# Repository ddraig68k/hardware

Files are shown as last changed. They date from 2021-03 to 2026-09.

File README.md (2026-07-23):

# CAD files for Y Ddraig

This repository contains the Schematics and any other relevant files for a [Motorola 68000 computer](https://ddraig68k.com) in KiCAD format. The files for the main computer boards as well as any of the expansion boards are present in the repository.

The libraries used in the project are contained in the ddraig-libs folder inside the repo, to use them in KiCAD, go to Configure Paths and add a custom path DDRAIGLIB which points to the ddraig-libs folder.

## Y Ddraig

Welsh for *The Dragon*, Y Ddraig is my [Motorola 68000](https://en.wikipedia.org/wiki/Motorola_68000) computer. 

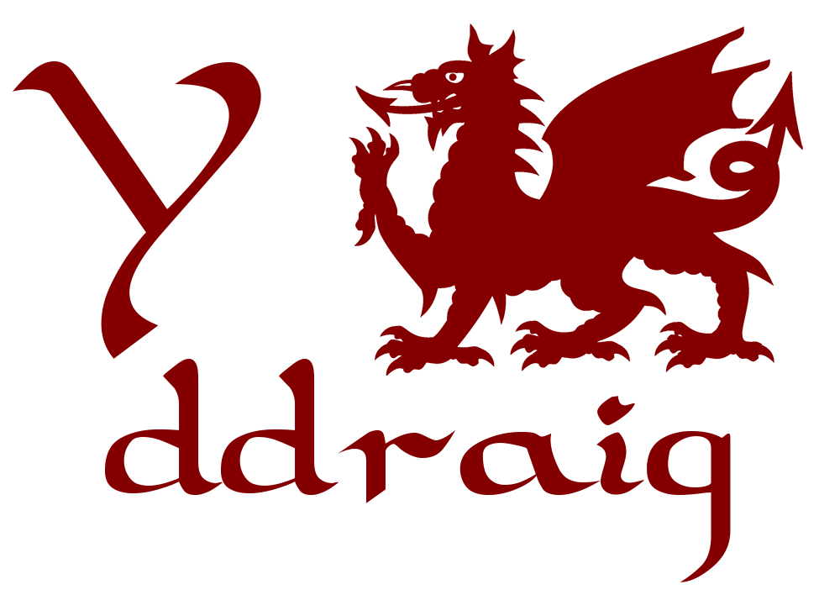
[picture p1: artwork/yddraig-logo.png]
Y Ddraig

| **Specifications** |
|-|
|68000 CPU running at 10Mhz.|
|512K EEPROM |
|1M of Static RAM|
|8M Dynamic RAM|
|2 Serial ports|
|Parallel port|
|PS/2 keyboard and mouse|
|IDE interface|
|Real-time clock|
|4 Expansion slots|

<br />

# Design Files
[Y Ddraig 68000 PCB](yddraig)

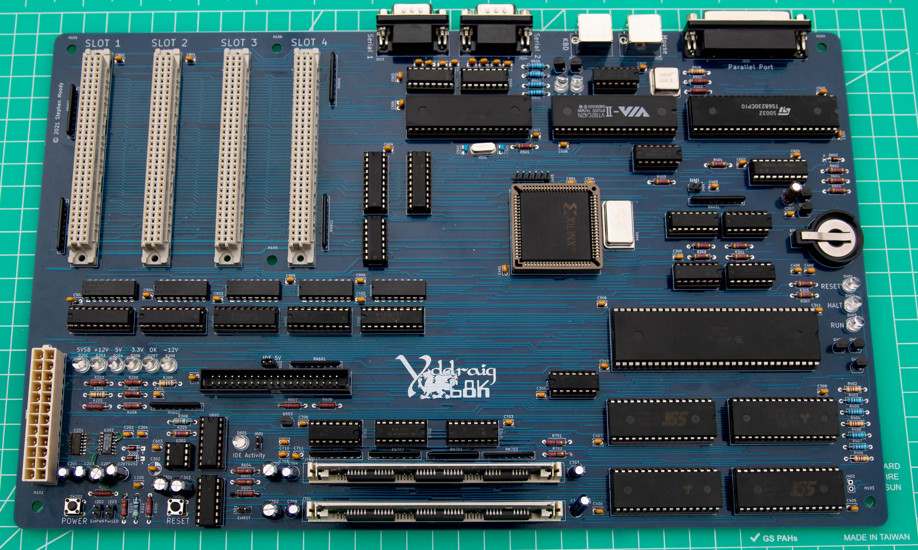
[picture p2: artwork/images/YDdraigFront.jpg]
Y Ddraig main pcb


**Expansion Cards**

* [Dual SID Audio card](expansion/AudioSID) - two MOS 6581/8580 SID chips for Commodore 64 style audio

* [YM2151 Audio card](expansion/AudioYM2151) - Yamaha FM synthesis chip as used in many arcade games

* [RTL8019 Ethernet card](expansion/Eth8019) - 10BASE-T Ethernet using the Realtek RTL8019AS

* [TMS9918 Graphics card](expansion/GfxTMS9918) - the video chip used in the Sega SG-1000, ColecoVision and MSX1

* [V9958 Graphics card](expansion/GfxV9958) - Yamaha's successor to the TMS9918, as used in the MSX2+

* [V9990 Graphics card](expansion/GfxV9990) - Yamaha's follow up to the V9958 with higher resolutions

* [VGA Graphics card](expansion/GfxVGA) - FPGA based VGA video generation

* [Sega Megadrive joypad card](expansion/JoypadController) - reads standard 3 or 6-button Sega Megadrive/Genesis controllers

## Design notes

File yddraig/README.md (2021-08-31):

## Y Ddraig hardware

### CPU, RAM and ROM

The CPU used by Y Ddraig is the [Motorola 68000](https://en.wikipedia.org/wiki/Motorola_68000) running at 10 MHz. The 68000 has a 16-bit data bus and 24-bit address bus internally runs as a full 32-bit machine. The 68000 has 8 general purpose data registers *D0-D7* and 8 address registers *A0-A7*. The address register A7 is also used as a special purpose register holding the *stack pointer*.

There is 512K of EEPROM available supplied by two 256K x 8-bit SST39SF020 devices for the ODD and EVEN addresses.

RAM is provided by two 512K x 8-bit AS6C4008 Static RAM devices giving a total of 1024K of available memory. There is also the option of adding an additional Dynamic RAM to expand the memory up to a total of 9MB.

### Memory Mapping

As the 68000 is a memory mapped device the address decoding is handled by a Xilinx XC95C108 CPLD. In addition to the address decoding the CPLD is also used as the DRAM controller.

The memory map is as follows:

| Device | Start Address | End Address |
|-|-|-|
| Static Ram | 0x000000 | 0x0FFFFF |
| Dynamic RAM | 0x100000 | 0x900000 |
| Slot1 Data | 0xA00000 | 0xAFFFFF |
| Slot2 Data | 0xB00000 | 0xBFFFFF |
| Slot3 Data | 0xC00000 | 0xCFFFFF |
| Slot4 Data | 0xD00000 | 0xDFFFFF |
| DUART | 0xF7F000 | 0xF7F0FF |
| PIT | 0xF7F100 | 0xF7F1FF |
| KBD | 0xF7F200 | 0xF7F2FF |
| IDE | 0xF7F300 | 0xF7F3FF |
| RTC | 0xF7F400 | 0xF7F4FF |
| Slot1 | 0xF7F500 | 0xF7F5FF |
| Slot2 | 0xF7F600 | 0xF7F6FF |
| Slot3 | 0xF7F700 | 0xF7F7FF |
| Slot4 | 0xF7F800 | 0xF7F8FF |
| ROM | 0xF80000 | 0xFFFFFF |

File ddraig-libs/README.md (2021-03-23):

# KiCAD Library files

Collections of library files for use in KiCad

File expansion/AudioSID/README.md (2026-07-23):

# Dual SID Audio Card

The [MOS 6581/8580 SID](https://en.wikipedia.org/wiki/MOS_Technology_SID) is the sound chip used in the Commodore 64, with 3 independent oscillators, multiple waveforms, ADSR envelopes and a multi-mode filter giving it its distinctive sound.

This card has two SID sockets, each jumper-selectable between the original 6581 and the later 8580 variant, since the two chips have different characteristics - the 8580 cleaned up some of the 6581's non-linearities and runs from a 9V analog supply rather than the 6581's 12V. The board provides both rails, with an L7809 regulator supplying the 9V needed by the 8580.

A Xilinx XC9536PC44 CPLD handles address decoding and chip select generation for both SID sockets. Each SID has its own volume potentiometer for mixing before the two channels are combined into a single audio output, with a separate analog supply and ground plane to help keep noise out of the signal.

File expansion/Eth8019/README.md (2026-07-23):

# RTL8019 Ethernet Card

The Realtek RTL8019AS is a fully integrated, single-chip [NE2000](https://en.wikipedia.org/wiki/NE2000)-compatible Ethernet controller with an 8/16-bit ISA-style bus interface and an integrated packet buffer, which makes it straightforward to attach to a simple non-DMA host bus like the 68000's.

A Xilinx XC9536PC44 CPLD provides the address decoding and glue logic between the expansion bus and the RTL8019AS, including the IOCS16B signalling used to negotiate 8/16-bit bus width with the host, as on ISA NE2000 cards.

The card has an RJ45 jack with integrated magnetics for the 10BASE-T connection, link/activity LEDs, and a JTAG header for programming the CPLD.

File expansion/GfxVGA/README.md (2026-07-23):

# VGA Graphics Card

Unlike the other graphics expansion cards, which are each built around a dedicated video chip from the 1980s/90s, this card generates video directly from a Xilinx Spartan-6 XC6SLX9-TQG144 FPGA, giving full control over the display timing and pixel generation logic instead of relying on a fixed-function chip.

An IS61WV102416FBLL 1M x 16-bit SRAM provides the frame/video memory for the FPGA. Configuration is loaded from a W25Q64JVSSIM SPI flash at power-up, so the board doesn't need to be reprogrammed each time it starts, though the FPGA can also be programmed directly over JTAG during development.

Since the FPGA core runs at a lower voltage than the rest of the board, an LD1117S12TR regulator supplies the 1.2V core rail, while buffer/level-shifting logic (74LS125, 74LS157, SN74LVC8T245) bridges the 3.3V FPGA I/O to the 5V expansion bus. Video is output through a standard DE15 VGA connector.

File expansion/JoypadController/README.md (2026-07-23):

# Sega Megadrive Joypad Card

This card provides two DB9 ports for connecting standard 3-button Sega Megadrive/Genesis joypads.

A Sega pad multiplexes its buttons across a handful of pins, switched by the SELECT line - reading Up/Down/Left/Right and its face buttons in two passes rather than needing a pin per button. Both the Left and Right lines being pulled low at the same time is how the host detects that a pad is actually connected to a port.

A Xilinx XC9536PC44 CPLD drives the SELECT line for both ports and latches the resulting button states through a 74LS574 octal latch so they can be read by the host as memory-mapped registers, with 74LS125 buffers isolating the pad inputs from the expansion bus. A JTAG header is provided for programming the CPLD.

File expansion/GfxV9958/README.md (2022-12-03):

# V9958 Video Card

The Yamaha V9958 is the successor to the V9938 and TMS9918 that were commonly used in the MSX computer line with the V9958 appearing in the MSX2+. 

It has the following specifications:
* VRAM: 128 KB + 64 KB of expanded VRAM
* Text modes: 80 x 24 and 32 x 24
* Resolution: 512 x 212 (16 colors out of 512) and 256 x 212 (19268 colors)
* Sprites: 32, 16 colors, max 8 per horizontal line
* Hardware acceleration for copy, line, fill, etc.
* Interlacing to double vertical resolution
* Horizontal and vertical scroll registers 

The board has 3 different outputs. A composite output, S-Video output and a [Xrgb Mini RGB](https://www.retrorgb.com/retro-gaming-cables-now-offering-8pin-minidin-scart-cables.html) compatible 8-pin mini DIN output aimed at SCART use. There is also an optional audio jack input that can supply audio the 8-pin din output so TV speakers can be used rather than an external speaker.

The V9958 board has 192K of RAM installed and uses a CXA2075M encoder to provide the video output signals. 

**V9958 Text Mode**
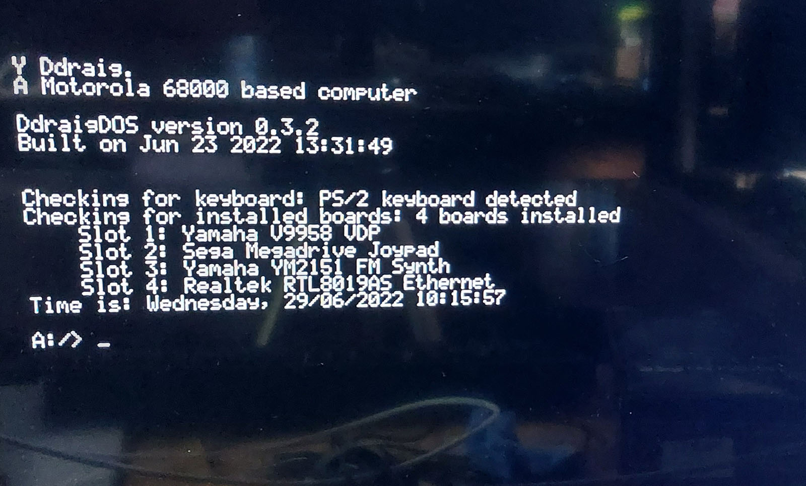
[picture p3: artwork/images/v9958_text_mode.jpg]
V9958 Text Mode


**V9958 Mandelbrot**
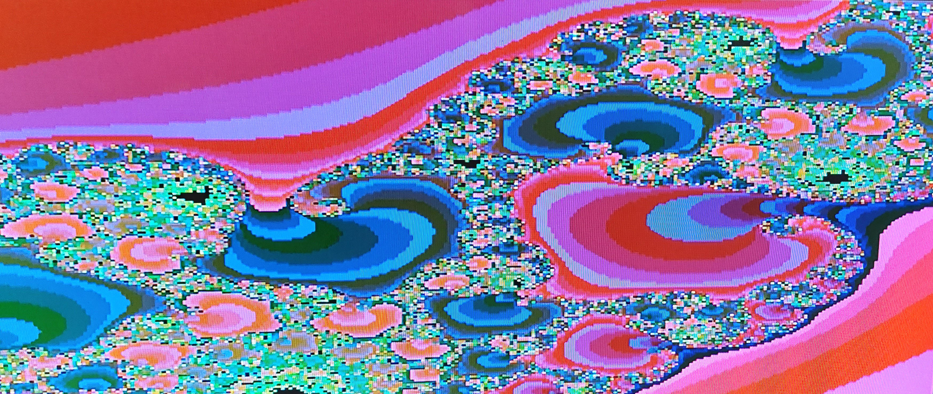
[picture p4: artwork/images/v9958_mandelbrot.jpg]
V9958 Mandelbrot


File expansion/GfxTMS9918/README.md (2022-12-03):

# TMS9918 Video card

The TMS9918A is capable of a 256x192 pixel display with a 15 colour palette. It has 16K of video memory and 4 different video modes.

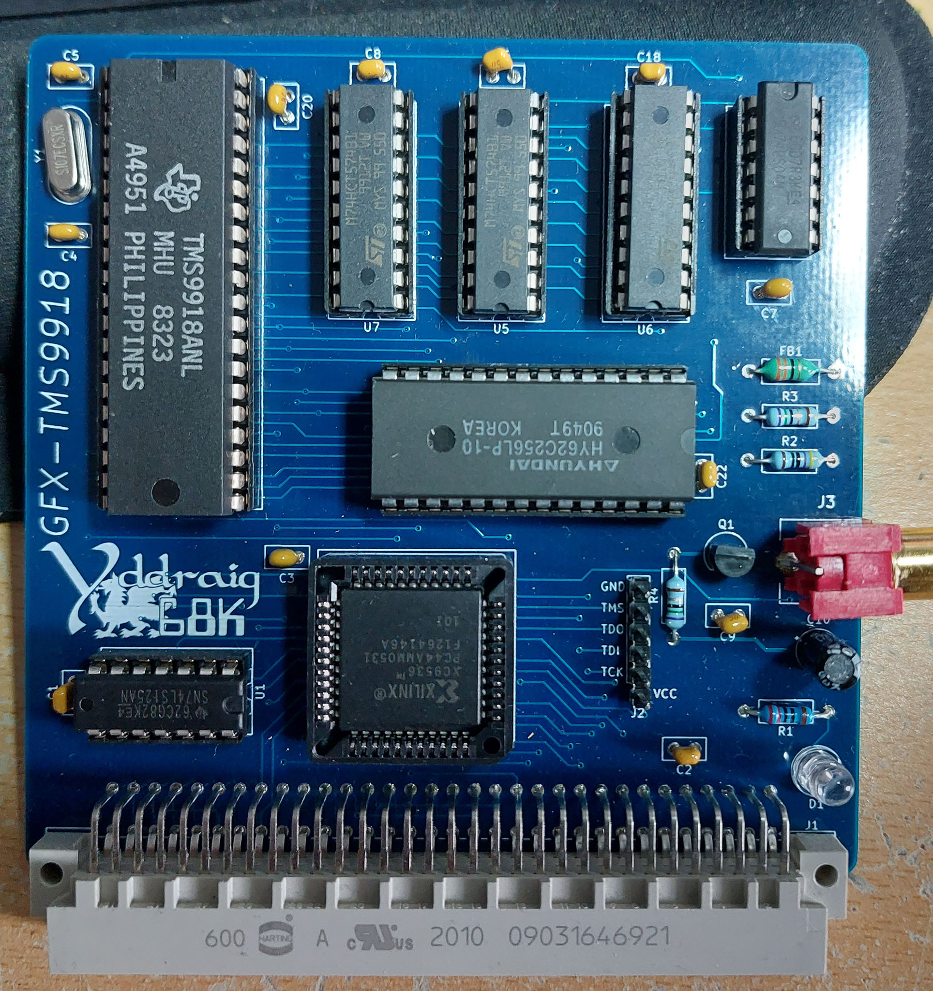
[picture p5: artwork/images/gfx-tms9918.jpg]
TMS9918 Video Card


From the [Sega Retro](https://segaretro.org/TMS9918) site:

>There are 4 different screen modes available in the TMS9918A (as mentioned before, the TMS9918 lacks mode Graphic II):
>
>Mode 0 (Text): 40×24 characters monochrome. As the display is 256 pixels width, the character set is only 6 pixels wide. This mode doesn't support sprites, nor a separate border color setting.
>
>Mode 1 (Graphic 1): 32×24 characters (256×192 bitmap), where for each 8 characters in the character set the foreground and background color can be set. The chars "0"-"7" for example all have the same attributes.
>
>Mode 2 (Graphic 2): 32×24 characters (256×192 bitmap), with a 2-color limitation for each 8 pixel wide line inside a character.
>
>Mode 3 (Multicolor): 64×48 mode, very blocky and rarely used. Each 'pixel' can have its own color defined though, hence the name. Its sprites still have the same resolution as in screen modes 1 and 2.
>
>The TMS9918 has a fixed 16-color palette (actually 15 colors + transparent). 

The TMS9918A was designed to use DRAM, but I have used the design by [Leonardo Miliani](https://www.leonardomiliani.com/en/2019/lm80c-tms9918a/) that allows SRAM to be used instead.

The TMS9918 can also display up to 32 sprites (4 per scanline).

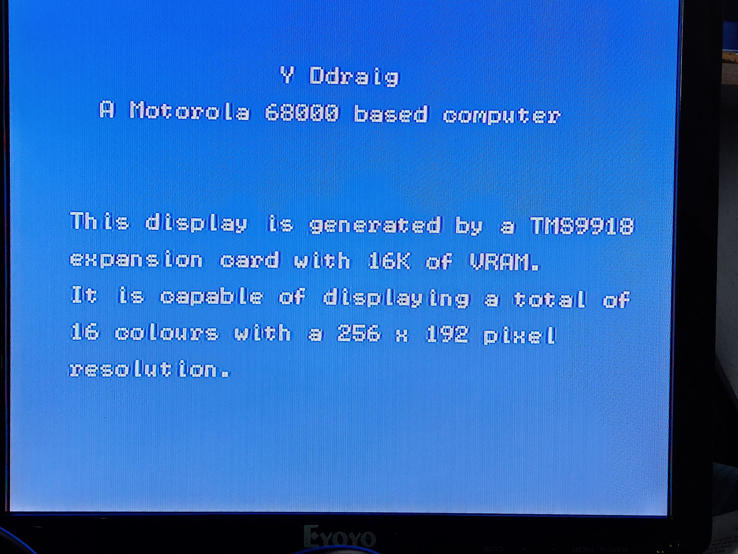
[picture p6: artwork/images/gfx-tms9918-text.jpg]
TMS9918 text mode


[Plasma effect on the TMS9918](https://www.youtube.com/watch?v=u6DVTGFEivY)

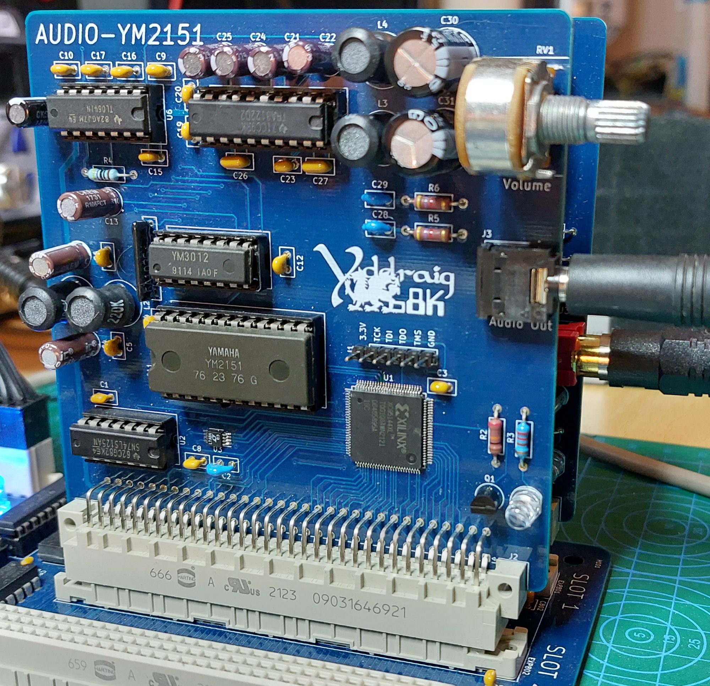
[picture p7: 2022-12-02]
artwork/images/YM2151Card.jpg

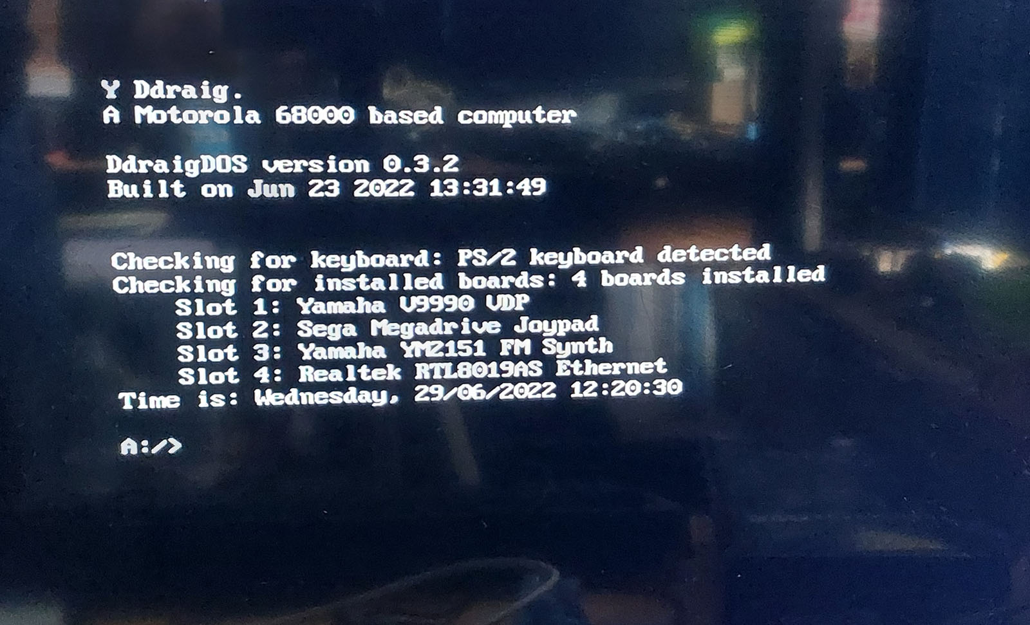
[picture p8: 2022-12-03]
artwork/images/v9990_text_mode.jpg

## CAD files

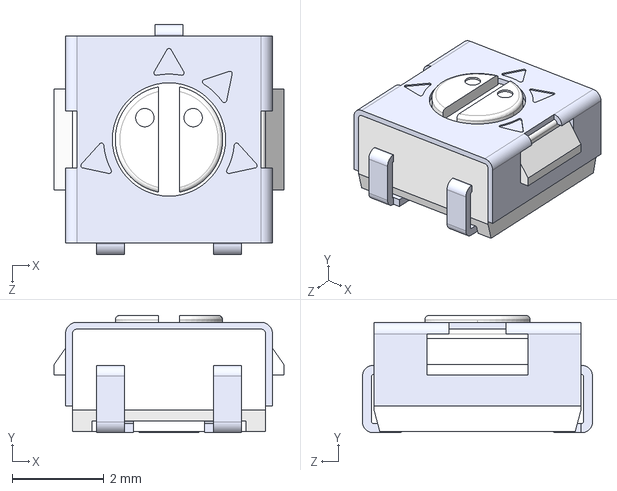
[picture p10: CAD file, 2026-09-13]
ddraig-libs/CAD/Components/3314J-1-202E.step
5.00 x 2.55 x 5.00 mm

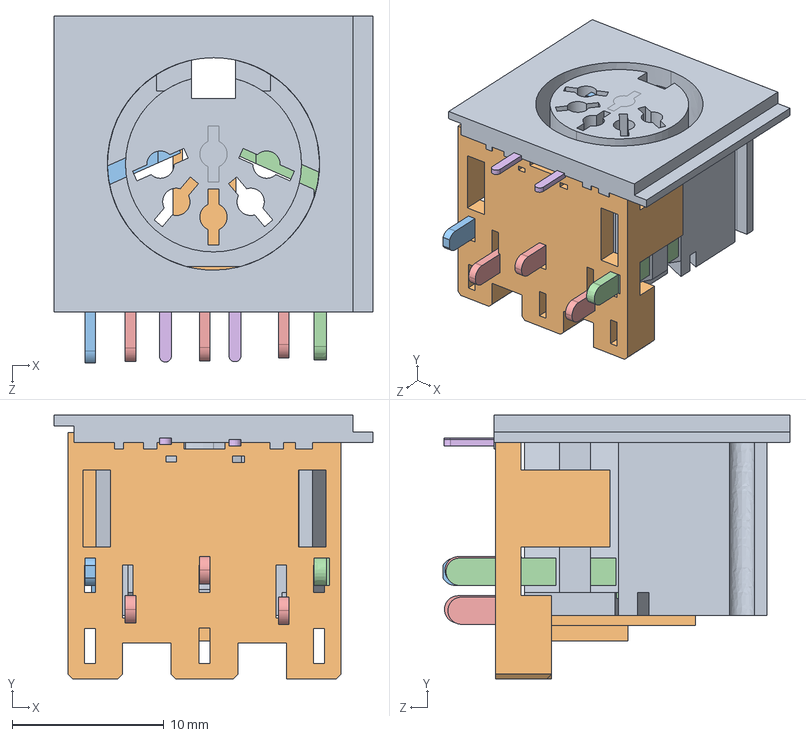
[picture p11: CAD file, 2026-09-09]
ddraig-libs/CAD/Connectors/lumberg_0105_05.stp
21.0 x 17.4 x 22.9 mm
PRT0017
PRT0018
PRT0019
PRT0020
PRT0021
PRT0022
PRT0022_1
PRT0023
PRT0024

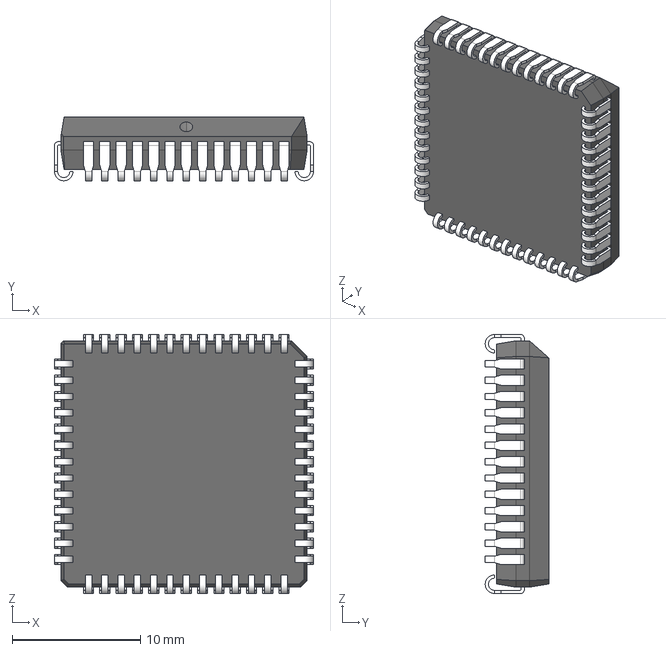
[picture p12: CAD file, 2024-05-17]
ddraig-libs/CAD/IC Sockets/plcc52_p1-27_l19-2_w19-2.stp
20.2 x 4.96 x 20.2 mm

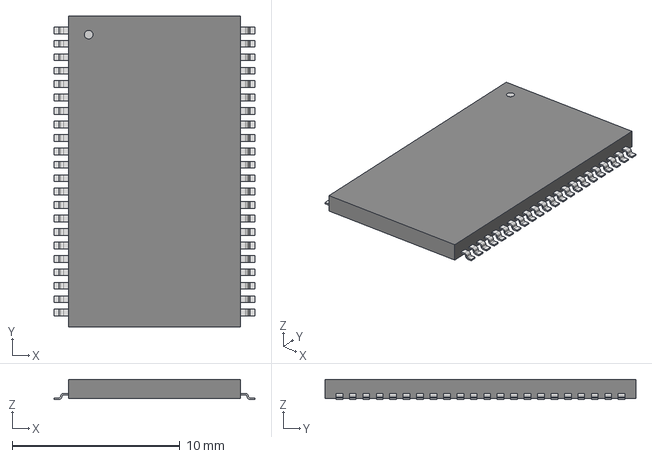
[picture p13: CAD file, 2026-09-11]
ddraig-libs/CAD/ICs/TSOP-44.step
11.9 x 18.5 x 1.20 mm

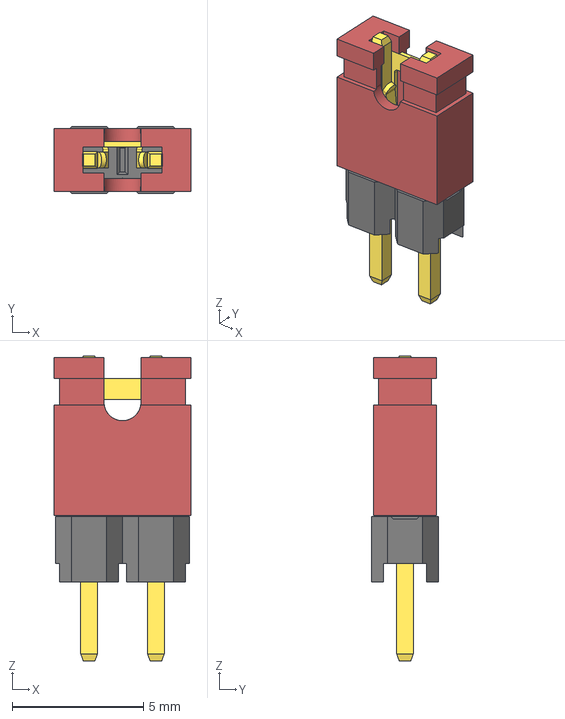
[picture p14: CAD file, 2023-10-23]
ddraig-libs/CAD/Jumpers/Jumper2-red.step
5.20 x 2.54 x 11.6 mm

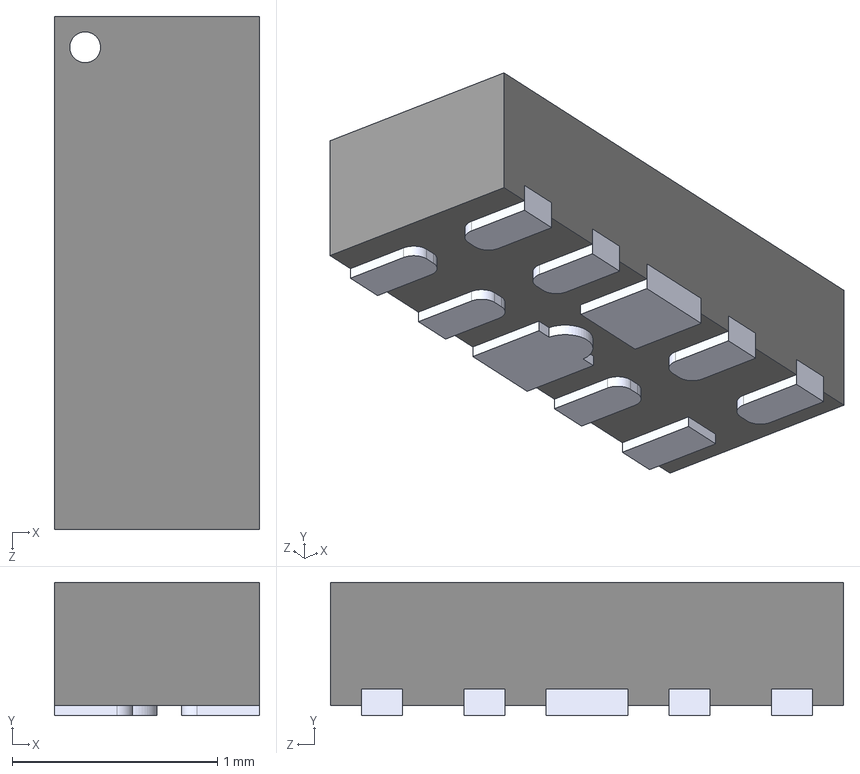
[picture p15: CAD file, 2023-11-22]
ddraig-libs/CAD/Components/RCLAMP0524PATCT.step
1.00 x 0.65 x 2.50 mm

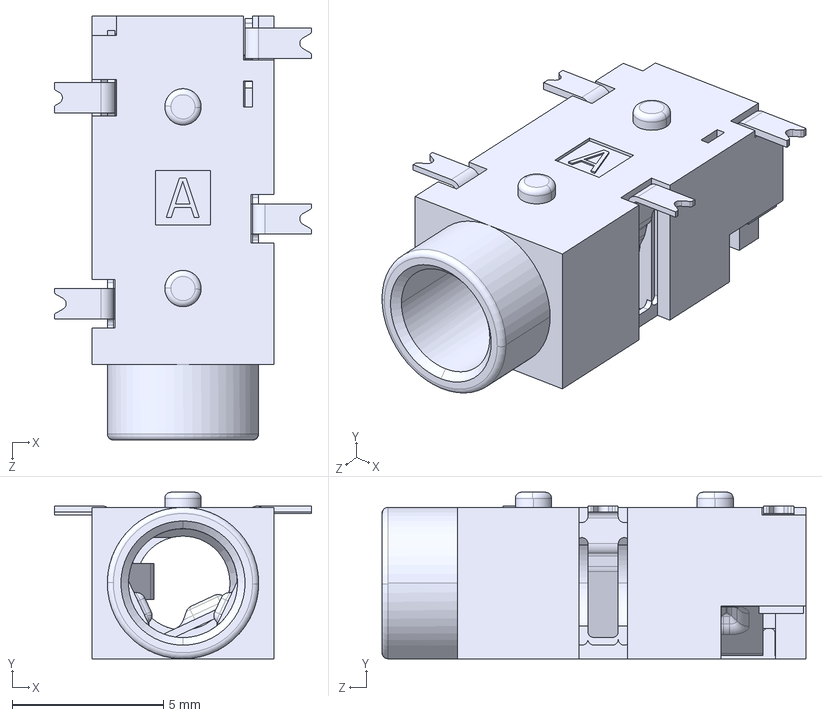
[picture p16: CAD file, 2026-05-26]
ddraig-libs/CAD/Connectors/SJ2-35813B-SMT-TR.step
8.50 x 5.50 x 14.0 mm

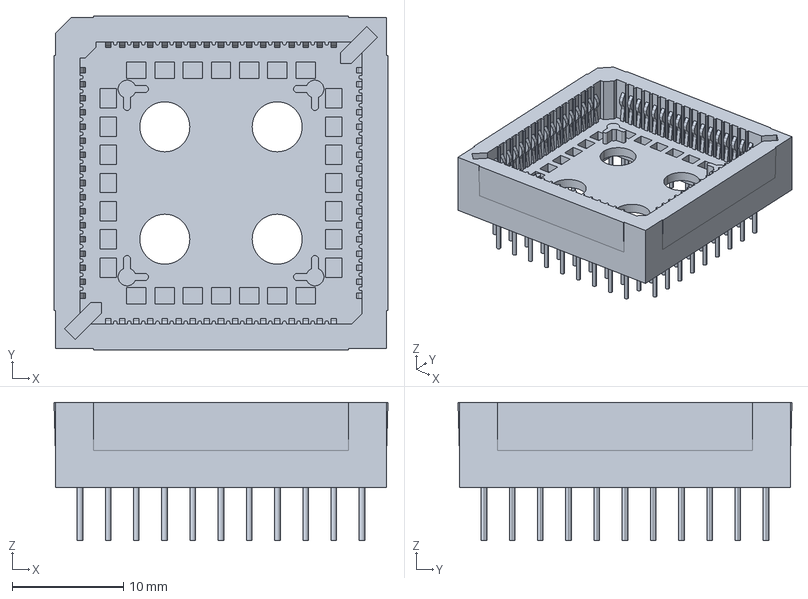
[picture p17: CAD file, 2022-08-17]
ddraig-libs/CAD/IC Sockets/PLCC68 Socket.stp
30.1 x 30.1 x 12.4 mm

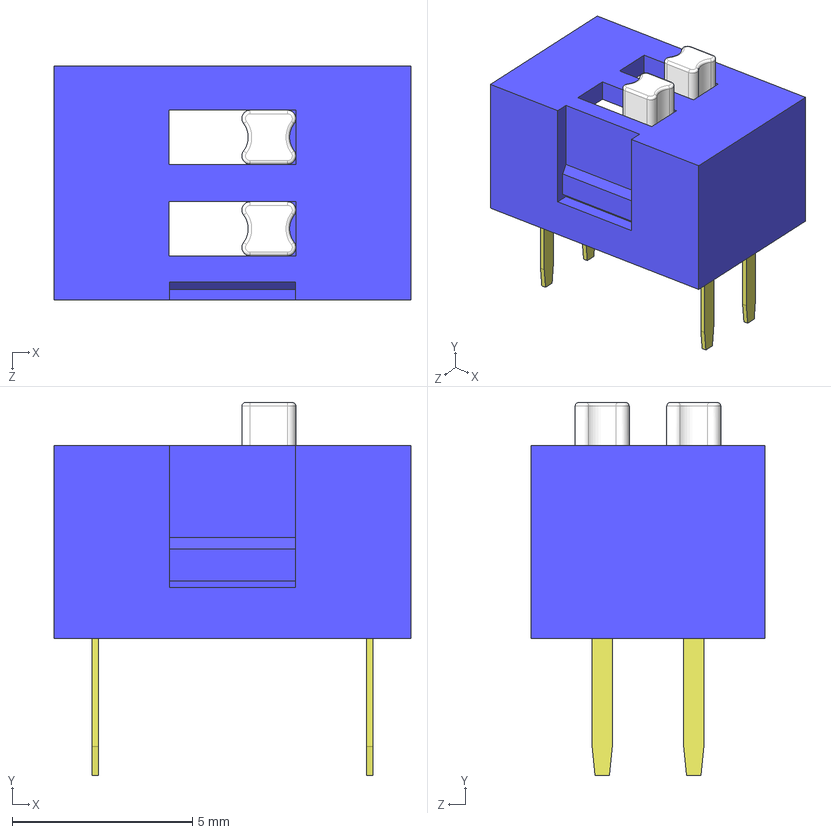
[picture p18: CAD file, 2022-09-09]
ddraig-libs/CAD/Components/CUI_DEVICES_DS01-254-L-02BE.step
9.90 x 10.4 x 6.50 mm

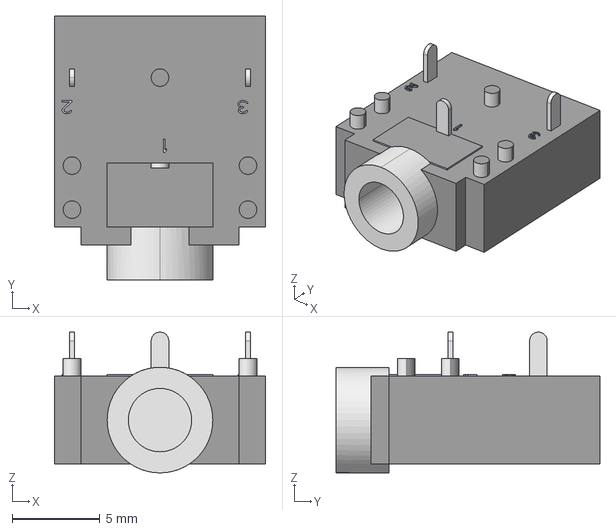
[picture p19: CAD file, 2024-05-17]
ddraig-libs/CAD/Connectors/35RAPC2BHN2.step
12.0 x 15.0 x 8.00 mm

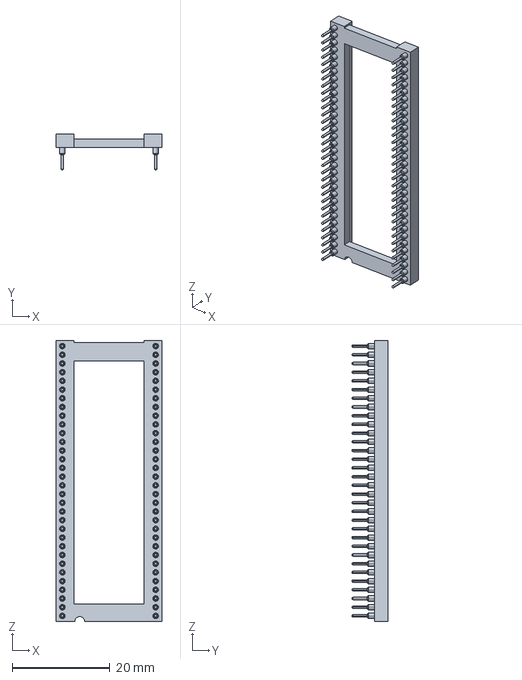
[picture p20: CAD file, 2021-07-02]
ddraig-libs/CAD/IC Sockets/dil_socket_117-87-764-41-005101.stp
21.6 x 7.40 x 57.4 mm

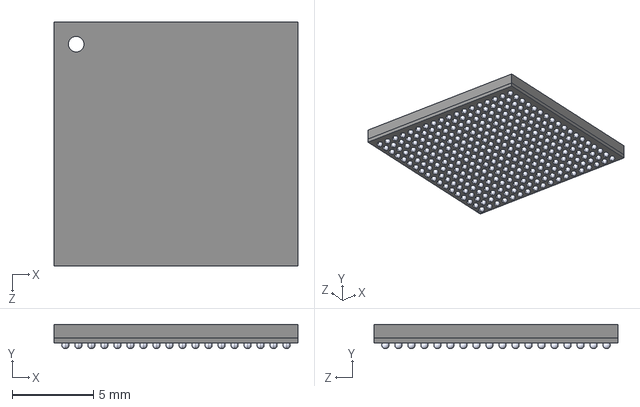
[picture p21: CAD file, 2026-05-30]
ddraig-libs/CAD/ICs/XC7S50-1CSGA324Q.STEP
15.0 x 1.50 x 15.0 mm

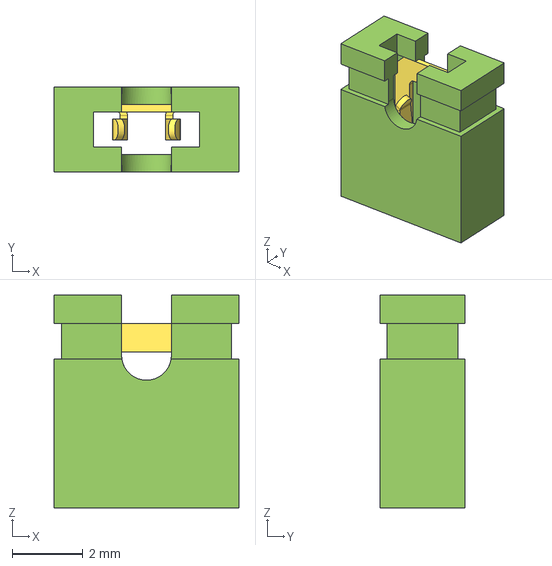
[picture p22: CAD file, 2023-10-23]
ddraig-libs/CAD/Jumpers/Jumper-green.step
5.20 x 2.40 x 6.00 mm

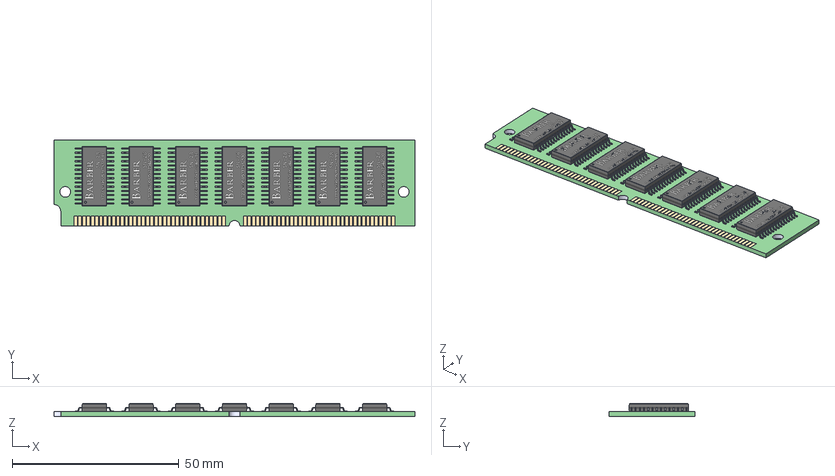
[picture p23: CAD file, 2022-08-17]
ddraig-libs/CAD/Components/72pin-simm.step
108.2 x 25.7 x 3.76 mm
simmbody
simmpin x 72
sn28body x 7
sn28pin x 196

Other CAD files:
ddraig-libs/CAD/Jumpers/Jumper2-yellow.step
ddraig-libs/CAD/Connectors/35RAPC4BHN2.step
ddraig-libs/CAD/IC Sockets/plcc44_p1-27_l16-66_w16-66.stp
ddraig-libs/CAD/Jumpers/Jumper3-yellow.step
ddraig-libs/CAD/Components/3306F001.stp
ddraig-libs/CAD/Components/ACH.STEP
ddraig-libs/CAD/Components/AIUR-02H.STEP
ddraig-libs/CAD/Components/AIUR-16.STEP
ddraig-libs/CAD/Components/AOCJY1.STEP
ddraig-libs/CAD/Components/DOUBLE POTENTIOMETER.stp
ddraig-libs/CAD/Components/ECS-3963-BN-TR.step
ddraig-libs/CAD/Components/IS61WV102416FBLL-10TLI.stp
ddraig-libs/CAD/Components/M2022TXW41-DA.stp
ddraig-libs/CAD/Components/MAX3420EECJ_.step
ddraig-libs/CAD/Components/SN74LVC8T245PWR.step
ddraig-libs/CAD/Components/SOT230P700X180-4N.step
ddraig-libs/CAD/Components/XTAL2.STEP
ddraig-libs/CAD/Connectors/145638009211859_.step
ddraig-libs/CAD/Connectors/57PC5F.step
ddraig-libs/CAD/Connectors/5822021-4.stp
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

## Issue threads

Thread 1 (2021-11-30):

PCB for sale?

bzuidgeest, 2021-11-30:
Much of this looks excellent to me. Still have to look at the details, but ticks many boxes, easy expansion, dram and simms mostly of the shelf chips for serial and such, cpu with excellent gcc support. etc

Could you give an indication as to what the component cost is? Does not need be exact. And though I should be able to copy this from repo and order everything myself I thought I could ask if you have PCB's for sale.

ddraig68k, 2021-11-30:
I don't have any boards for sale at the moment, there was a few mistakes on the PCB which have been resolved in the design, with the exception of issue #2 but I don't have any of the boards with fixes on them made yet.

It's hard to say what the component costs are. Many of the parts have been reused from previous boards or it's parts that I had here anyway.

The cost of the PCB is approximately $80 for 5 on JLCPCB.  Because everything socketed, it's probably around $150 spent on parts other than the old parts like the 68000 and other devices, most of which were from UTSource. I'll try to put a more detailed BOM together when I get a chance.

bzuidgeest, 2021-12-01:
No problem, if you could push any fixes made into the kicad drawings/pcb in the repo.
I could have my own made. And yes I know the risks in doing that :). I know this is not a commercial product. Or if your planning to order in the near future I could exercise some patience.

I'm trying to find a board with the right balance of retro, convenience, openness (and yes price) to fit my needs of wanting to toy with some of the old retro chips without any OS in the way. Tried the c256Foenix. Nice board, but all fpga and those are closed source, everything and the kitchen sink build in and expensive. Build an rosco-m68K next. Open, but to simple.. Yours seems to fall in between. And you already have an impressive set of add on boards. (that are at least in testing). But the four slots make tinkering easy.

ddraig68k, 2021-12-01:
The incorrect DTACK on the expansion bus has been fixed and the latest files are in the repo now.

I will probably order some new PCBs at some point as it would be nice to have a final board built up with all the fixes on there. I need to check out all the expansion boards as well before ordering new so it may not be until after that point.

The original version of the computer I did was a single board design with everything on it. The main reason I changed the design to use the expansion slots instead was to allow tinkering with different designs. I like being able to try some of the old graphics and sound chips of old computer systems and this computer allows be to do just that.

bzuidgeest, 2021-12-01:
"The main reason I changed the design to use the expansion slots instead was to allow tinkering with different designs."

The main reason for me to look at a project like this. Closed source fpga on sbc's are just annoying. Not that I know much about vhdl, but I should at least be able to tinker with them.

I'm closing this for now. Thanks for pushing the latest files.

Closed 2021-12-01.

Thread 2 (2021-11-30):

Possible error in schematic

bzuidgeest, 2021-11-30:
This might be old news to you but when looking at the published schematics for expansion slot 4 I noticed that DTACK_EXT4 is connected to the IRQ pin on slot 4. I read that interrupt on slot 4 is not supported. By the looks of it because you ran out of room on the encoder. However that does not give me a reason to connect dtack to the IRQ pin, so for the moment I am assuming that is an error. Do correct me if I am wrong.

ddraig68k, 2021-11-30:
That is an error, DTACK_EXT4 should not be connected to the IRQ slot. Thanks, missed that and not tested any boards in slot 4 yet so haven't noticed it. I'll get that one fixed.

You're correct about the lack of IRQ on slot 4, there wasn't a spare IRQ on the encoder. I had considered putting a shared IRQ on slots 3 and 4, but decided against it.

Closed 2021-12-01.

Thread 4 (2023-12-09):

Schematic label typo  DATCK_EXT should be DTACK_EXT on U402B pin 5

vermeerpaul, 2023-12-09:
A possible disconnect of PIN 5 U402B DTACK_EXT. See file Schematic yddraig-schematic.pdf.
It has a typo in the label.

vermeerpaul, 2023-12-09:
Seems to be resolved 1-level up on the sheet connection. DTACK <->DATCK.

Closed 2023-12-09.

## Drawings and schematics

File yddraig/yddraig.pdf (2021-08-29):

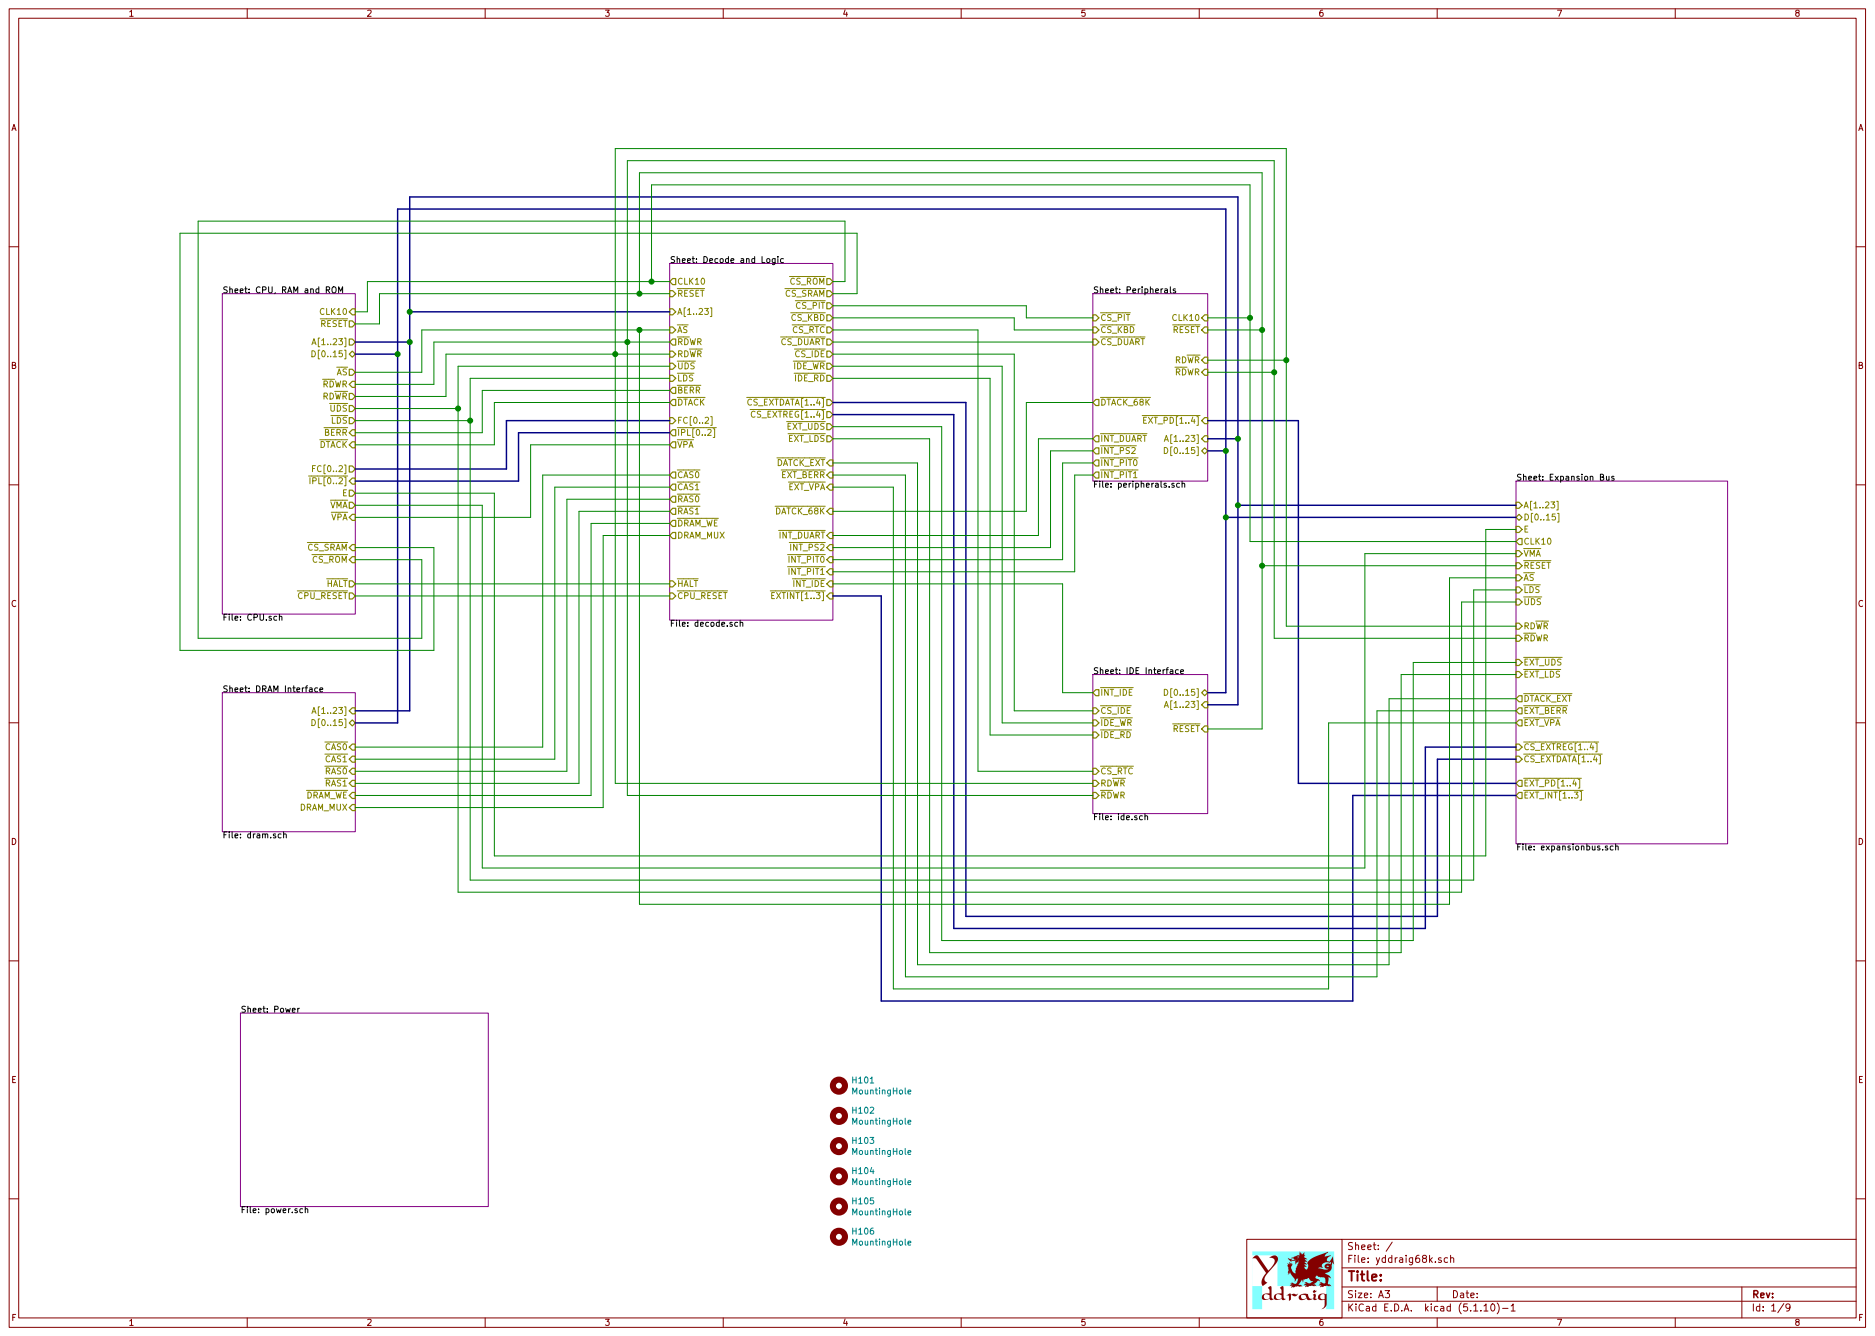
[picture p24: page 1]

Sheet: Decode and Logic File: decode.sch CLK10 RESET A[1..23] ASRDWR

Sheet: CPU, RAM and ROM
CLK10 VPA RESET CS_SRAM
DTACK HALT CPU_RESET RDWR
LDS RDWR

Sheet: Expansion Bus
A[1..23] VMA
File: expansionbus.sch DTACK_EXT D[0..15] CLK10 RESET AS
EXT_VPA E

INT_PIT1 Sheet: Power File: power.sch

H106 MountingHole H105 MountingHole H104 MountingHole H103 MountingHole H102 MountingHole H101 MountingHole

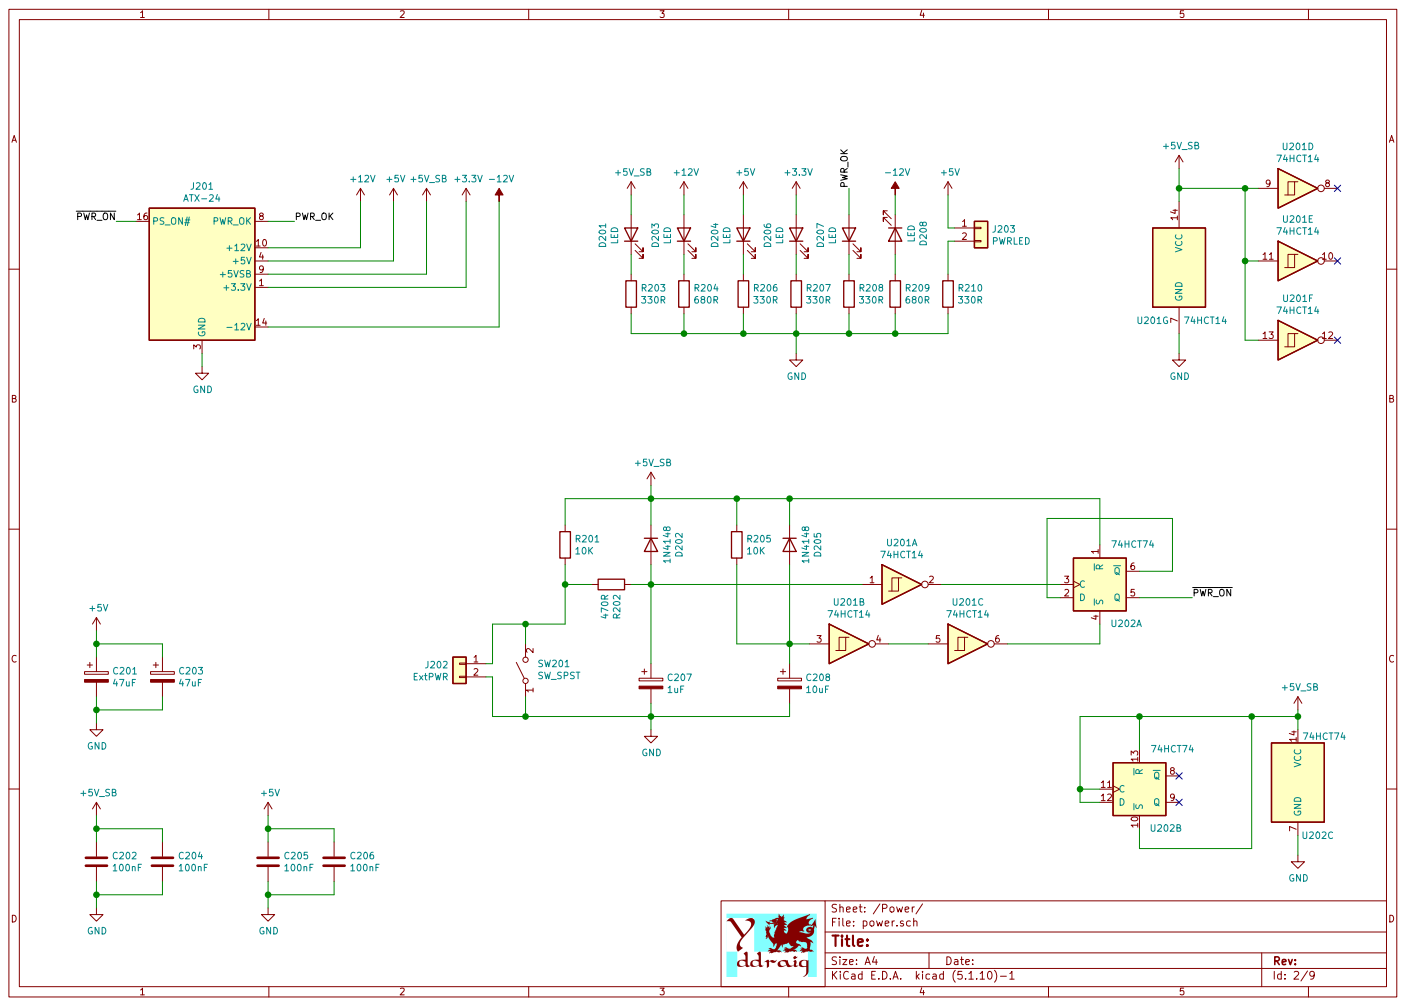
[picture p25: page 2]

File: power.sch Sheet: /Power/
Id: 2/9 Title:

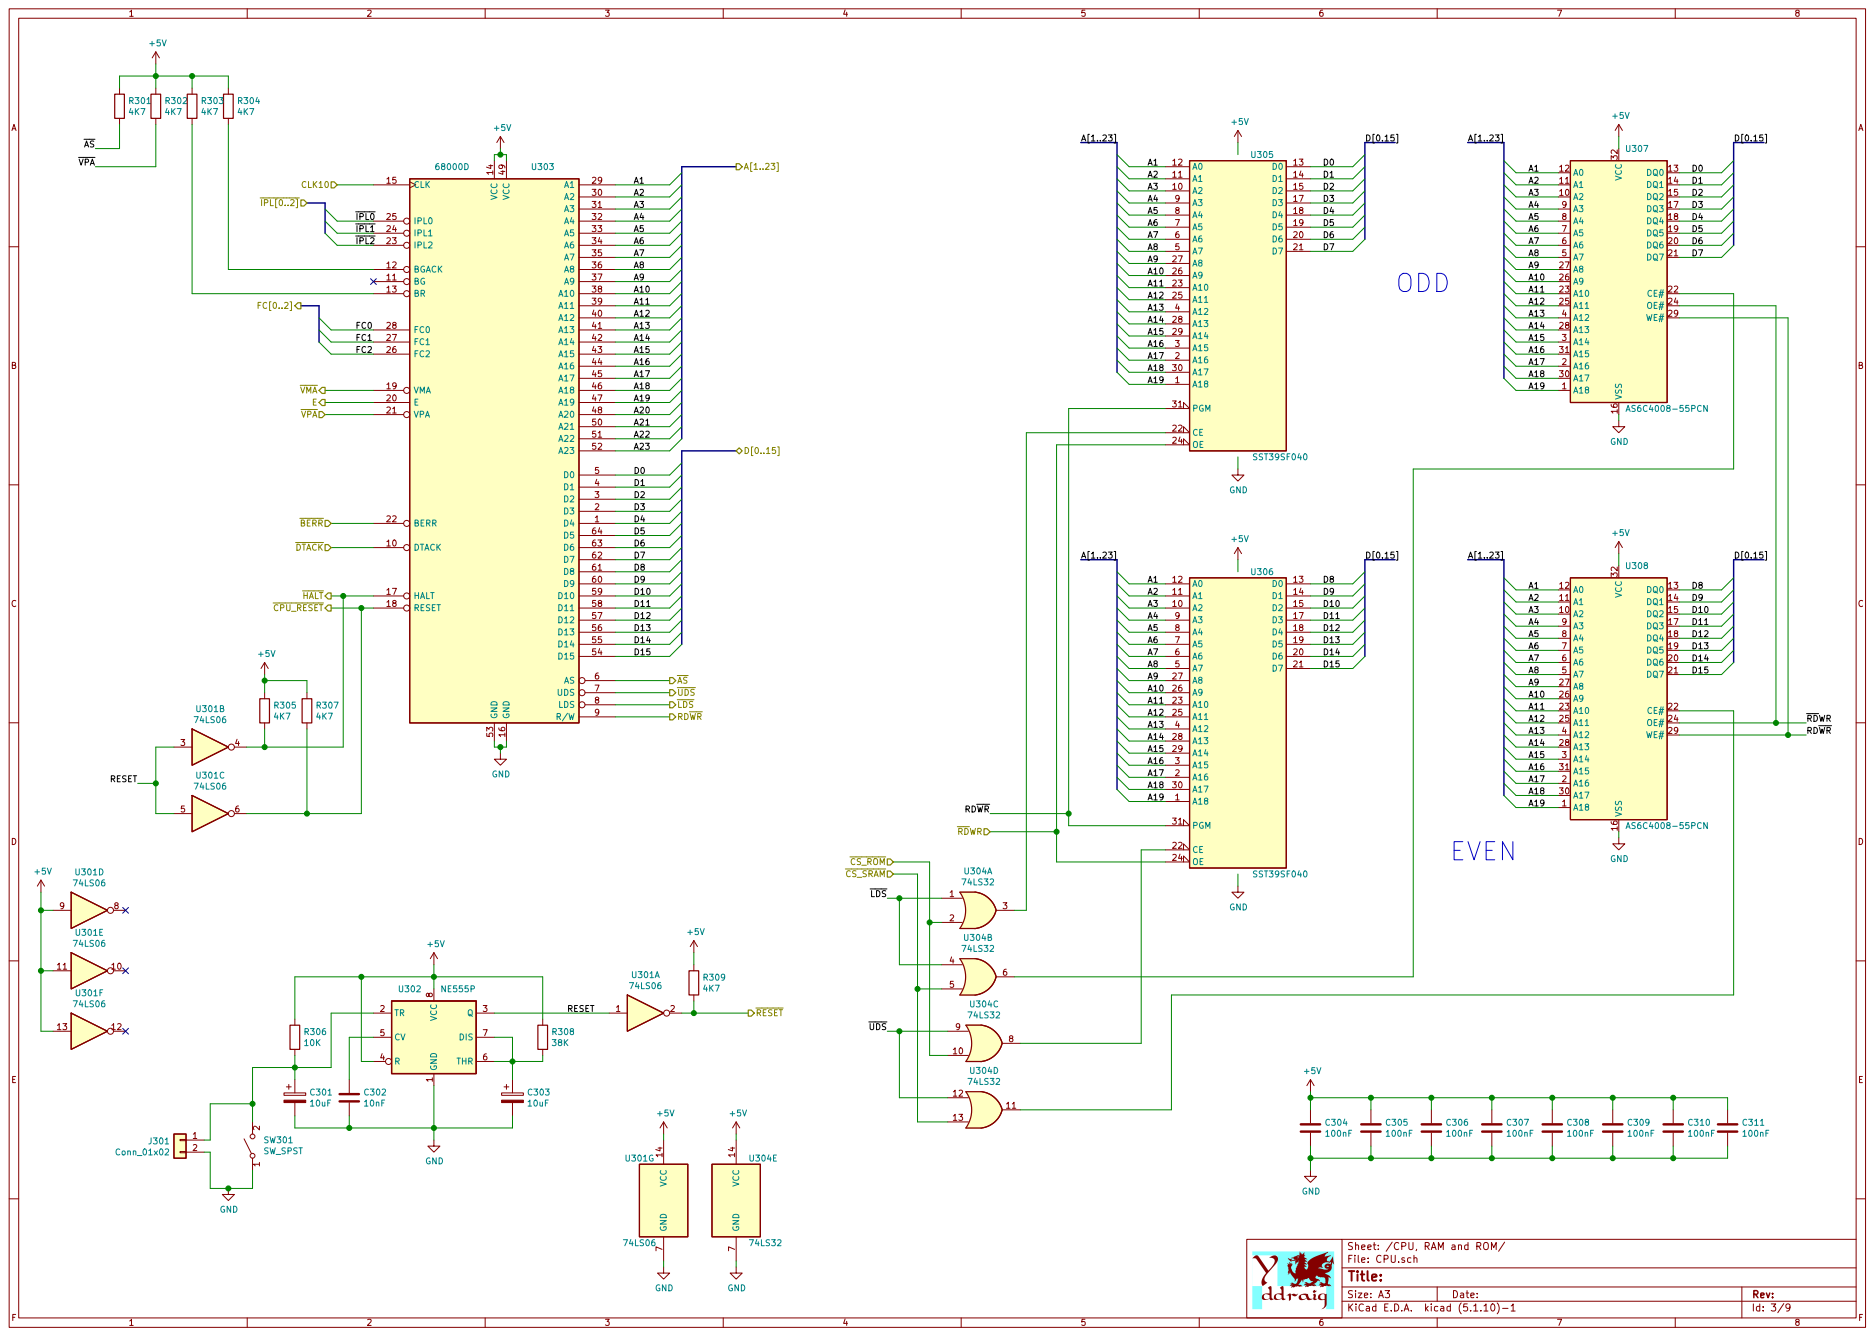
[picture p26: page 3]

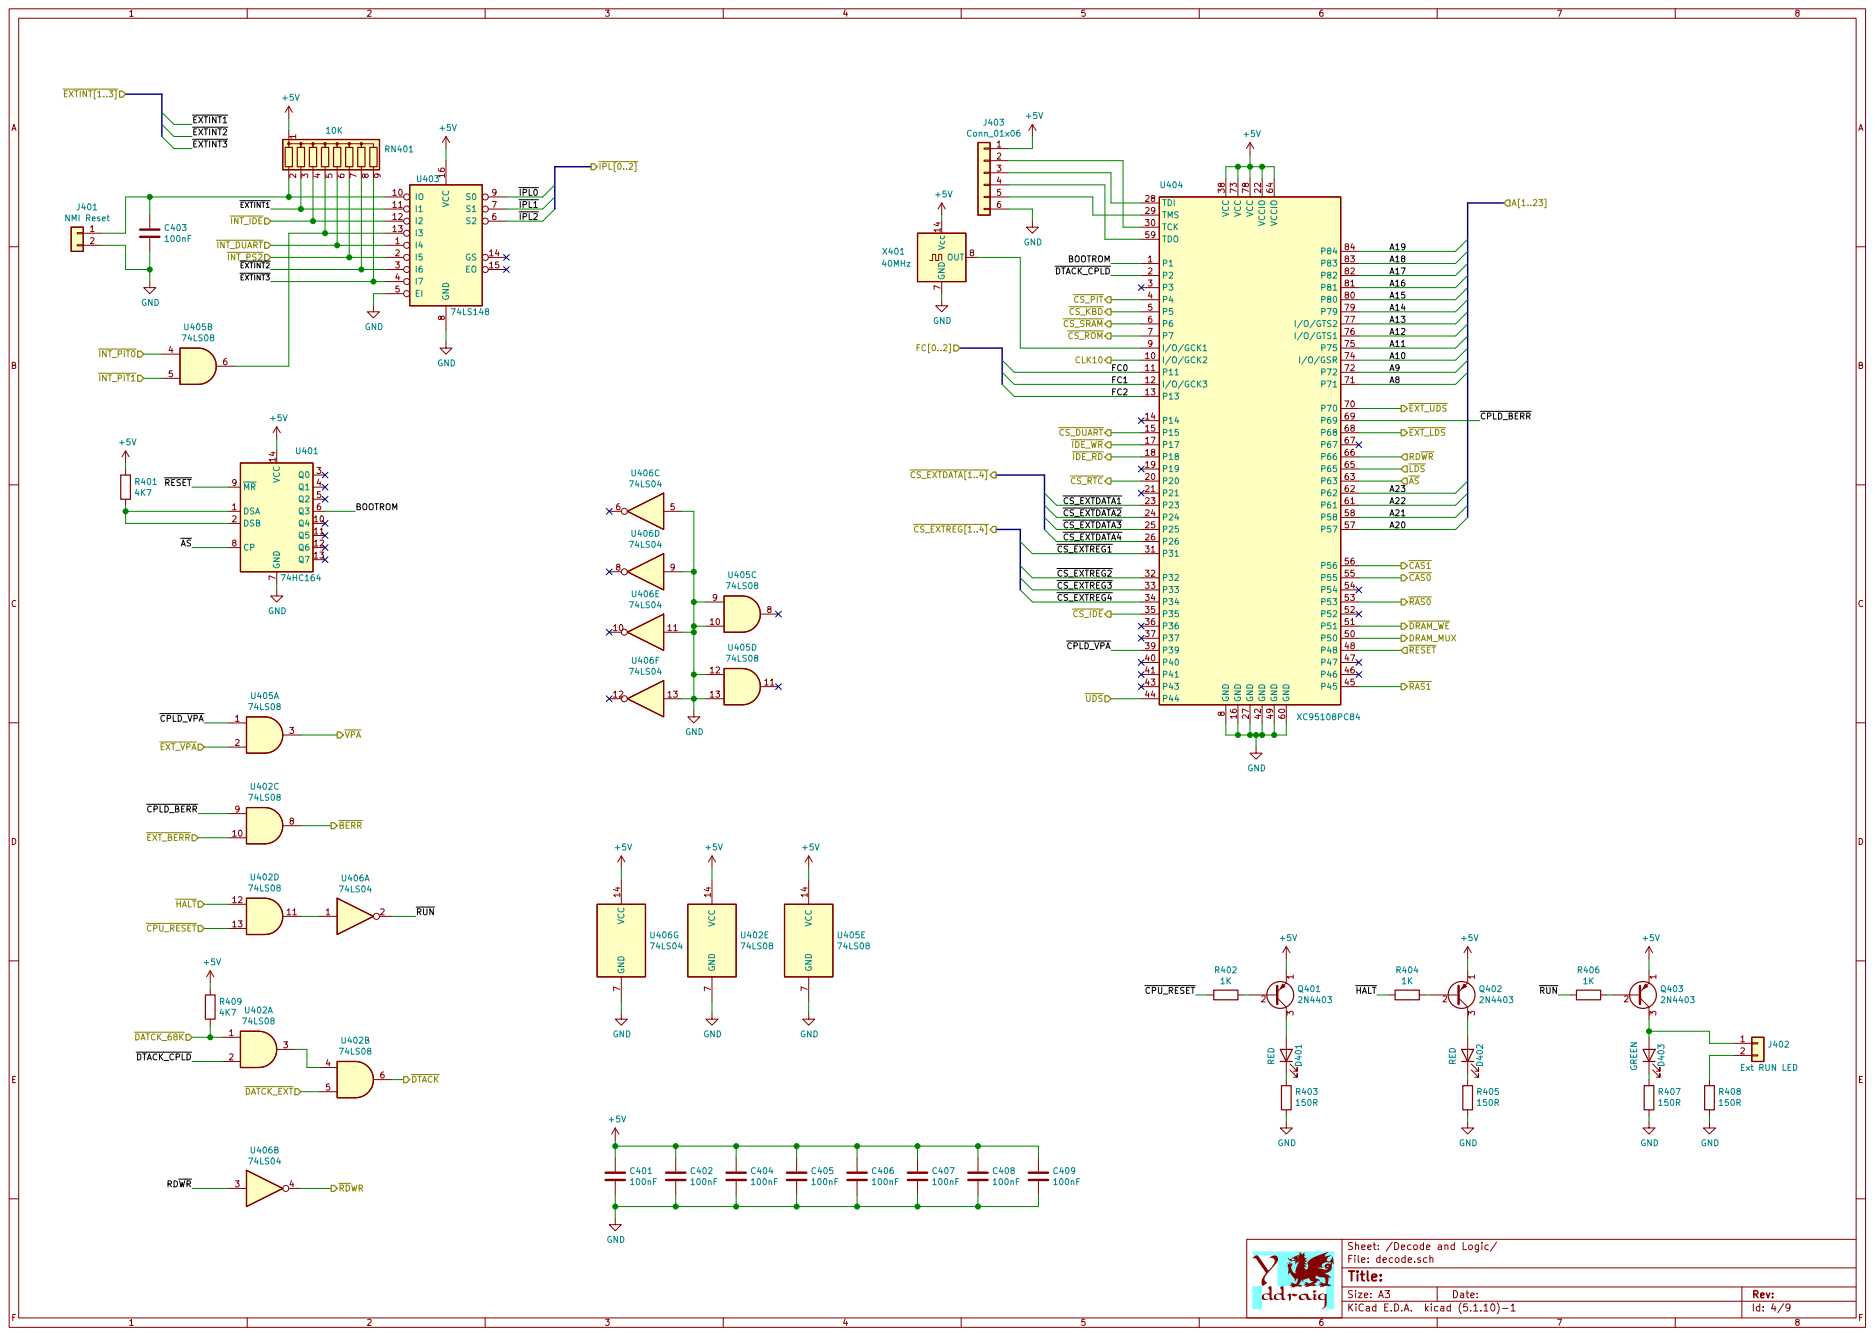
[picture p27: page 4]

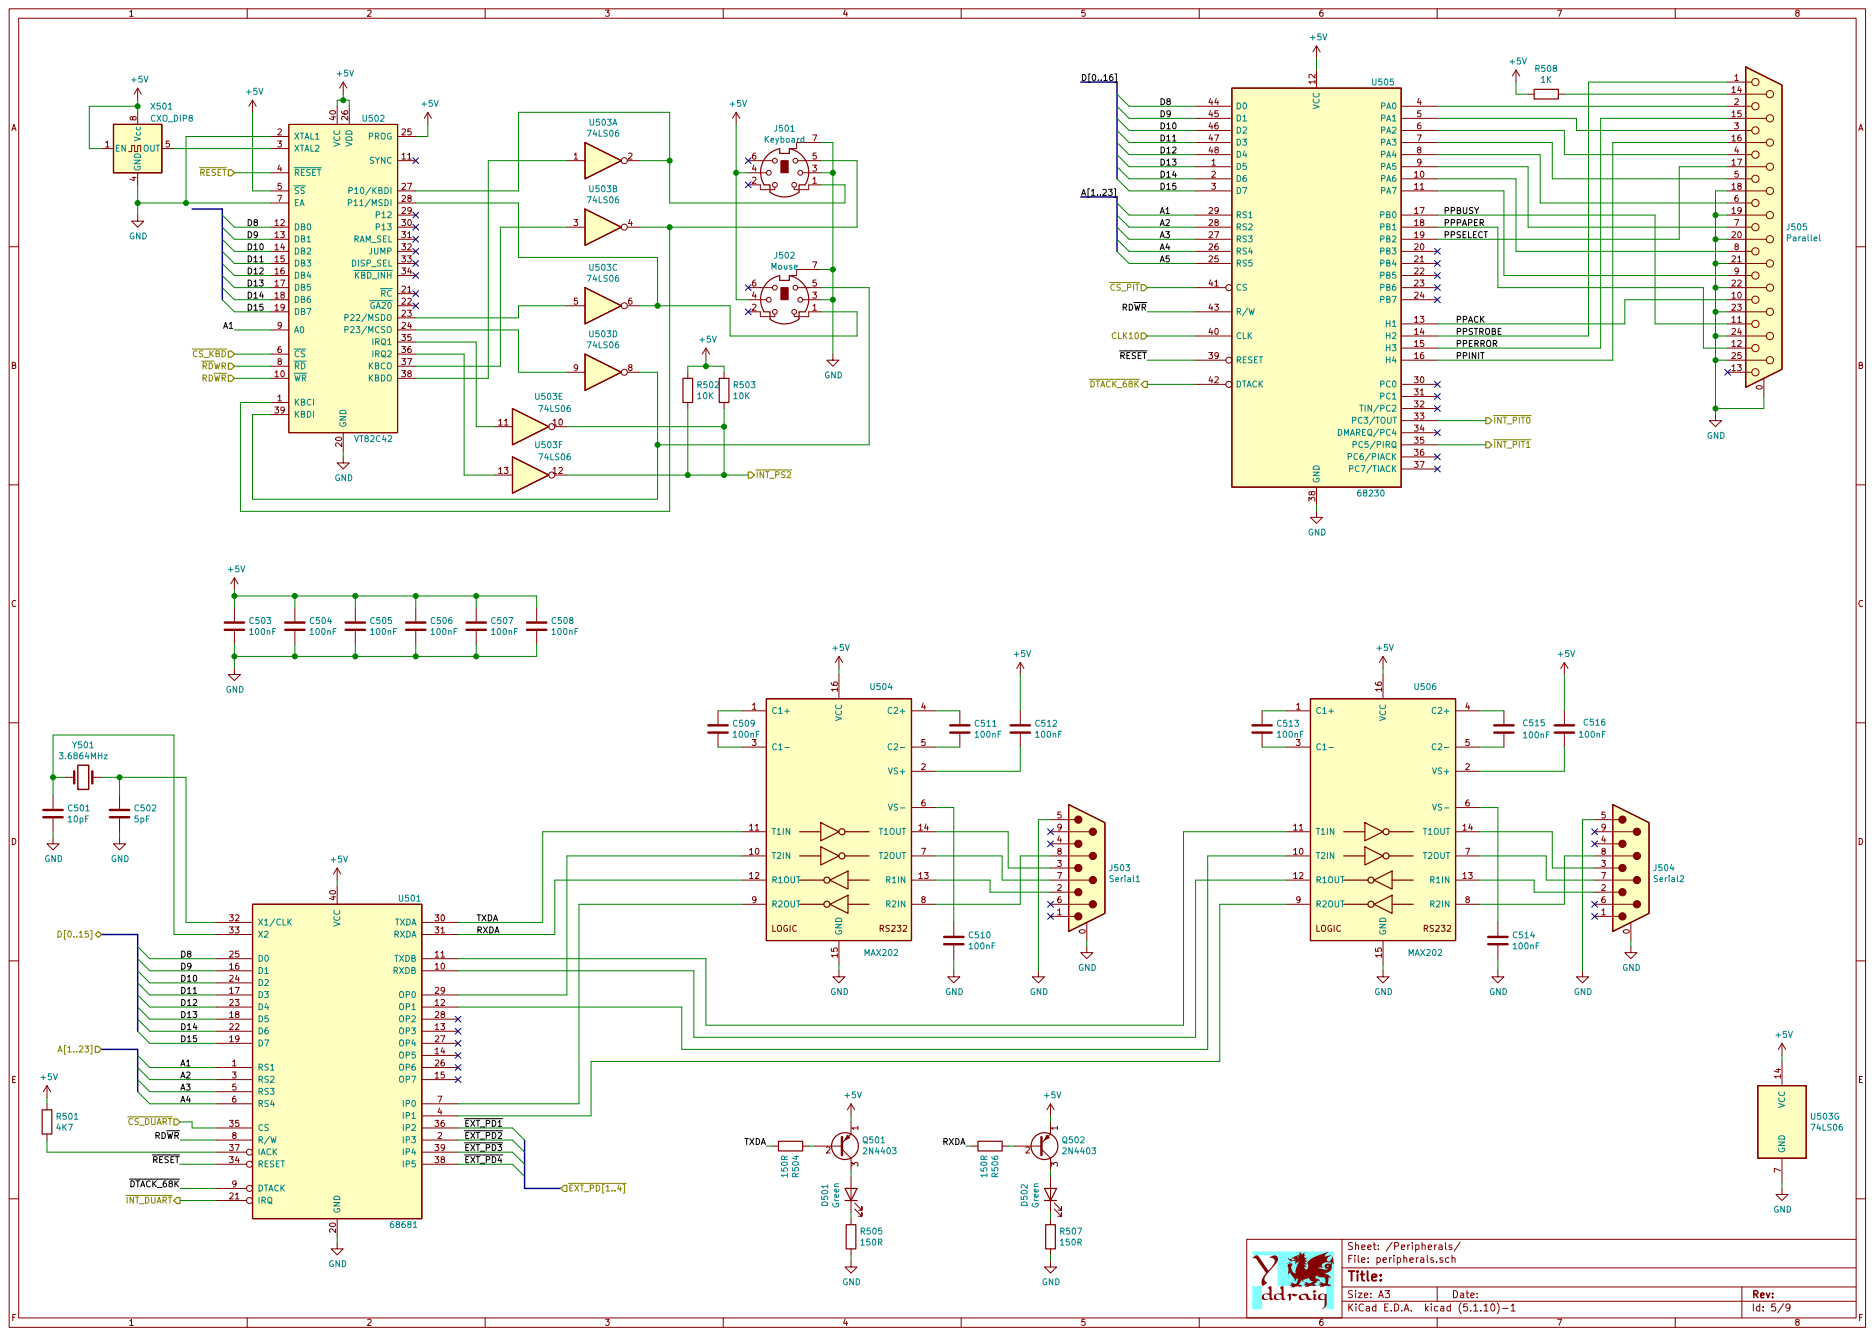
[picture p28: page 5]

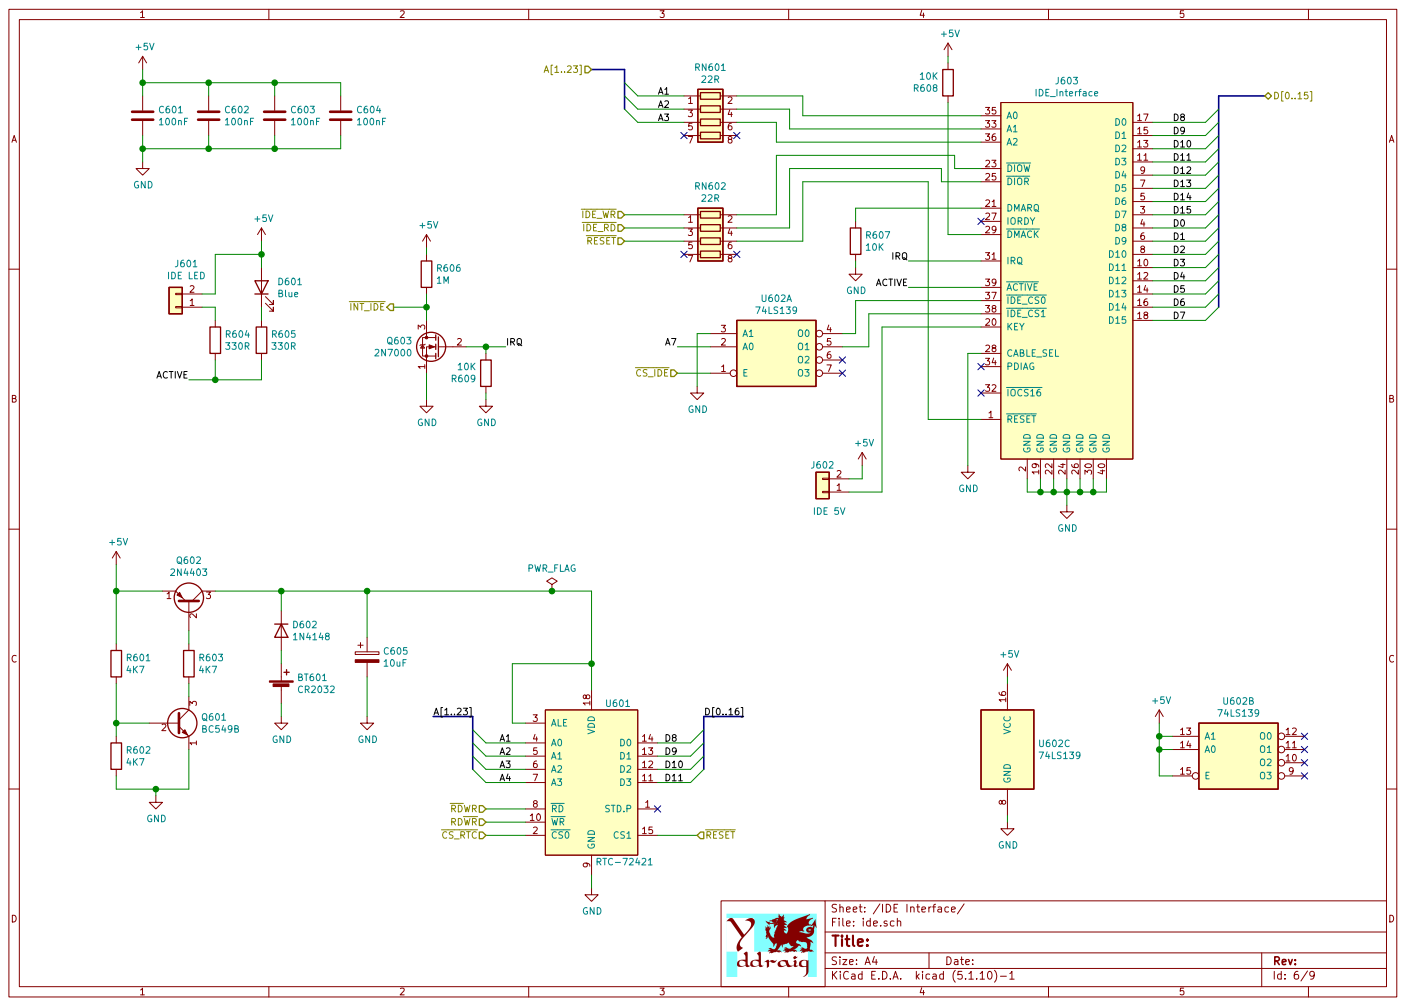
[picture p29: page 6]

2 KEY 20 DMARQ 21 GND 22 DIOW 23 GND 24 DIOR 25 GND 26

Id: 6/9 Title: File: ide.sch Sheet: /IDE Interface/ GND

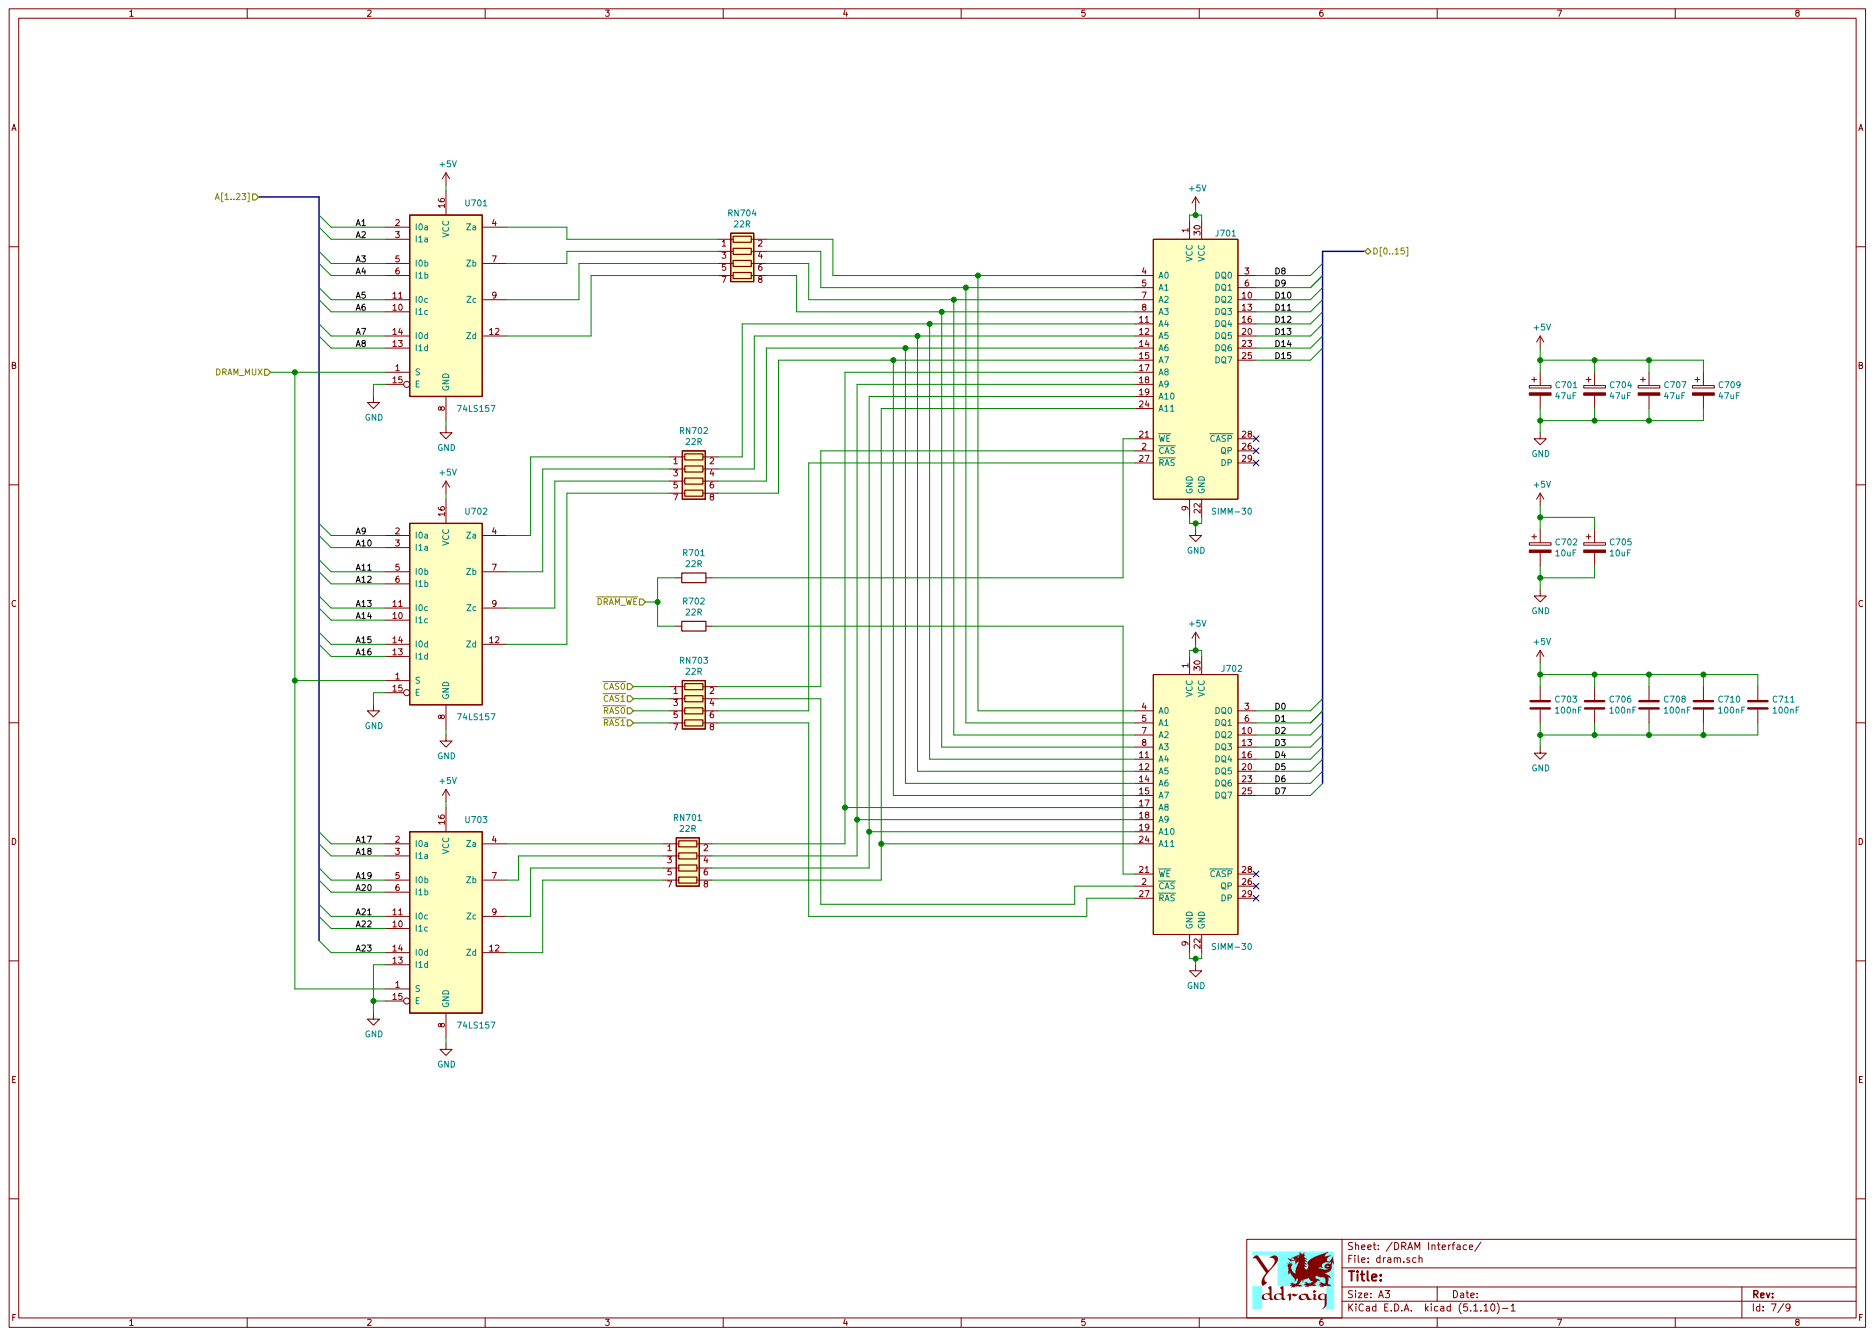
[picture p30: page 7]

Id: 7/9 Title: File: dram.sch Sheet: /DRAM Interface/ S 1

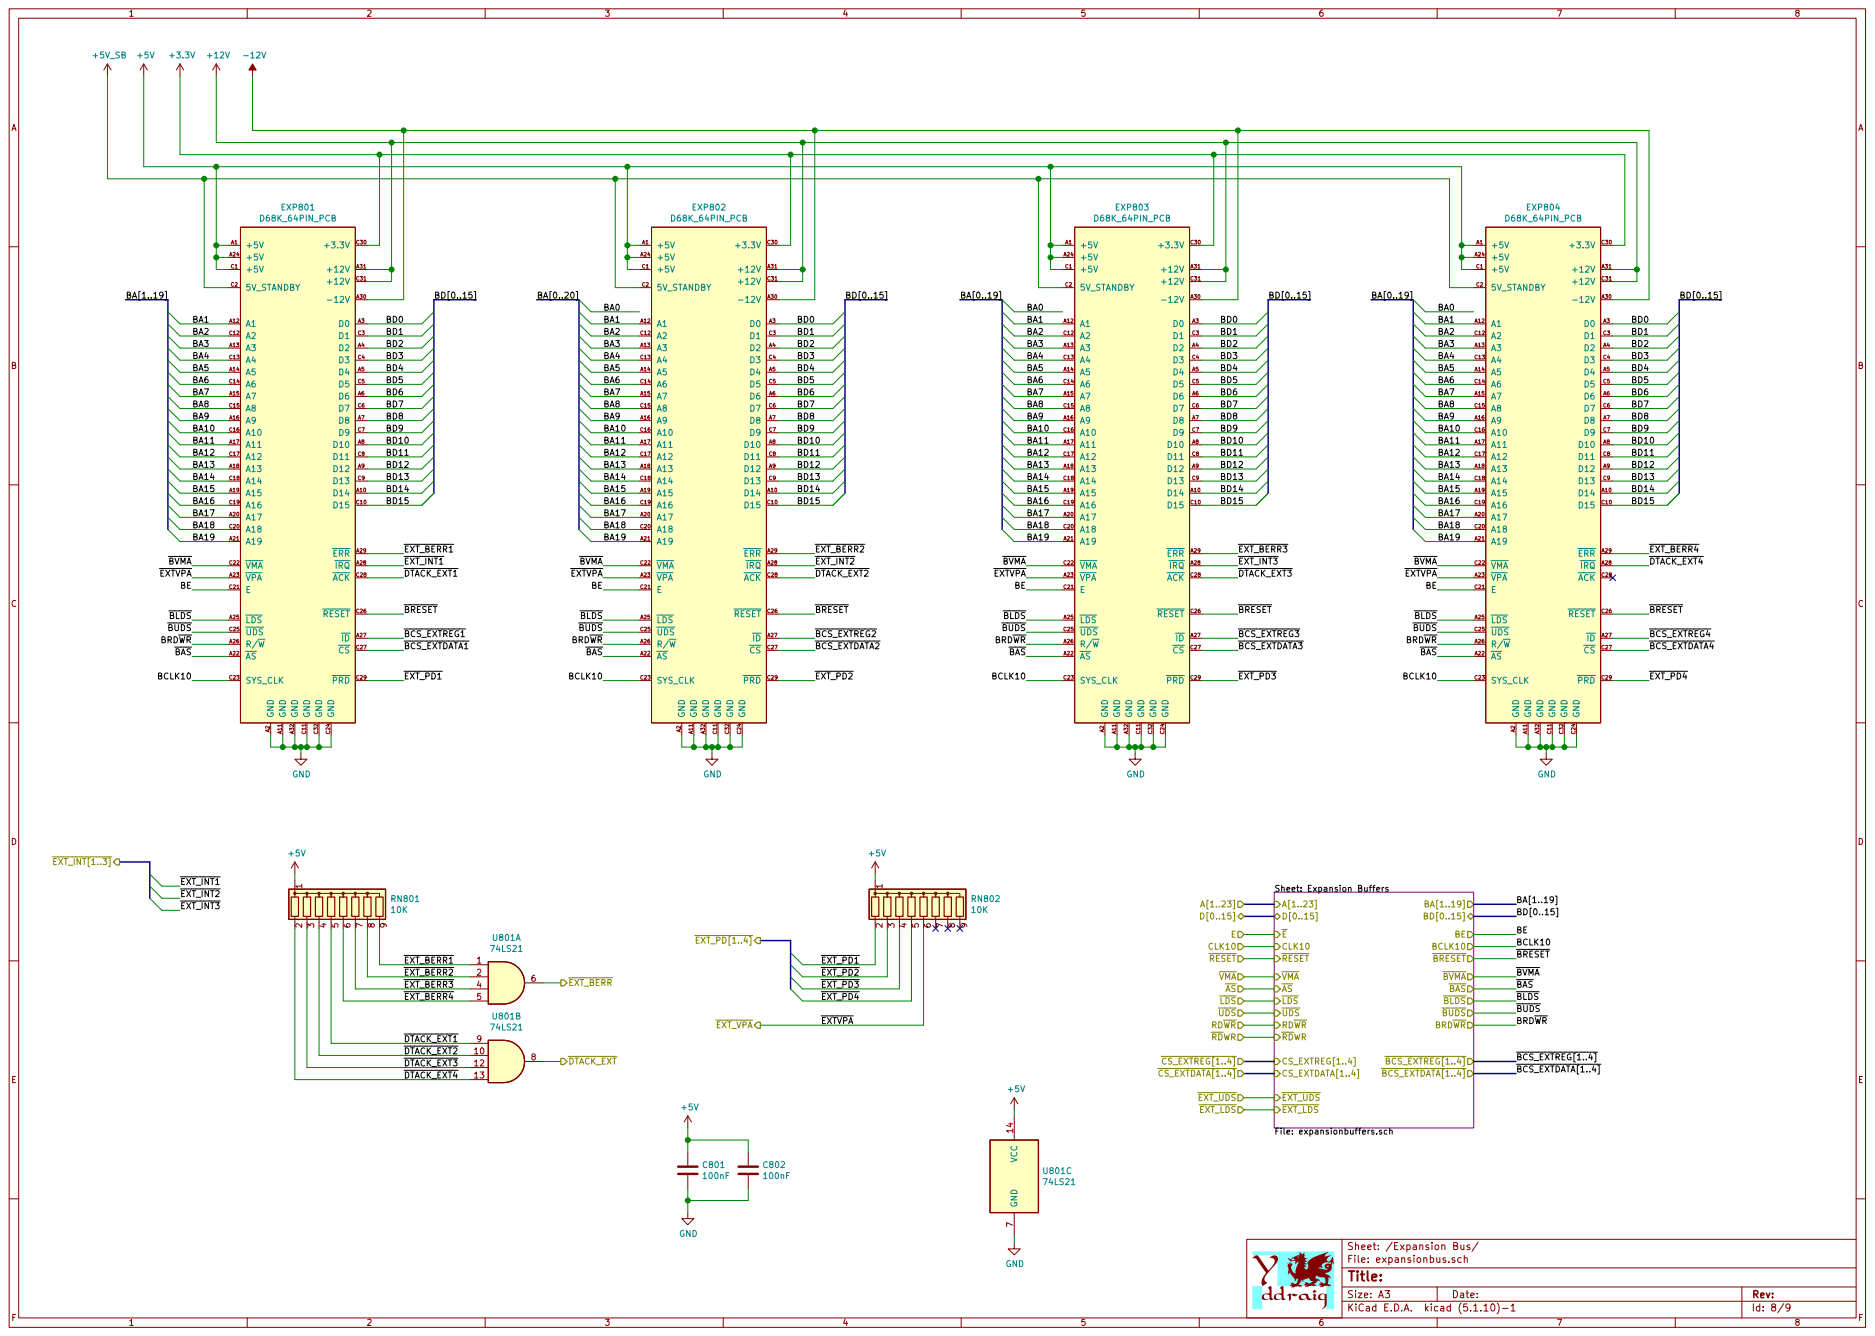
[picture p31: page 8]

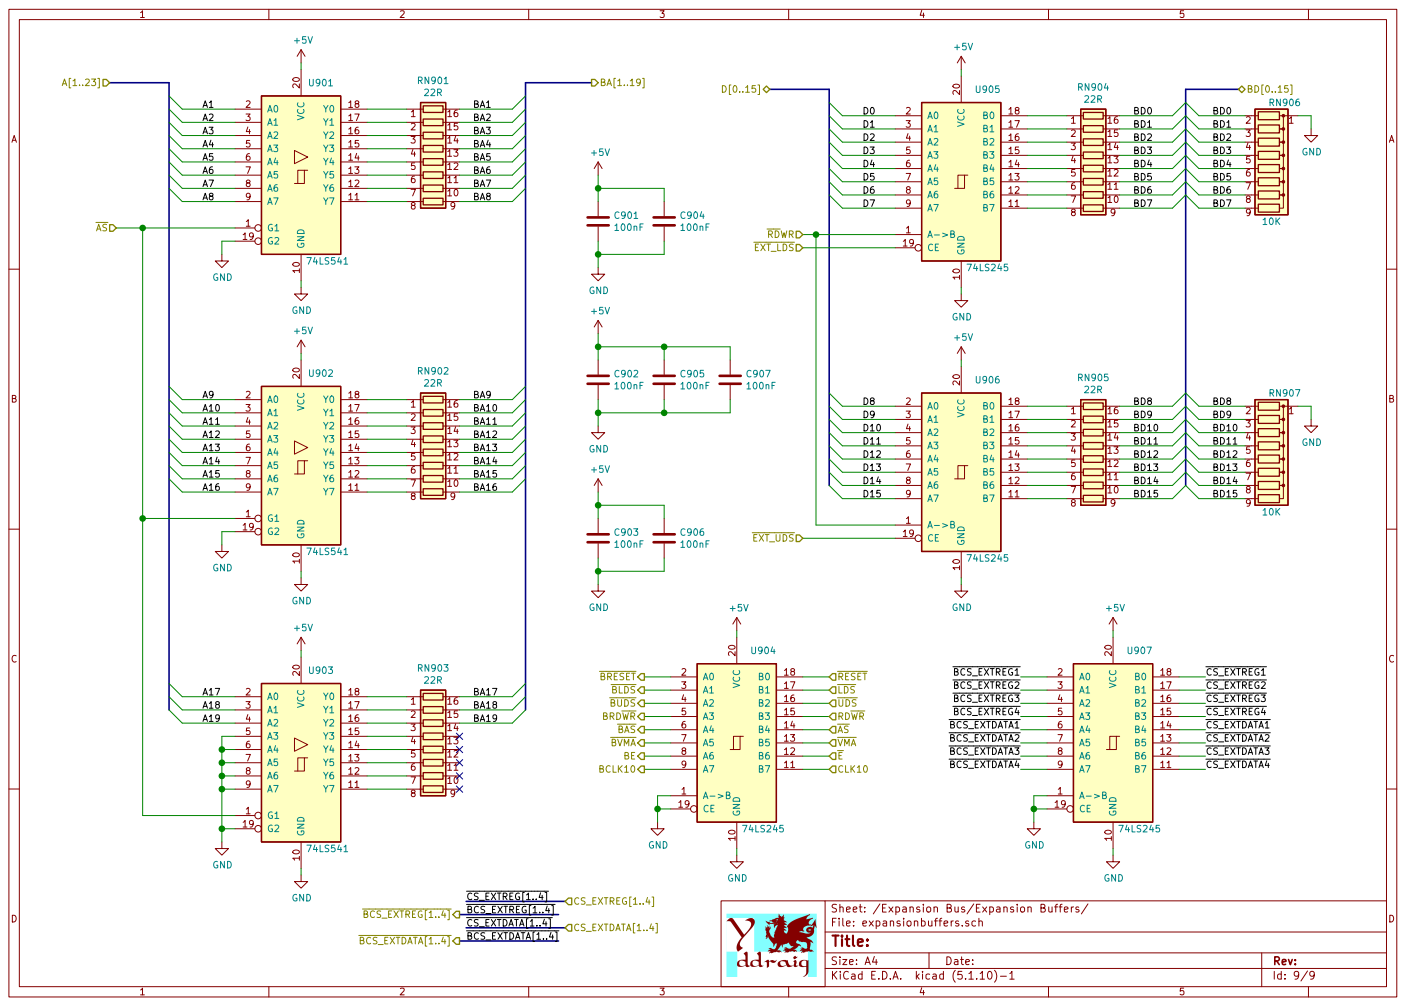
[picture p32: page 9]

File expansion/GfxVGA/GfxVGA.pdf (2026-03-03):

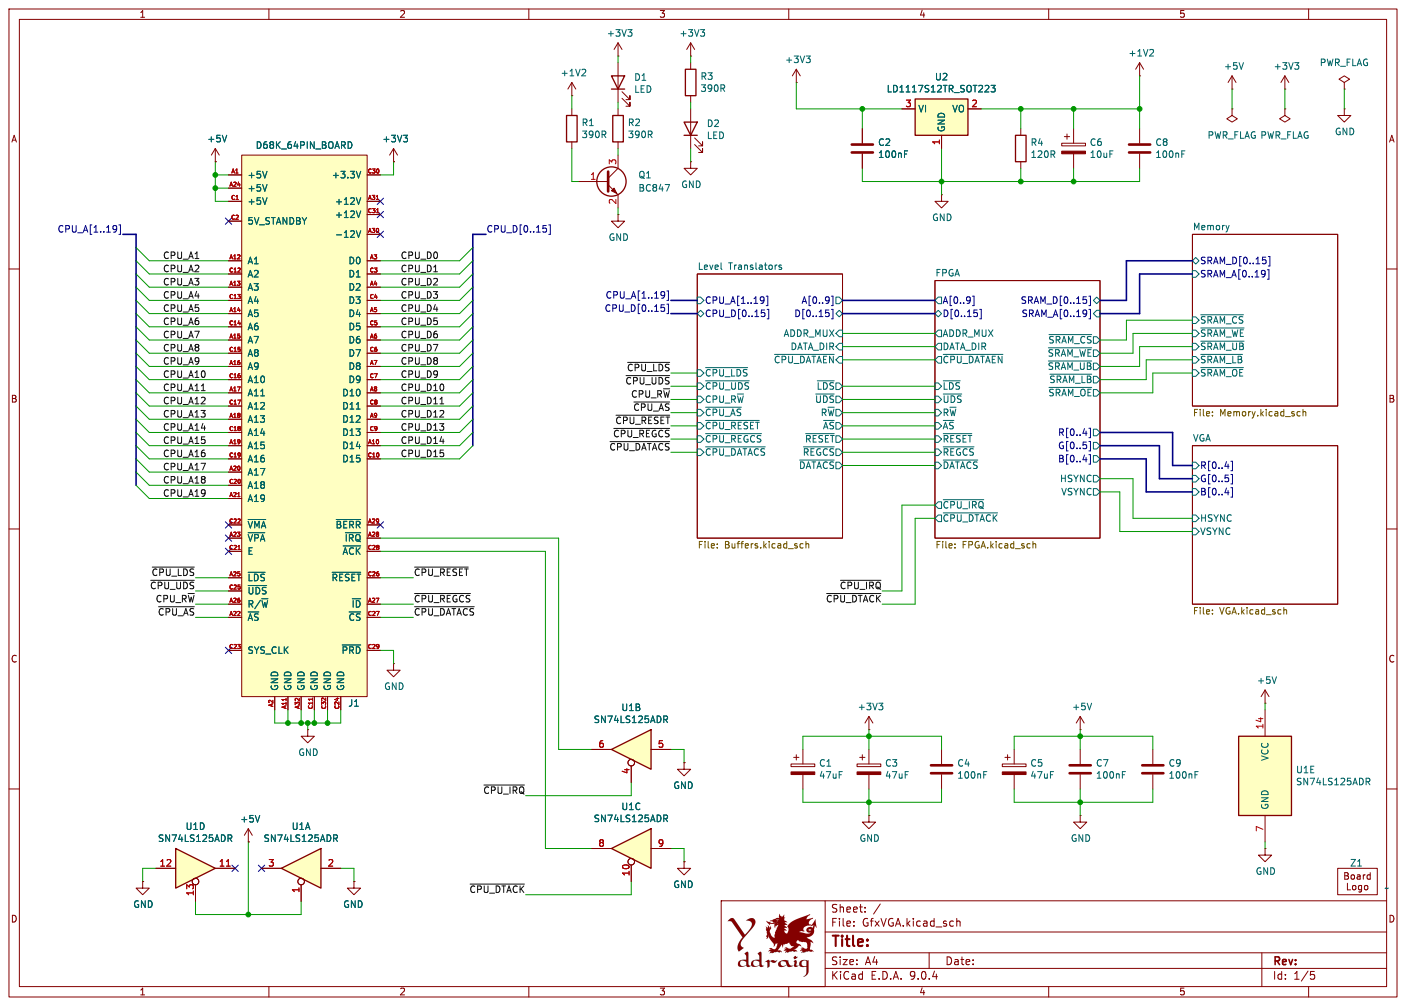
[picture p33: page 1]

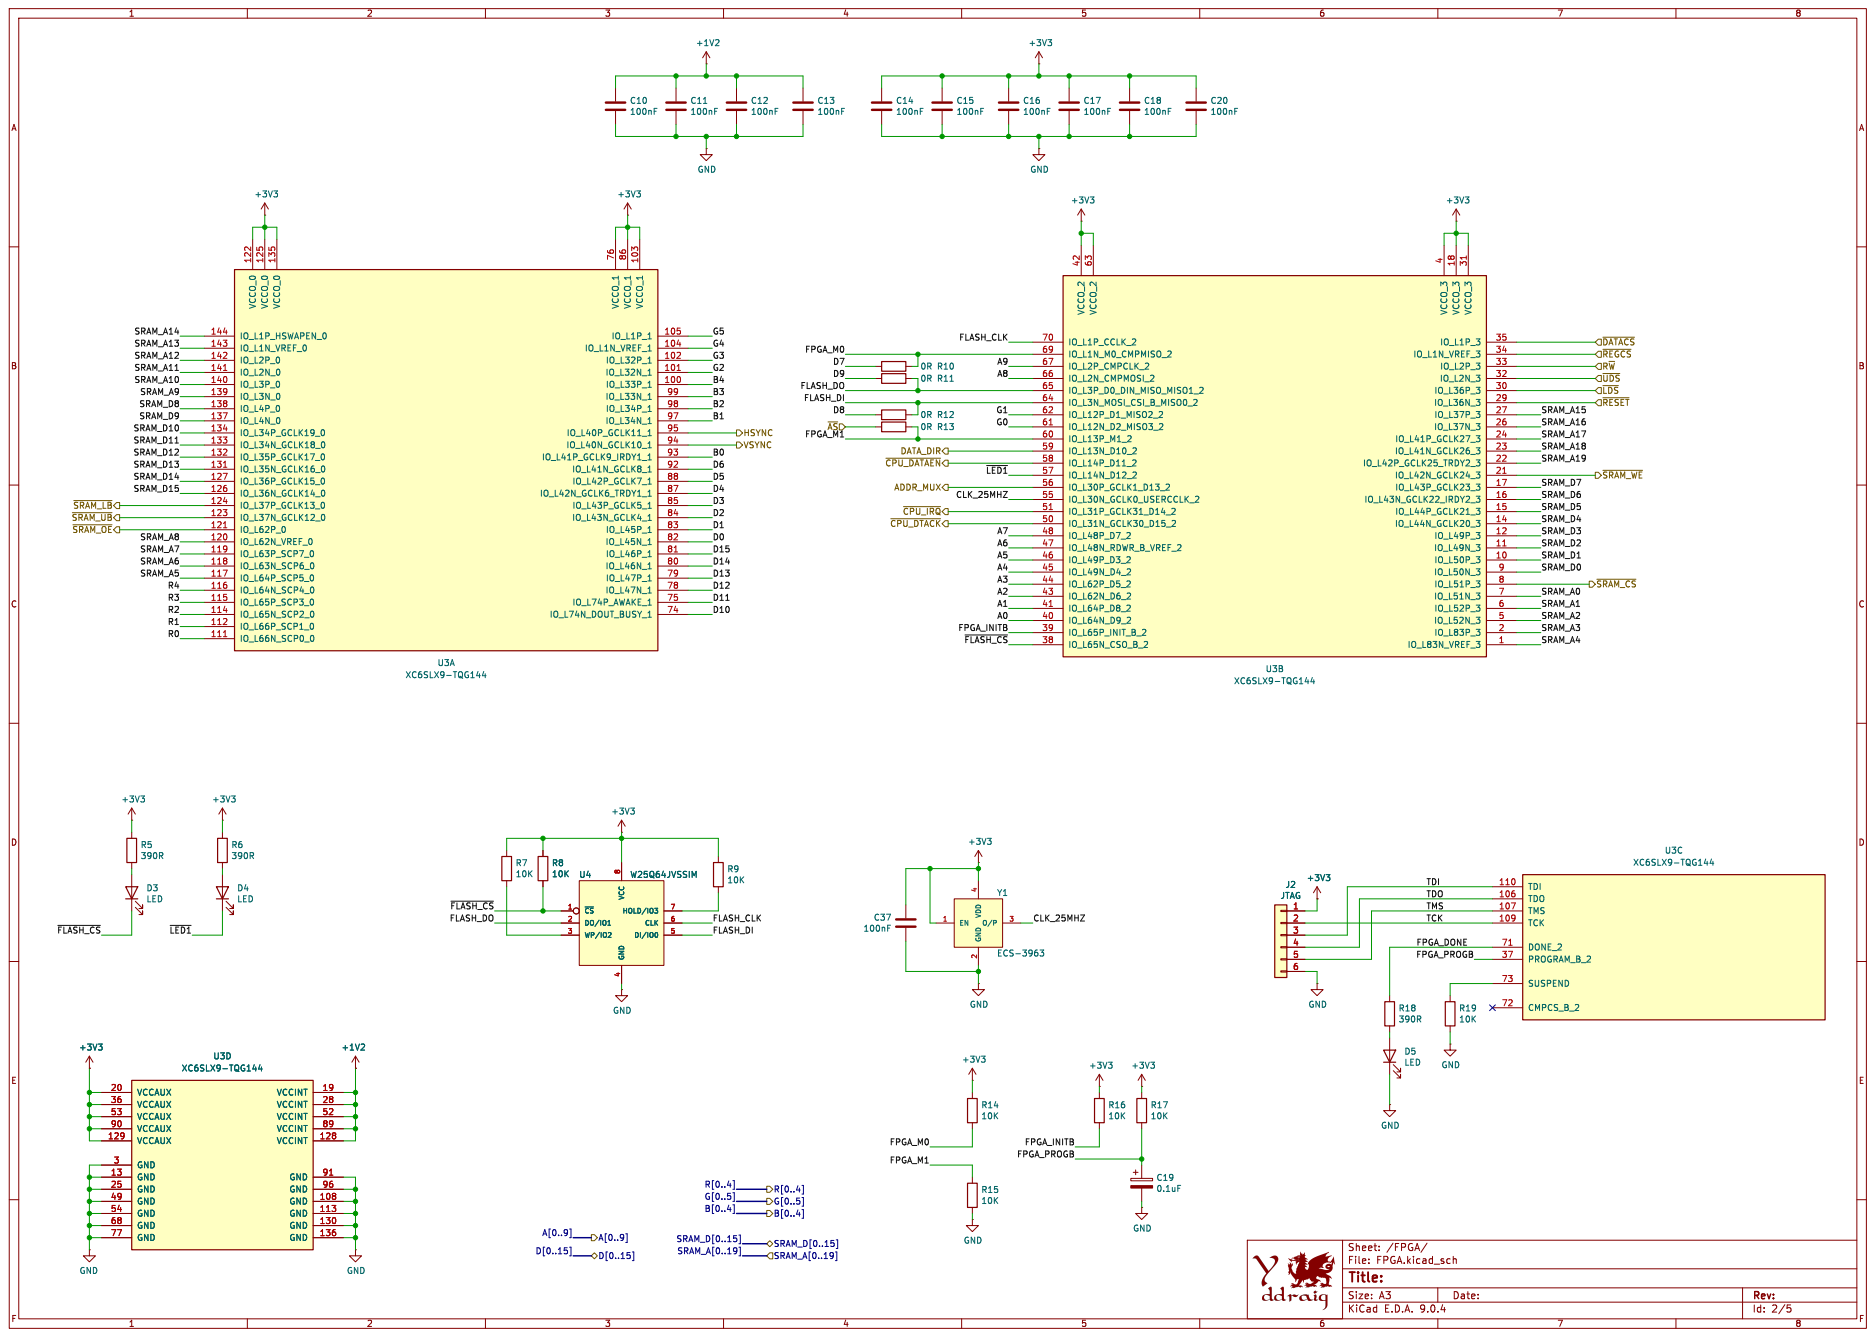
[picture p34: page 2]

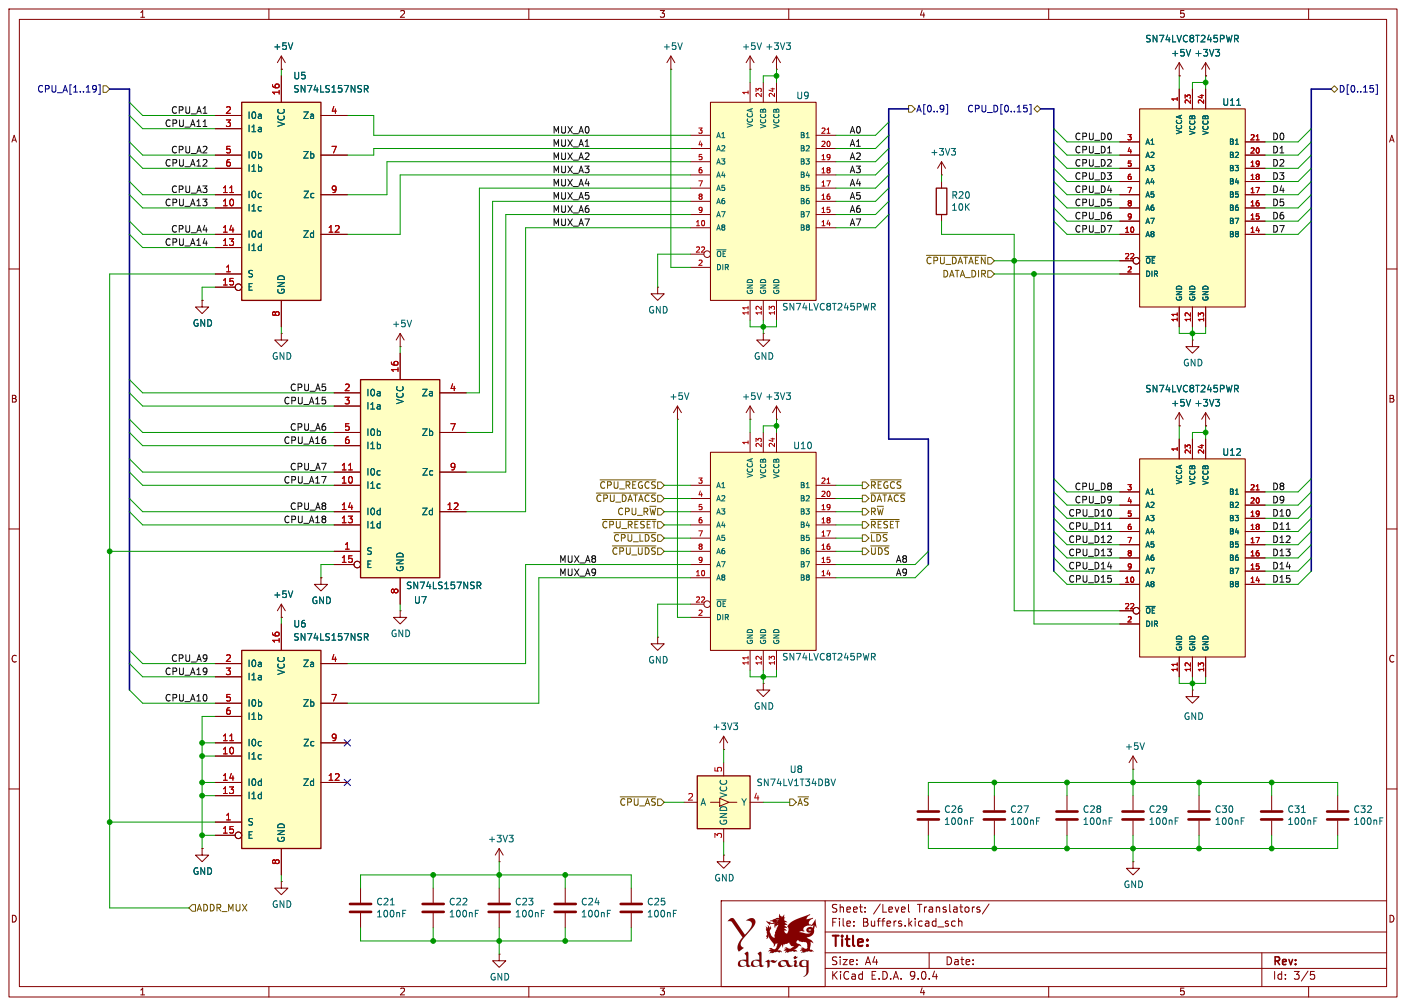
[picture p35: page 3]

8 Za 4 Zb 7 Zc 9 Zd 12 +5V +3V3 +5V +3V3 U11 SN74LVC8T245PWR

8 Za 4 Zb 7 Zc 9 Zd 12 U5SN74LS157NSR GND

1 GND 11 VCCB 23 GND 12 VCCB 24 GND 13 B1 21 B2 20 B3 19 B4 18 B5 17 B6 16 B7 15 B8 14 U9 SN74LVC8T245PWR GND

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

1 GND 11 VCCB 23 GND 12 VCCB 24 GND 13 B1 21 B2 20 B3 19 B4 18 B5 17 B6 16 B7 15 B8 14 U12 SN74LVC8T245PWR GND GND

8 Za 4 Zb 7 Zc 9 Zd 12 U6SN74LS157NSR

8 Za 4 Zb 7 Zc 9 Zd 12 U7 SN74LS157NSR GND

1 GND 11 VCCB 23 GND 12 VCCB 24 GND 13 B1 21 B2 20 B3 19 B4 18 B5 17 B6 16 B7 15 B8 14 U7 SN74LS157NSR

1 GND 11 VCCB 23 GND 12 VCCB 24 GND 13 B1 21 B2 20 B3 19 B4 18 B5 17 B6 16 B7 15 B8 14 U10 SN74LVC8T245PWR

8 Za 4 Zb 7 Zc 9 Zd 12 GND GND +5V


Id: 4/5 Title: File: Memory.kicad_sch Sheet: /Memory/ GND


Id: 5/5 Title: File: VGA.kicad_sch Sheet: /VGA/

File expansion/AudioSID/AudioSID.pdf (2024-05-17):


Id: 1/3 Title: File: AudioSID.kicad_sch Sheet: / ~{RESET}


Id: 2/3 Title: File: SID1.kicad_sch Sheet: /SID1/ C5


Id: 3/3 Title: File: SID2.kicad_sch Sheet: /SID2/ GND

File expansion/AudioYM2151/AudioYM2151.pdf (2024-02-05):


Amplifier File: Amplifier.kicad_sch +5V GND

5 P50 50 VCCIO 51 P52 52 P53 53 P54 54 P55 55 P56 56 VCCINT 57 P58 58 P59 59 P6 6 P60 60 P61 61 GND 62 P63 63 P64 64 P65 65 P66 66 P67 67 P68 68 GND 69 P7 7 P70 70 P71 71 P72 72 P73 73 P74 74 GND 75 P76 76 P77 77 P78 78 P79 79 P8 8 P80 80 P81 81 P82 82 TDO 83 GND 84 P85 85 P86 86 P87 87 VCCIO 88 P89 89 P9 9 P90 90 P91 91 P92 92 P93 93 P94 94 P95 95 P96 96 P97 97 VCCINT 98

Id: 1/3 Title: File: AudioYM2151.kicad_sch Sheet: /


1 PVCCR 10 PGNDR 11 ROUT 12 BSR 13 GAIN1 14 GAIN0 15 AVCC 16 AVCC 17 BSL 18

Id: 2/3 Title: File: Amplifier.kicad_sch Sheet: /Amplifier/


1 SDI 2 SCK 3 ~{SEN}/ADR 4 ~{CLK}5 CLK 6 OE 7 VCC

1 D0 10 GND 11 D1 12 D2 13 D3 14 D4 15 D5 16 D6 17 D7 18 SH2 19 ~{IRQ}2 SH1 20 SO 21 VCC 22

1 CH-2 10 COM 11 ToBUFF 12 MP 13 BC 14 RB 15 AGND 16 CLK1 2 GND

Id: 3/3 Title: File: YM2151.kicad_sch Sheet: /YM2151/ C12

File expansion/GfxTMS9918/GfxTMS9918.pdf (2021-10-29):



D[0..7] RESET
GND GND VCC 14 GND

Id: 2/2 Title: File: VDP.sch Sheet: /VDP/

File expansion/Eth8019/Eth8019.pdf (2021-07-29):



Id: 2/2 Title: File: RTL8019.sch Sheet: /RTL8019/GND

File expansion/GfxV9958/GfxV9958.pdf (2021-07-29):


RESET WAIT VDPW
File: VDP.sch VDPR
VDPW


1 SYNCIN 10 VCC 12 COUT 15 YOUT 16 YTRAP 17 VCC 19 RIN 2 CVOUT 20 BOUT 21 GOUT 22 ROUT 23 GND 24 GIN 3 BIN 4 SCIN 6 NPIN 7 BFOUT 8 U4 CXA2075M

Id: 2/3 Title: File: Video.sch Sheet: /Video/


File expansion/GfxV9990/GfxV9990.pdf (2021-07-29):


RESET WAIT VDPW
File: VDP.sch VDPR
VDPW


1 SYNCIN 10 VCC 12 COUT 15 YOUT 16 YTRAP 17 VCC 19 RIN 2 CVOUT 20 BOUT 21 GOUT 22 ROUT 23 GND 24 GIN 3 BIN 4 SCIN 6 NPIN 7 BFOUT 8 U4 CXA2075M

Id: 2/3 Title: File: Video.sch Sheet: /Video/ R7


Id: 3/3 Title: File: VDP.sch Sheet: /VDP/

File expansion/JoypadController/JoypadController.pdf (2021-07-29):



* Both low indicate controller connected

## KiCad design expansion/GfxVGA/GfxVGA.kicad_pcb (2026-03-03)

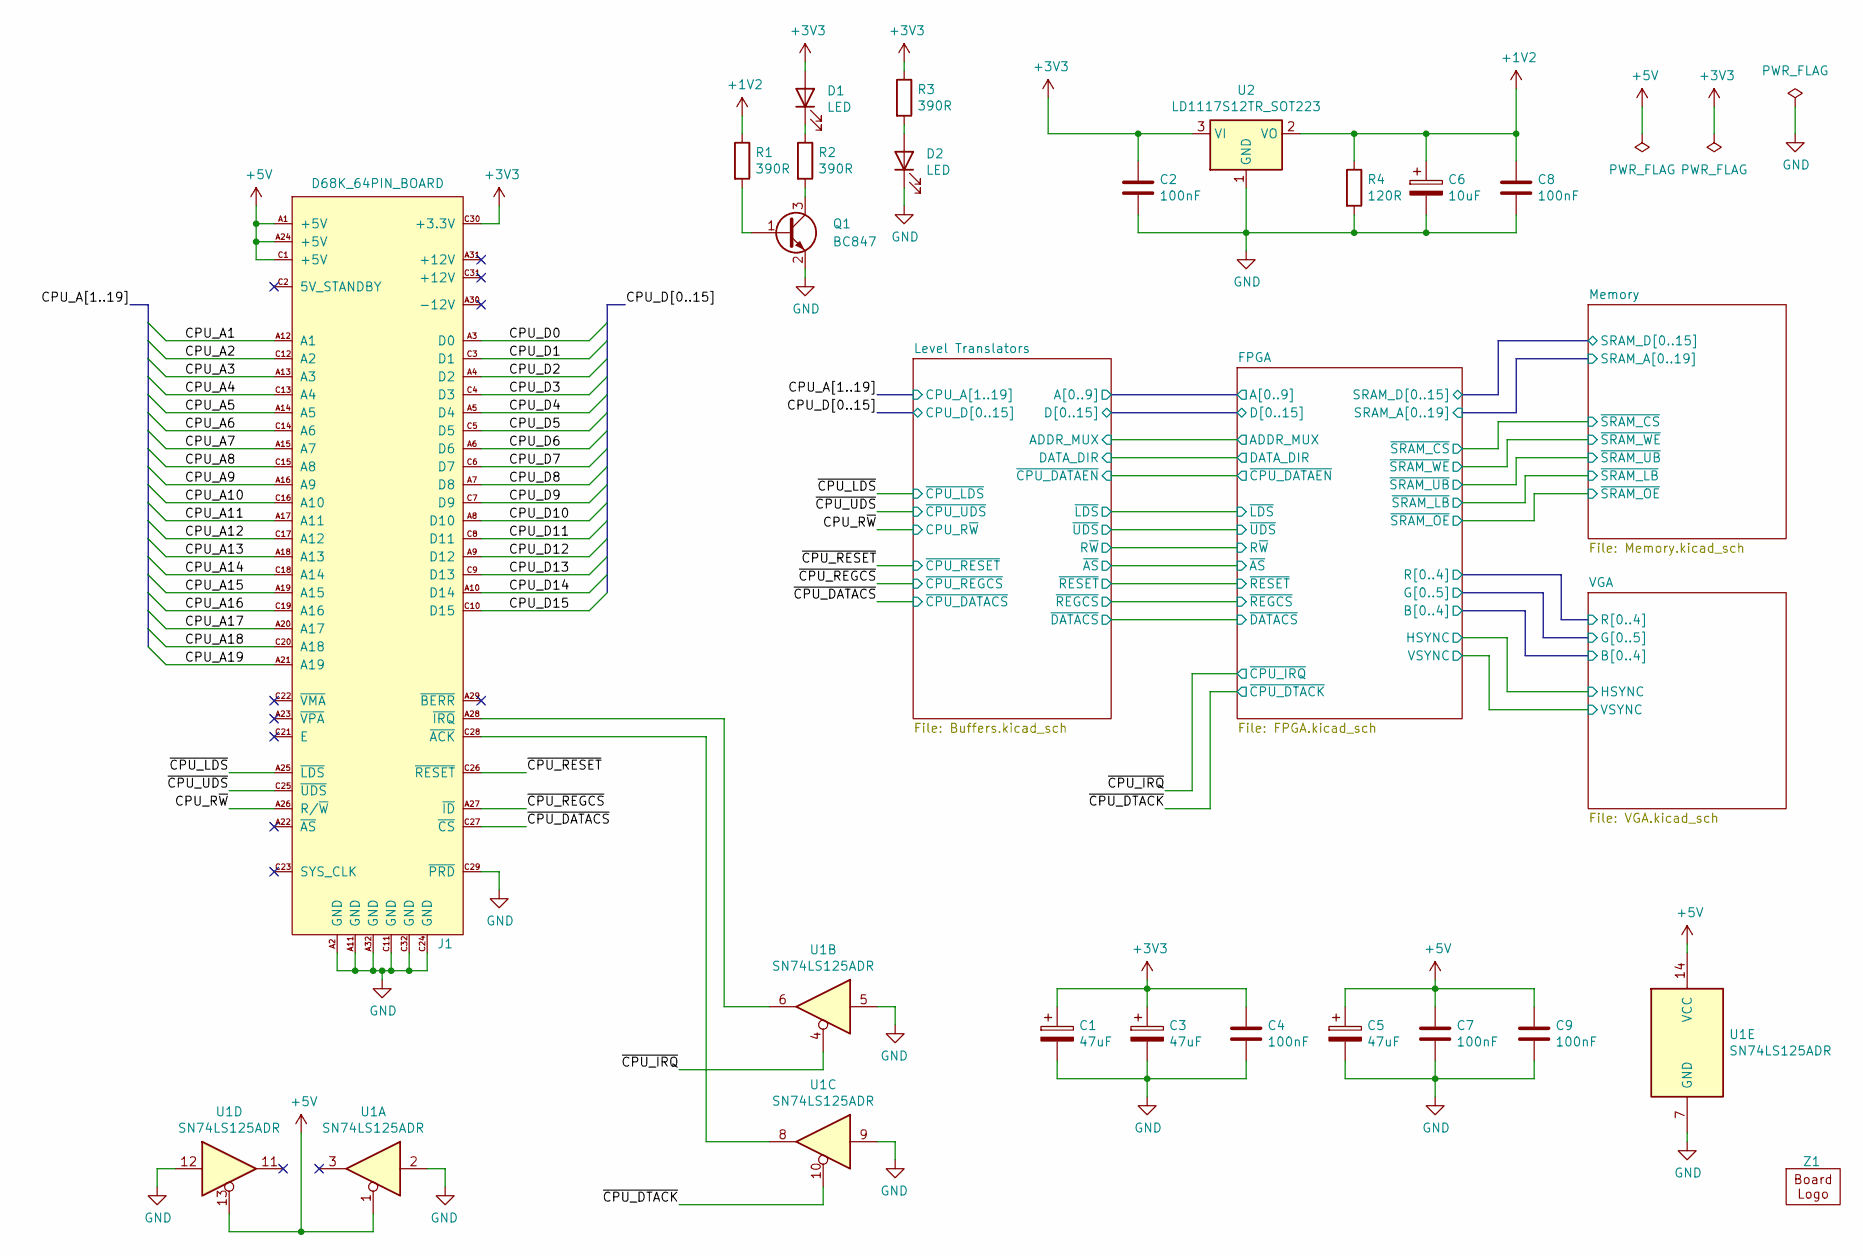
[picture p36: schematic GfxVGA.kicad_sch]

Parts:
C1, C3, C5: 47uF; CP_Elec_4x5.3
C2, C4, C7, C8, C9: 100nF; C_0805_2012Metric
C6: 10uF; CP_Elec_4x5.3
D1, D2: LED; LED_1206_3216Metric
J1: D68K_64PIN_BOARD; DIN41612_C_2x32_Male_Horizontal_THT
Q1: BC847; SOT-23
R1, R2, R3: 390R; R_0805_2012Metric
R4: 120R; R_0805_2012Metric
U1: SN74LS125ADR; SO-14_3.9x8.65mm_P1.27mm
U2: LD1117S12TR_SOT223; SOT-223-3_TabPin2
Z1: Ddraig68k-26mm

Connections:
+1V2: C6.1, C8.1, R1.1, R4.1, U2.2 (VO); also elsewhere on the board
+3V3: C1.1, C2.1, C3.1, C4.1, D1.2 (A), J1.C30 (+3.3V), R3.1, U2.3 (VI); also elsewhere on the board
+5V: C5.1, C7.1, C9.1, J1.A1 (+5V), J1.A24 (+5V), J1.C1 (+5V), U1.1, U1.13, U1.14 (VCC); also elsewhere on the board
/CPU_A1: J1.A12 (A1); also elsewhere on the board
/CPU_A2: J1.C12 (A2); also elsewhere on the board
/CPU_A3: J1.A13 (A3); also elsewhere on the board
/CPU_A4: J1.C13 (A4); also elsewhere on the board
/CPU_A5: J1.A14 (A5); also elsewhere on the board
/CPU_A6: J1.C14 (A6); also elsewhere on the board
/CPU_A7: J1.A15 (A7); also elsewhere on the board
/CPU_A8: J1.C15 (A8); also elsewhere on the board
/CPU_A9: J1.A16 (A9); also elsewhere on the board
/CPU_A10: J1.C16 (A10); also elsewhere on the board
/CPU_A11: J1.A17 (A11); also elsewhere on the board
/CPU_A12: J1.C17 (A12); also elsewhere on the board
/CPU_A13: J1.A18 (A13); also elsewhere on the board
/CPU_A14: J1.C18 (A14); also elsewhere on the board
/CPU_A15: J1.A19 (A15); also elsewhere on the board
/CPU_A16: J1.C19 (A16); also elsewhere on the board
/CPU_A17: J1.A20 (A17); also elsewhere on the board
/CPU_A18: J1.C20 (A18); also elsewhere on the board
/CPU_A19: J1.A21 (A19); also elsewhere on the board
/CPU_D0: J1.A3 (D0); also elsewhere on the board
/CPU_D1: J1.C3 (D1); also elsewhere on the board
/CPU_D2: J1.A4 (D2); also elsewhere on the board
/CPU_D3: J1.C4 (D3); also elsewhere on the board
/CPU_D4: J1.A5 (D4); also elsewhere on the board
/CPU_D5: J1.C5 (D5); also elsewhere on the board
/CPU_D6: J1.A6 (D6); also elsewhere on the board
/CPU_D7: J1.C6 (D7); also elsewhere on the board
/CPU_D8: J1.A7 (D8); also elsewhere on the board
/CPU_D9: J1.C7 (D9); also elsewhere on the board
/CPU_D10: J1.A8 (D10); also elsewhere on the board
/CPU_D11: J1.C8 (D11); also elsewhere on the board
/CPU_D12: J1.A9 (D12); also elsewhere on the board
/CPU_D13: J1.C9 (D13); also elsewhere on the board
/CPU_D14: J1.A10 (D14); also elsewhere on the board
/CPU_D15: J1.C10 (D15); also elsewhere on the board
/CPU_R~W: J1.A26 (R/~W); also elsewhere on the board
/~CPU_DATACS: J1.C27 (~CS); also elsewhere on the board
/~CPU_DTACK: U1.10; also elsewhere on the board
/~CPU_IRQ: U1.4; also elsewhere on the board
/~CPU_LDS: J1.A25 (~LDS); also elsewhere on the board
/~CPU_REGCS: J1.A27 (~ID); also elsewhere on the board
/~CPU_RESET: J1.C26 (~RESET); also elsewhere on the board
/~CPU_UDS: J1.C25 (~UDS); also elsewhere on the board
GND: C1.2, C2.2, C3.2, C4.2, C5.2, C6.2, C7.2, C8.2, C9.2, D2.1 (K), J1.A2 (GND), J1.A11 (GND), J1.A32 (GND), J1.C11 (GND), J1.C24 (GND), J1.C29 (~PRD), J1.C32 (GND), Q1.2 (E), R4.2, U1.2, U1.5, U1.7 (GND), U1.9, U1.12, U2.1 (GND); also elsewhere on the board
unnamed: D1.1 (K), R2.1
unnamed: D2.2 (A), R3.2
unnamed: J1.C28 (~ACK), U1.8
unnamed: J1.A28 (~IRQ), U1.6
unnamed: Q1.1 (B), R1.2
unnamed: Q1.3 (C), R2.2

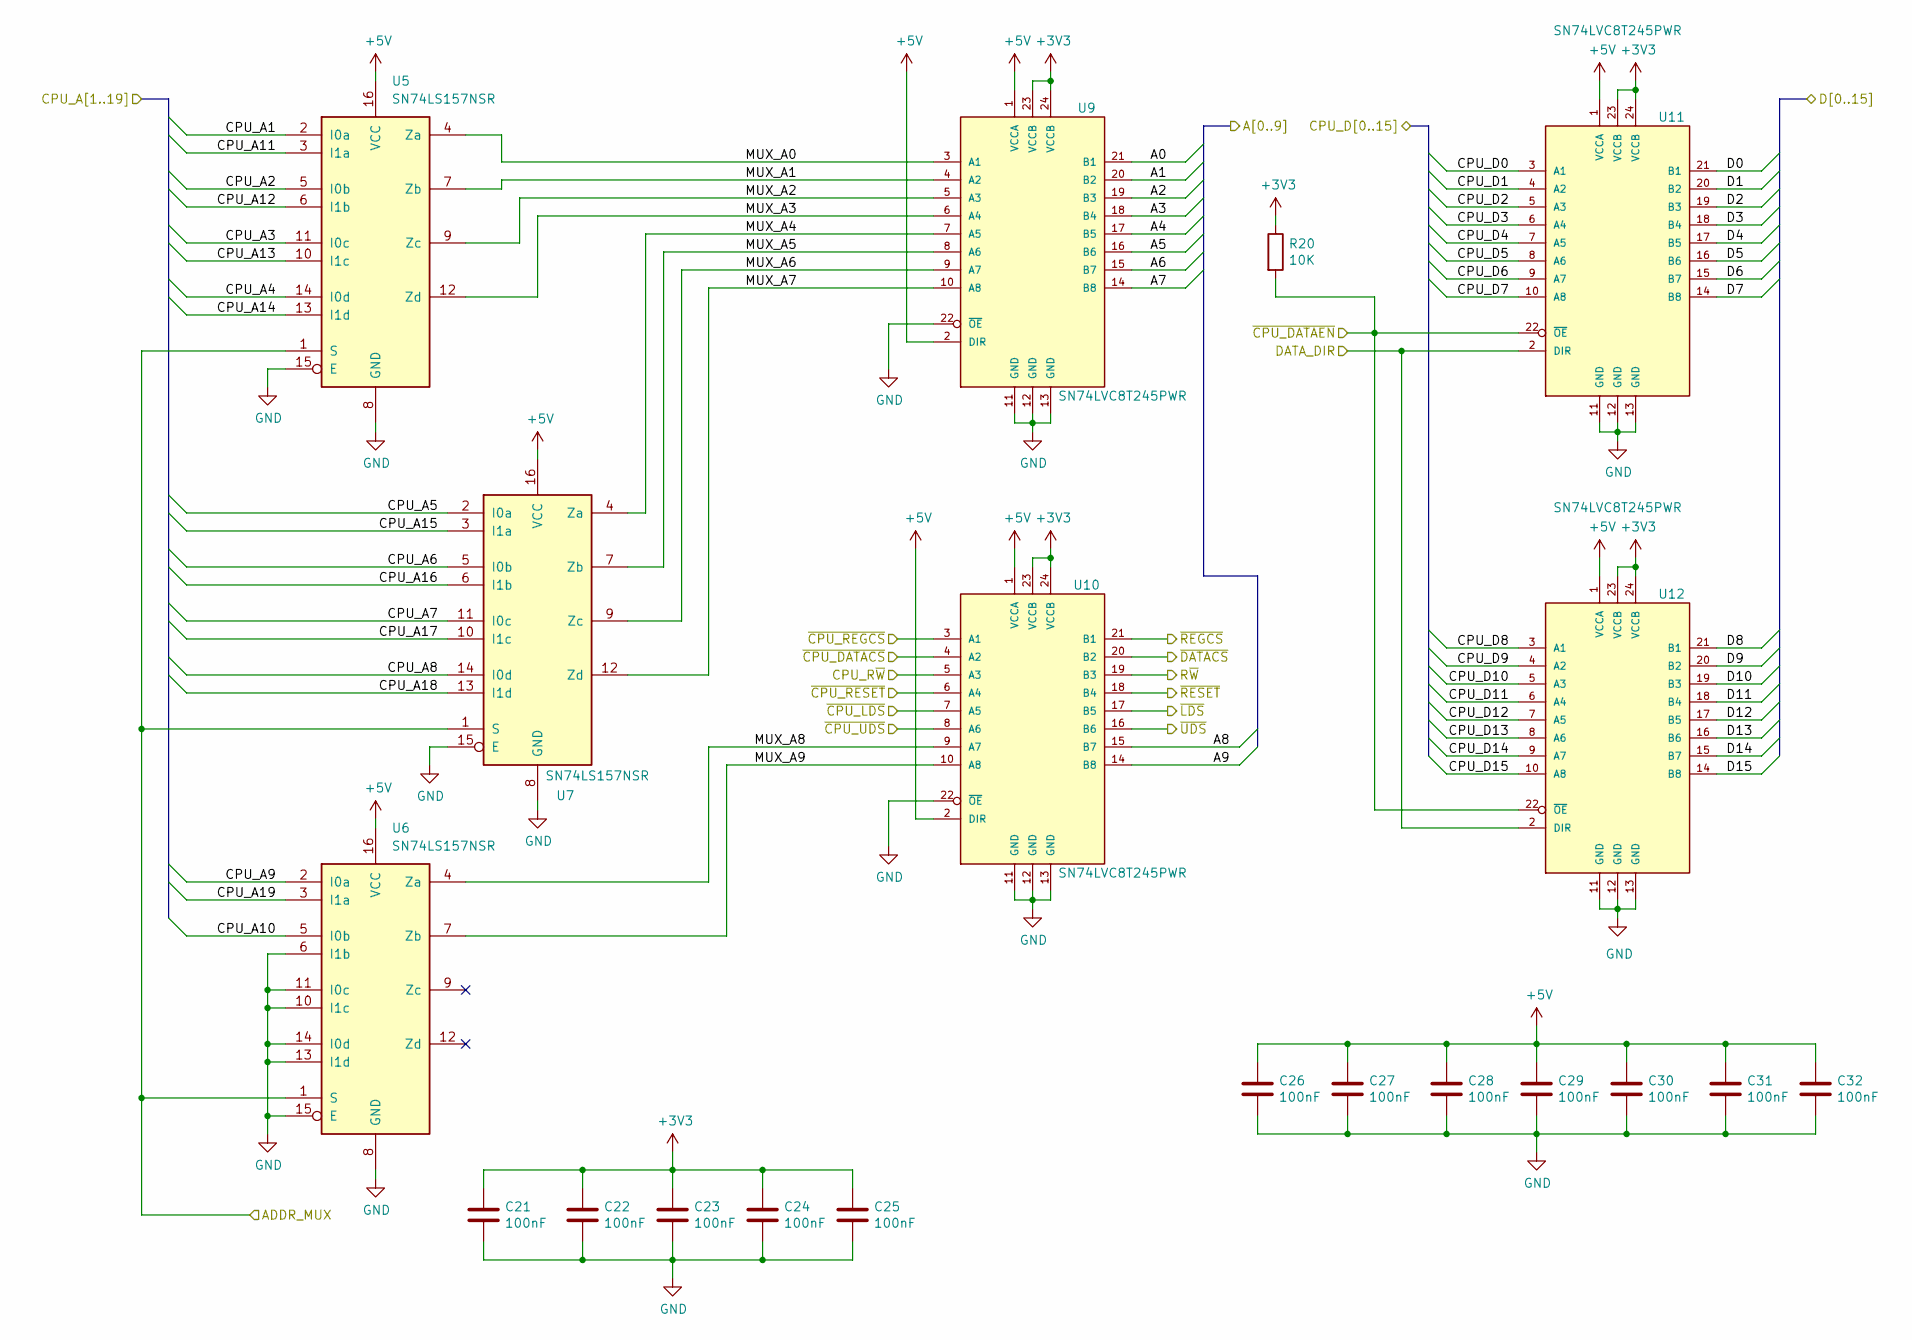
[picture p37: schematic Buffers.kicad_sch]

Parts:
C21, C22, C23, C24, C25, C26, C27, C28, C29, C30, C31, C32: 100nF; C_0805_2012Metric
R20: 10K; R_0805_2012Metric
U5, U6, U7: SN74LS157NSR; SO-16_5.3x10.2mm_P1.27mm
U9, U10, U11, U12: SN74LVC8T245PWR; SOP65P640X120-24N

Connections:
+3V3: C21.1, C22.1, C23.1, C24.1, C25.1, R20.1, U9.23 (VCCB), U9.24 (VCCB), U10.23 (VCCB), U10.24 (VCCB), U11.23 (VCCB), U11.24 (VCCB), U12.23 (VCCB), U12.24 (VCCB); also elsewhere on the board
+5V: C26.1, C27.1, C28.1, C29.1, C30.1, C31.1, C32.1, U5.16 (VCC), U6.16 (VCC), U7.16 (VCC), U9.1 (VCCA), U9.2 (DIR), U10.1 (VCCA), U10.2 (DIR), U11.1 (VCCA), U12.1 (VCCA); also elsewhere on the board
/CPU_A1: U5.2 (I0a); also elsewhere on the board
/CPU_A2: U5.5 (I0b); also elsewhere on the board
/CPU_A3: U5.11 (I0c); also elsewhere on the board
/CPU_A4: U5.14 (I0d); also elsewhere on the board
/CPU_A5: U7.2 (I0a); also elsewhere on the board
/CPU_A6: U7.5 (I0b); also elsewhere on the board
/CPU_A7: U7.11 (I0c); also elsewhere on the board
/CPU_A8: U7.14 (I0d); also elsewhere on the board
/CPU_A9: U6.2 (I0a); also elsewhere on the board
/CPU_A10: U6.5 (I0b); also elsewhere on the board
/CPU_A11: U5.3 (I1a); also elsewhere on the board
/CPU_A12: U5.6 (I1b); also elsewhere on the board
/CPU_A13: U5.10 (I1c); also elsewhere on the board
/CPU_A14: U5.13 (I1d); also elsewhere on the board
/CPU_A15: U7.3 (I1a); also elsewhere on the board
/CPU_A16: U7.6 (I1b); also elsewhere on the board
/CPU_A17: U7.10 (I1c); also elsewhere on the board
/CPU_A18: U7.13 (I1d); also elsewhere on the board
/CPU_A19: U6.3 (I1a); also elsewhere on the board
/CPU_D0: U11.3 (A1); also elsewhere on the board
/CPU_D1: U11.4 (A2); also elsewhere on the board
/CPU_D2: U11.5 (A3); also elsewhere on the board
/CPU_D3: U11.6 (A4); also elsewhere on the board
/CPU_D4: U11.7 (A5); also elsewhere on the board
/CPU_D5: U11.8 (A6); also elsewhere on the board
/CPU_D6: U11.9 (A7); also elsewhere on the board
/CPU_D7: U11.10 (A8); also elsewhere on the board
/CPU_D8: U12.3 (A1); also elsewhere on the board
/CPU_D9: U12.4 (A2); also elsewhere on the board
/CPU_D10: U12.5 (A3); also elsewhere on the board
/CPU_D11: U12.6 (A4); also elsewhere on the board
/CPU_D12: U12.7 (A5); also elsewhere on the board
/CPU_D13: U12.8 (A6); also elsewhere on the board
/CPU_D14: U12.9 (A7); also elsewhere on the board
/CPU_D15: U12.10 (A8); also elsewhere on the board
/CPU_R~W: U10.5 (A3); also elsewhere on the board
/FPGA/A0: U9.21 (B1); also elsewhere on the board
/FPGA/A1: U9.20 (B2); also elsewhere on the board
/FPGA/A2: U9.19 (B3); also elsewhere on the board
/FPGA/A3: U9.18 (B4); also elsewhere on the board
/FPGA/A4: U9.17 (B5); also elsewhere on the board
/FPGA/A5: U9.16 (B6); also elsewhere on the board
/FPGA/A6: U9.15 (B7); also elsewhere on the board
/FPGA/A7: U9.14 (B8); also elsewhere on the board
/FPGA/A8: U10.15 (B7); also elsewhere on the board
/FPGA/A9: U10.14 (B8); also elsewhere on the board
/FPGA/ADDR_MUX: U5.1 (S), U6.1 (S), U7.1 (S); also elsewhere on the board
/FPGA/D0: U11.21 (B1); also elsewhere on the board
/FPGA/D1: U11.20 (B2); also elsewhere on the board
/FPGA/D2: U11.19 (B3); also elsewhere on the board
/FPGA/D3: U11.18 (B4); also elsewhere on the board
/FPGA/D4: U11.17 (B5); also elsewhere on the board
/FPGA/D5: U11.16 (B6); also elsewhere on the board
/FPGA/D6: U11.15 (B7); also elsewhere on the board
/FPGA/D7: U11.14 (B8); also elsewhere on the board
/FPGA/D8: U12.21 (B1); also elsewhere on the board
/FPGA/D9: U12.20 (B2); also elsewhere on the board
/FPGA/D10: U12.19 (B3); also elsewhere on the board
/FPGA/D11: U12.18 (B4); also elsewhere on the board
/FPGA/D12: U12.17 (B5); also elsewhere on the board
/FPGA/D13: U12.16 (B6); also elsewhere on the board
/FPGA/D14: U12.15 (B7); also elsewhere on the board
/FPGA/D15: U12.14 (B8); also elsewhere on the board
/FPGA/DATA_DIR: U11.2 (DIR), U12.2 (DIR); also elsewhere on the board
/FPGA/R~W: U10.19 (B3); also elsewhere on the board
/FPGA/~CPU_DATAEN: R20.2, U11.22 (~OE), U12.22 (~OE); also elsewhere on the board
/FPGA/~DATACS: U10.20 (B2); also elsewhere on the board
/FPGA/~LDS: U10.17 (B5); also elsewhere on the board
/FPGA/~REGCS: U10.21 (B1); also elsewhere on the board
/FPGA/~RESET: U10.18 (B4); also elsewhere on the board
/FPGA/~UDS: U10.16 (B6); also elsewhere on the board
/Level Translators/MUX_A0: U5.4 (Za), U9.3 (A1)
/Level Translators/MUX_A1: U5.7 (Zb), U9.4 (A2)
/Level Translators/MUX_A2: U5.9 (Zc), U9.5 (A3)
/Level Translators/MUX_A3: U5.12 (Zd), U9.6 (A4)
/Level Translators/MUX_A4: U7.4 (Za), U9.7 (A5)
/Level Translators/MUX_A5: U7.7 (Zb), U9.8 (A6)
/Level Translators/MUX_A6: U7.9 (Zc), U9.9 (A7)
/Level Translators/MUX_A7: U7.12 (Zd), U9.10 (A8)
/Level Translators/MUX_A8: U6.4 (Za), U10.9 (A7)
/Level Translators/MUX_A9: U6.7 (Zb), U10.10 (A8)
/~CPU_DATACS: U10.4 (A2); also elsewhere on the board
/~CPU_LDS: U10.7 (A5); also elsewhere on the board
/~CPU_REGCS: U10.3 (A1); also elsewhere on the board
/~CPU_RESET: U10.6 (A4); also elsewhere on the board
/~CPU_UDS: U10.8 (A6); also elsewhere on the board
GND: C21.2, C22.2, C23.2, C24.2, C25.2, C26.2, C27.2, C28.2, C29.2, C30.2, C31.2, C32.2, U5.8 (GND), U5.15 (E), U6.6 (I1b), U6.8 (GND), U6.10 (I1c), U6.11 (I0c), U6.13 (I1d), U6.14 (I0d), U6.15 (E), U7.8 (GND), U7.15 (E), U9.11 (GND), U9.12 (GND), U9.13 (GND), U9.22 (~OE), U10.11 (GND), U10.12 (GND), U10.13 (GND), U10.22 (~OE), U11.11 (GND), U11.12 (GND), U11.13 (GND), U12.11 (GND), U12.12 (GND), U12.13 (GND); also elsewhere on the board

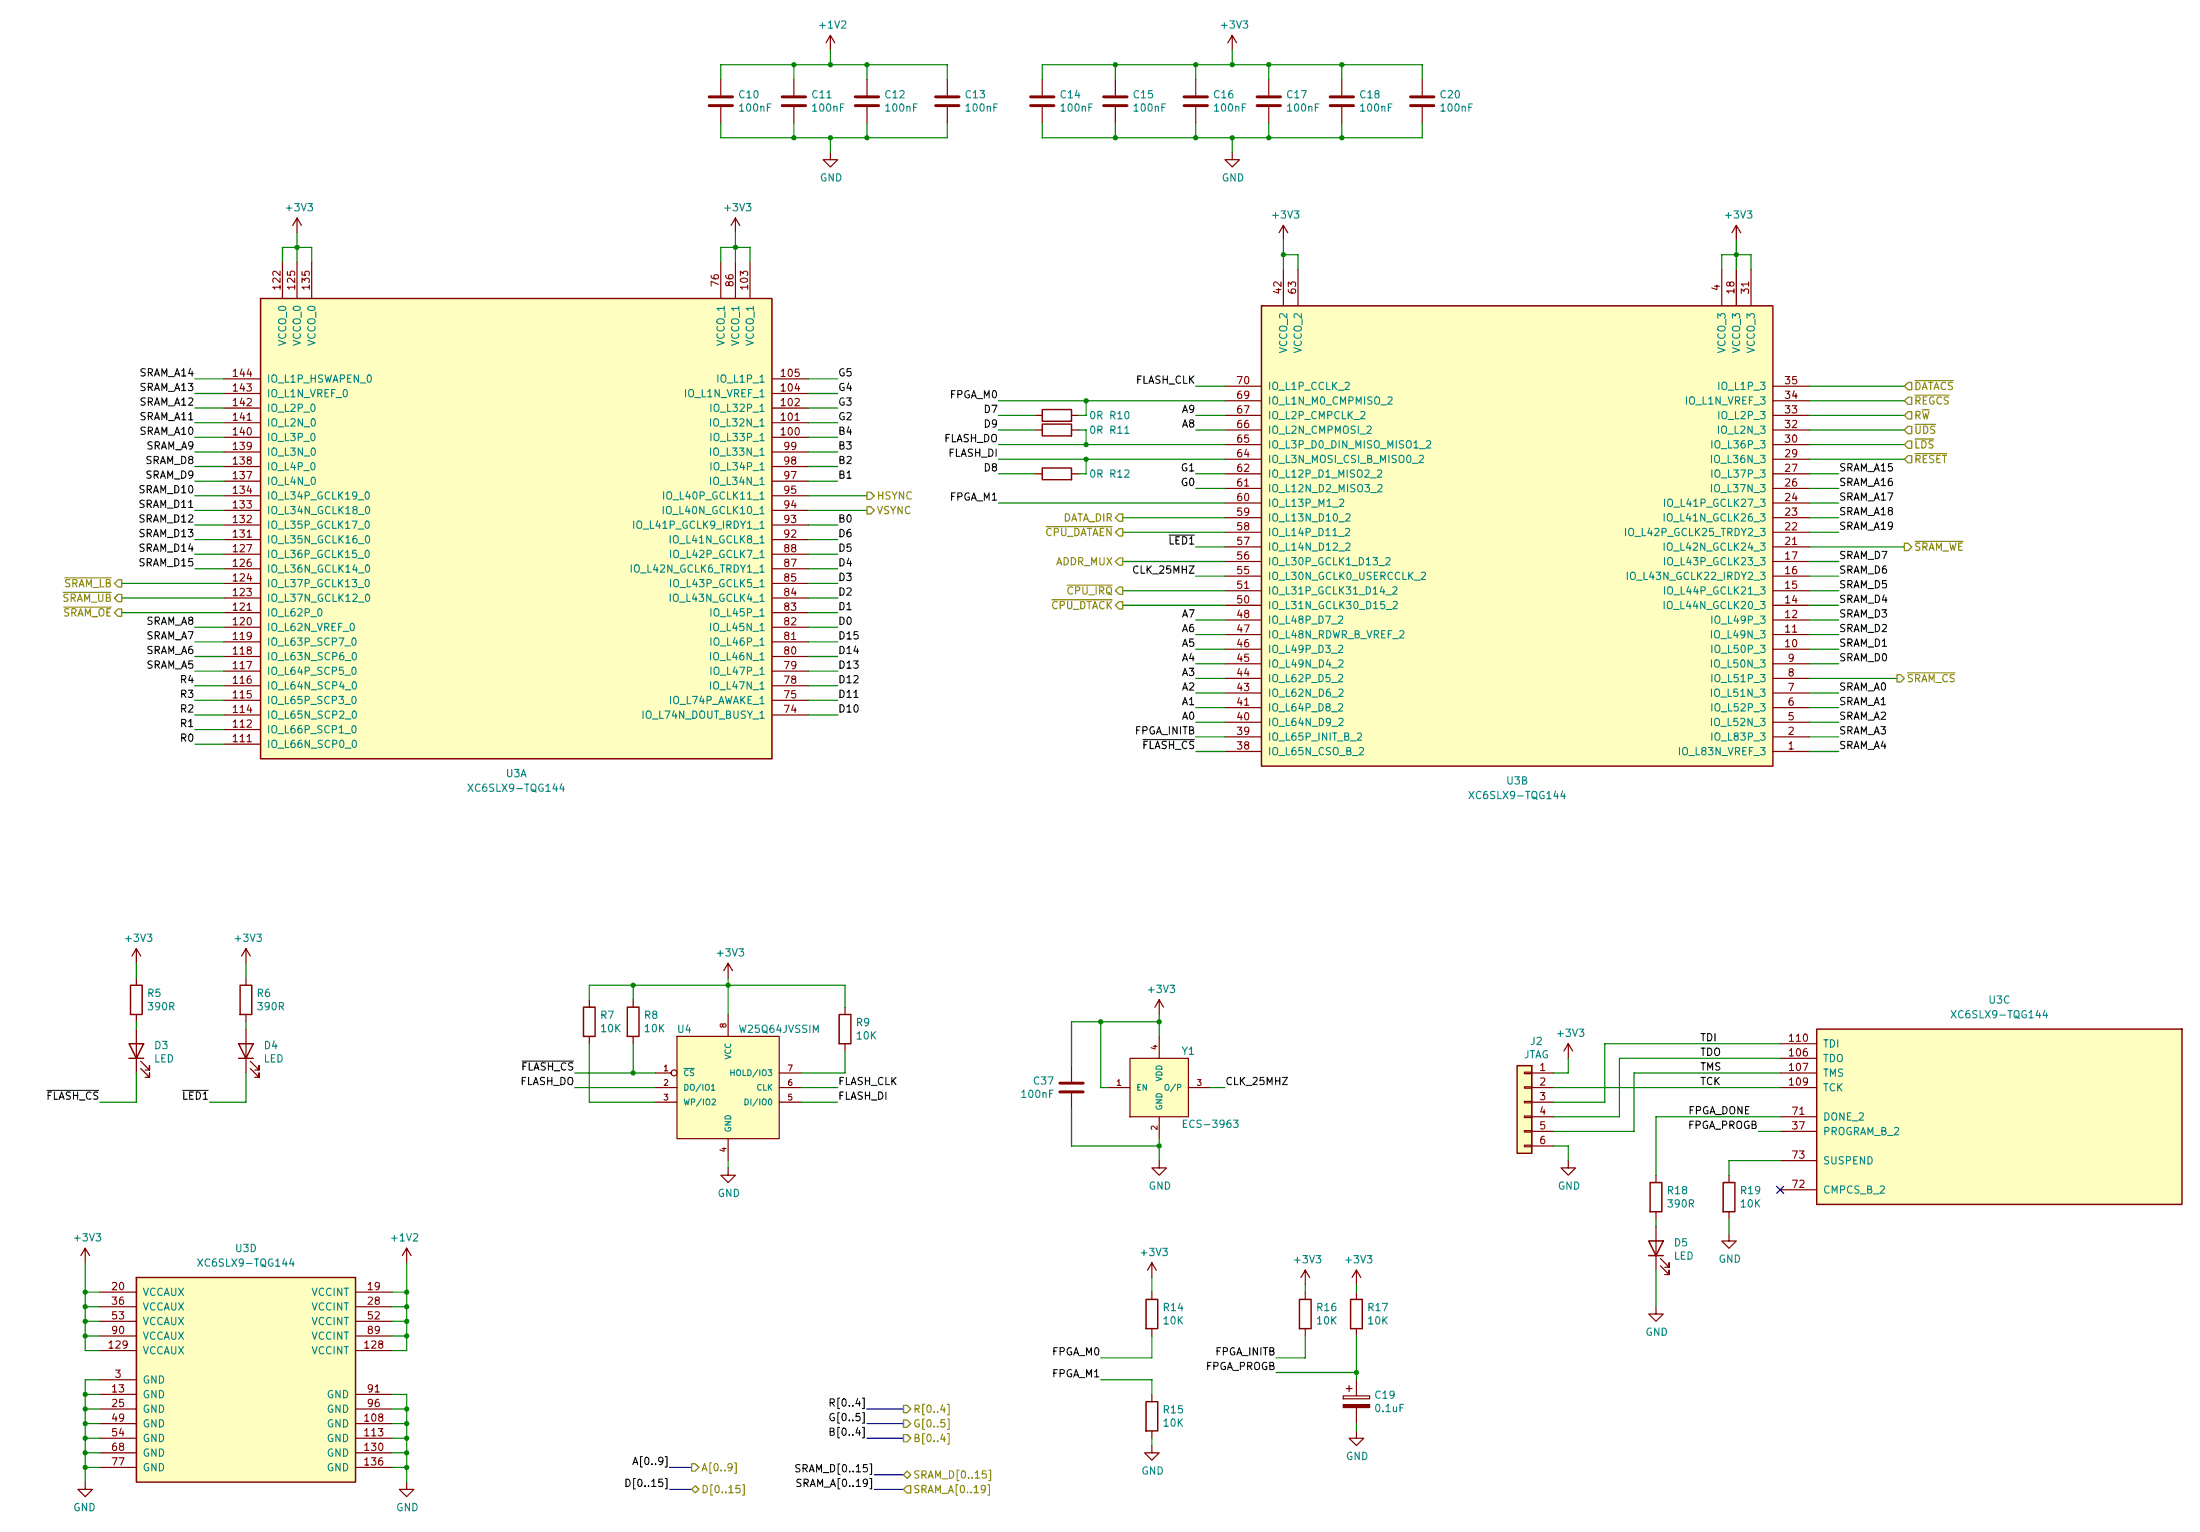
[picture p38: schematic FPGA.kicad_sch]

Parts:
C10, C11, C12, C13, C14, C15, C16, C17, C18, C20, C37: 100nF; C_0805_2012Metric
C19: 0.1uF; CP_Elec_4x5.3
D3, D4, D5: LED; LED_1206_3216Metric
J2: JTAG; PinHeader_1x06_P2.54mm_Vertical
R5, R6, R18: 390R; R_0805_2012Metric
R7, R8, R9, R14, R15, R16, R17, R19: 10K; R_0805_2012Metric
R10, R11, R12: 0R; R_0805_2012Metric
U3: XC6SLX9-TQG144; TQ144
U4: W25Q64JVSSIM; SOIC127P790X195-8N
Y1: ECS-3963; OSC_ECS-3963; PARTREV N/A

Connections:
+1V2: C10.1, C11.1, C12.1, C13.1, U3.19 (VCCINT), U3.28 (VCCINT), U3.52 (VCCINT), U3.89 (VCCINT), U3.128 (VCCINT); also elsewhere on the board
+3V3: C14.1, C15.1, C16.1, C17.1, C18.1, C20.1, C37.1, J2.1, R5.1, R6.1, R7.1, R8.1, R9.1, R14.1, R16.1, R17.1, U3.4 (VCCO_3), U3.18 (VCCO_3), U3.20 (VCCAUX), U3.31 (VCCO_3), U3.36 (VCCAUX), U3.42 (VCCO_2), U3.53 (VCCAUX), U3.63 (VCCO_2), U3.76 (VCCO_1), U3.86 (VCCO_1), U3.90 (VCCAUX), U3.103 (VCCO_1), U3.122 (VCCO_0), U3.125 (VCCO_0), U3.129 (VCCAUX), U3.135 (VCCO_0), U4.8 (VCC), Y1.1 (EN), Y1.4 (VDD); also elsewhere on the board
/FPGA/A0: U3.40 (IO_L64N_D9_2); also elsewhere on the board
/FPGA/A1: U3.41 (IO_L64P_D8_2); also elsewhere on the board
/FPGA/A2: U3.43 (IO_L62N_D6_2); also elsewhere on the board
/FPGA/A3: U3.44 (IO_L62P_D5_2); also elsewhere on the board
/FPGA/A4: U3.45 (IO_L49N_D4_2); also elsewhere on the board
/FPGA/A5: U3.46 (IO_L49P_D3_2); also elsewhere on the board
/FPGA/A6: U3.47 (IO_L48N_RDWR_B_VREF_2); also elsewhere on the board
/FPGA/A7: U3.48 (IO_L48P_D7_2); also elsewhere on the board
/FPGA/A8: U3.66 (IO_L2N_CMPMOSI_2); also elsewhere on the board
/FPGA/A9: U3.67 (IO_L2P_CMPCLK_2); also elsewhere on the board
/FPGA/ADDR_MUX: U3.56 (IO_L30P_GCLK1_D13_2); also elsewhere on the board
/FPGA/B0: U3.93 (IO_L41P_GCLK9_IRDY1_1); also elsewhere on the board
/FPGA/B1: U3.97 (IO_L34N_1); also elsewhere on the board
/FPGA/B2: U3.98 (IO_L34P_1); also elsewhere on the board
/FPGA/B3: U3.99 (IO_L33N_1); also elsewhere on the board
/FPGA/B4: U3.100 (IO_L33P_1); also elsewhere on the board
/FPGA/CLK_25MHZ: U3.55 (IO_L30N_GCLK0_USERCCLK_2), Y1.3 (O/P)
/FPGA/D0: U3.82 (IO_L45N_1); also elsewhere on the board
/FPGA/D1: U3.83 (IO_L45P_1); also elsewhere on the board
/FPGA/D2: U3.84 (IO_L43N_GCLK4_1); also elsewhere on the board
/FPGA/D3: U3.85 (IO_L43P_GCLK5_1); also elsewhere on the board
/FPGA/D4: U3.87 (IO_L42N_GCLK6_TRDY1_1); also elsewhere on the board
/FPGA/D5: U3.88 (IO_L42P_GCLK7_1); also elsewhere on the board
/FPGA/D6: U3.92 (IO_L41N_GCLK8_1); also elsewhere on the board
/FPGA/D7: R10.1; also elsewhere on the board
/FPGA/D8: R12.1; also elsewhere on the board
/FPGA/D9: R11.1; also elsewhere on the board
/FPGA/D10: U3.74 (IO_L74N_DOUT_BUSY_1); also elsewhere on the board
/FPGA/D11: U3.75 (IO_L74P_AWAKE_1); also elsewhere on the board
/FPGA/D12: U3.78 (IO_L47N_1); also elsewhere on the board
/FPGA/D13: U3.79 (IO_L47P_1); also elsewhere on the board
/FPGA/D14: U3.80 (IO_L46N_1); also elsewhere on the board
/FPGA/D15: U3.81 (IO_L46P_1); also elsewhere on the board
/FPGA/DATA_DIR: U3.59 (IO_L13N_D10_2); also elsewhere on the board
/FPGA/FLASH_CLK: U3.70 (IO_L1P_CCLK_2), U4.6 (CLK)
/FPGA/FLASH_DI: R12.2, U3.64 (IO_L3N_MOSI_CSI_B_MISO0_2), U4.5 (DI/IO0)
/FPGA/FLASH_DO: R11.2, U3.65 (IO_L3P_D0_DIN_MISO_MISO1_2), U4.2 (DO/IO1)
/FPGA/FPGA_DONE: R18.1, U3.71 (DONE_2)
/FPGA/FPGA_INITB: R16.2, U3.39 (IO_L65P_INIT_B_2)
/FPGA/FPGA_M0: R10.2, R14.2, U3.69 (IO_L1N_M0_CMPMISO_2)
/FPGA/FPGA_M1: R15.1, U3.60 (IO_L13P_M1_2)
/FPGA/FPGA_PROGB: C19.1, R17.2, U3.37 (PROGRAM_B_2)
/FPGA/G0: U3.61 (IO_L12N_D2_MISO3_2); also elsewhere on the board
/FPGA/G1: U3.62 (IO_L12P_D1_MISO2_2); also elsewhere on the board
/FPGA/G2: U3.101 (IO_L32N_1); also elsewhere on the board
/FPGA/G3: U3.102 (IO_L32P_1); also elsewhere on the board
/FPGA/G4: U3.104 (IO_L1N_VREF_1); also elsewhere on the board
/FPGA/G5: U3.105 (IO_L1P_1); also elsewhere on the board
/FPGA/HSYNC: U3.95 (IO_L40P_GCLK11_1); also elsewhere on the board
/FPGA/R0: U3.111 (IO_L66N_SCP0_0); also elsewhere on the board
/FPGA/R1: U3.112 (IO_L66P_SCP1_0); also elsewhere on the board
/FPGA/R2: U3.114 (IO_L65N_SCP2_0); also elsewhere on the board
/FPGA/R3: U3.115 (IO_L65P_SCP3_0); also elsewhere on the board
/FPGA/R4: U3.116 (IO_L64N_SCP4_0); also elsewhere on the board
/FPGA/R~W: U3.33 (IO_L2P_3); also elsewhere on the board
/FPGA/SRAM_A0: U3.7 (IO_L51N_3); also elsewhere on the board
/FPGA/SRAM_A1: U3.6 (IO_L52P_3); also elsewhere on the board
/FPGA/SRAM_A2: U3.5 (IO_L52N_3); also elsewhere on the board
/FPGA/SRAM_A3: U3.2 (IO_L83P_3); also elsewhere on the board
/FPGA/SRAM_A4: U3.1 (IO_L83N_VREF_3); also elsewhere on the board
/FPGA/SRAM_A5: U3.117 (IO_L64P_SCP5_0); also elsewhere on the board
/FPGA/SRAM_A6: U3.118 (IO_L63N_SCP6_0); also elsewhere on the board
/FPGA/SRAM_A7: U3.119 (IO_L63P_SCP7_0); also elsewhere on the board
/FPGA/SRAM_A8: U3.120 (IO_L62N_VREF_0); also elsewhere on the board
/FPGA/SRAM_A9: U3.139 (IO_L3N_0); also elsewhere on the board
/FPGA/SRAM_A10: U3.140 (IO_L3P_0); also elsewhere on the board
/FPGA/SRAM_A11: U3.141 (IO_L2N_0); also elsewhere on the board
/FPGA/SRAM_A12: U3.142 (IO_L2P_0); also elsewhere on the board
/FPGA/SRAM_A13: U3.143 (IO_L1N_VREF_0); also elsewhere on the board
/FPGA/SRAM_A14: U3.144 (IO_L1P_HSWAPEN_0); also elsewhere on the board
/FPGA/SRAM_A15: U3.27 (IO_L37P_3); also elsewhere on the board
/FPGA/SRAM_A16: U3.26 (IO_L37N_3); also elsewhere on the board
/FPGA/SRAM_A17: U3.24 (IO_L41P_GCLK27_3); also elsewhere on the board
/FPGA/SRAM_A18: U3.23 (IO_L41N_GCLK26_3); also elsewhere on the board
/FPGA/SRAM_A19: U3.22 (IO_L42P_GCLK25_TRDY2_3); also elsewhere on the board
/FPGA/SRAM_D0: U3.9 (IO_L50N_3); also elsewhere on the board
/FPGA/SRAM_D1: U3.10 (IO_L50P_3); also elsewhere on the board
/FPGA/SRAM_D2: U3.11 (IO_L49N_3); also elsewhere on the board
/FPGA/SRAM_D3: U3.12 (IO_L49P_3); also elsewhere on the board
/FPGA/SRAM_D4: U3.14 (IO_L44N_GCLK20_3); also elsewhere on the board
/FPGA/SRAM_D5: U3.15 (IO_L44P_GCLK21_3); also elsewhere on the board
/FPGA/SRAM_D6: U3.16 (IO_L43N_GCLK22_IRDY2_3); also elsewhere on the board
/FPGA/SRAM_D7: U3.17 (IO_L43P_GCLK23_3); also elsewhere on the board
/FPGA/SRAM_D8: U3.138 (IO_L4P_0); also elsewhere on the board
/FPGA/SRAM_D9: U3.137 (IO_L4N_0); also elsewhere on the board
/FPGA/SRAM_D10: U3.134 (IO_L34P_GCLK19_0); also elsewhere on the board
/FPGA/SRAM_D11: U3.133 (IO_L34N_GCLK18_0); also elsewhere on the board
/FPGA/SRAM_D12: U3.132 (IO_L35P_GCLK17_0); also elsewhere on the board
/FPGA/SRAM_D13: U3.131 (IO_L35N_GCLK16_0); also elsewhere on the board
/FPGA/SRAM_D14: U3.127 (IO_L36P_GCLK15_0); also elsewhere on the board
/FPGA/SRAM_D15: U3.126 (IO_L36N_GCLK14_0); also elsewhere on the board
/FPGA/TCK: J2.2, U3.109 (TCK)
/FPGA/TDI: J2.3, U3.110 (TDI)
/FPGA/TDO: J2.4, U3.106 (TDO)
/FPGA/TMS: J2.5, U3.107 (TMS)
/FPGA/VSYNC: U3.94 (IO_L40N_GCLK10_1); also elsewhere on the board
/FPGA/~CPU_DATAEN: U3.58 (IO_L14P_D11_2); also elsewhere on the board
/FPGA/~DATACS: U3.35 (IO_L1P_3); also elsewhere on the board
/FPGA/~FLASH_CS: D3.1 (K), R8.2, U3.38 (IO_L65N_CSO_B_2), U4.1 (~CS)
/FPGA/~LDS: U3.30 (IO_L36P_3); also elsewhere on the board
/FPGA/~LED1: D4.1 (K), U3.57 (IO_L14N_D12_2)
/FPGA/~REGCS: U3.34 (IO_L1N_VREF_3); also elsewhere on the board
/FPGA/~RESET: U3.29 (IO_L36N_3); also elsewhere on the board
/FPGA/~SRAM_CS: U3.8 (IO_L51P_3); also elsewhere on the board
/FPGA/~SRAM_LB: U3.124 (IO_L37P_GCLK13_0); also elsewhere on the board
/FPGA/~SRAM_OE: U3.121 (IO_L62P_0); also elsewhere on the board
/FPGA/~SRAM_UB: U3.123 (IO_L37N_GCLK12_0); also elsewhere on the board
/FPGA/~SRAM_WE: U3.21 (IO_L42N_GCLK24_3); also elsewhere on the board
/FPGA/~UDS: U3.32 (IO_L2N_3); also elsewhere on the board
/~CPU_DTACK: U3.50 (IO_L31N_GCLK30_D15_2); also elsewhere on the board
/~CPU_IRQ: U3.51 (IO_L31P_GCLK31_D14_2); also elsewhere on the board
GND: C10.2, C11.2, C12.2, C13.2, C14.2, C15.2, C16.2, C17.2, C18.2, C19.2, C20.2, C37.2, D5.1 (K), J2.6, R15.2, R19.2, U3.3 (GND), U3.13 (GND), U3.25 (GND), U3.49 (GND), U3.54 (GND), U3.68 (GND), U3.77 (GND), U3.91 (GND), U3.96 (GND), U3.108 (GND), U3.113 (GND), U3.130 (GND), U3.136 (GND), U4.4 (GND), Y1.2 (GND); also elsewhere on the board
unnamed: D3.2 (A), R5.2
unnamed: D4.2 (A), R6.2
unnamed: D5.2 (A), R18.2
unnamed: R19.1, U3.73 (SUSPEND)
unnamed: R9.2, U4.7 (HOLD/IO3)
unnamed: R7.2, U4.3 (WP/IO2)

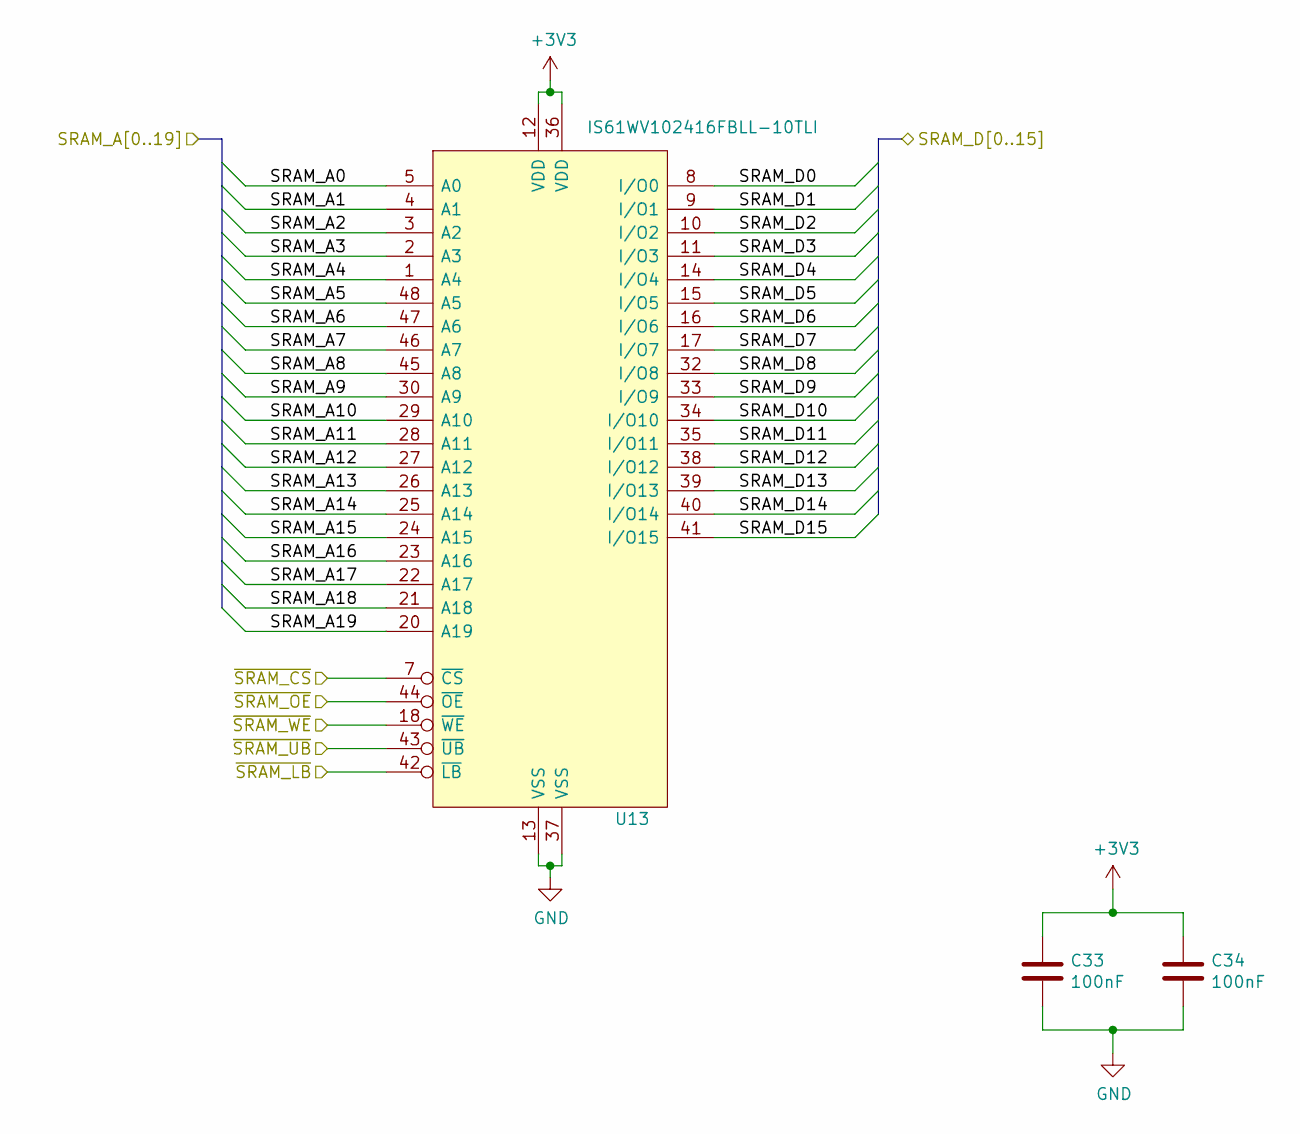
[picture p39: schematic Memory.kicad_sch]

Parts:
C33, C34: 100nF; C_0805_2012Metric
U13: IS61WV102416FBLL-10TLI; SOP50P2000X120-48N; Manufacturer_Part_Number IS61WV102416FBLL-10TLI; Mouser Part Number 870-61WV12416FBL1TLI

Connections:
+3V3: C33.1, C34.1, U13.12 (VDD), U13.36 (VDD); also elsewhere on the board
/FPGA/SRAM_A0: U13.5 (A0); also elsewhere on the board
/FPGA/SRAM_A1: U13.4 (A1); also elsewhere on the board
/FPGA/SRAM_A2: U13.3 (A2); also elsewhere on the board
/FPGA/SRAM_A3: U13.2 (A3); also elsewhere on the board
/FPGA/SRAM_A4: U13.1 (A4); also elsewhere on the board
/FPGA/SRAM_A5: U13.48 (A5); also elsewhere on the board
/FPGA/SRAM_A6: U13.47 (A6); also elsewhere on the board
/FPGA/SRAM_A7: U13.46 (A7); also elsewhere on the board
/FPGA/SRAM_A8: U13.45 (A8); also elsewhere on the board
/FPGA/SRAM_A9: U13.30 (A9); also elsewhere on the board
/FPGA/SRAM_A10: U13.29 (A10); also elsewhere on the board
/FPGA/SRAM_A11: U13.28 (A11); also elsewhere on the board
/FPGA/SRAM_A12: U13.27 (A12); also elsewhere on the board
/FPGA/SRAM_A13: U13.26 (A13); also elsewhere on the board
/FPGA/SRAM_A14: U13.25 (A14); also elsewhere on the board
/FPGA/SRAM_A15: U13.24 (A15); also elsewhere on the board
/FPGA/SRAM_A16: U13.23 (A16); also elsewhere on the board
/FPGA/SRAM_A17: U13.22 (A17); also elsewhere on the board
/FPGA/SRAM_A18: U13.21 (A18); also elsewhere on the board
/FPGA/SRAM_A19: U13.20 (A19); also elsewhere on the board
/FPGA/SRAM_D0: U13.8 (I/O0); also elsewhere on the board
/FPGA/SRAM_D1: U13.9 (I/O1); also elsewhere on the board
/FPGA/SRAM_D2: U13.10 (I/O2); also elsewhere on the board
/FPGA/SRAM_D3: U13.11 (I/O3); also elsewhere on the board
/FPGA/SRAM_D4: U13.14 (I/O4); also elsewhere on the board
/FPGA/SRAM_D5: U13.15 (I/O5); also elsewhere on the board
/FPGA/SRAM_D6: U13.16 (I/O6); also elsewhere on the board
/FPGA/SRAM_D7: U13.17 (I/O7); also elsewhere on the board
/FPGA/SRAM_D8: U13.32 (I/O8); also elsewhere on the board
/FPGA/SRAM_D9: U13.33 (I/O9); also elsewhere on the board
/FPGA/SRAM_D10: U13.34 (I/O10); also elsewhere on the board
/FPGA/SRAM_D11: U13.35 (I/O11); also elsewhere on the board
/FPGA/SRAM_D12: U13.38 (I/O12); also elsewhere on the board
/FPGA/SRAM_D13: U13.39 (I/O13); also elsewhere on the board
/FPGA/SRAM_D14: U13.40 (I/O14); also elsewhere on the board
/FPGA/SRAM_D15: U13.41 (I/O15); also elsewhere on the board
/FPGA/~SRAM_CS: U13.7 (~CS); also elsewhere on the board
/FPGA/~SRAM_LB: U13.42 (~LB); also elsewhere on the board
/FPGA/~SRAM_OE: U13.44 (~OE); also elsewhere on the board
/FPGA/~SRAM_UB: U13.43 (~UB); also elsewhere on the board
/FPGA/~SRAM_WE: U13.18 (~WE); also elsewhere on the board
GND: C33.2, C34.2, U13.13 (VSS), U13.37 (VSS); also elsewhere on the board

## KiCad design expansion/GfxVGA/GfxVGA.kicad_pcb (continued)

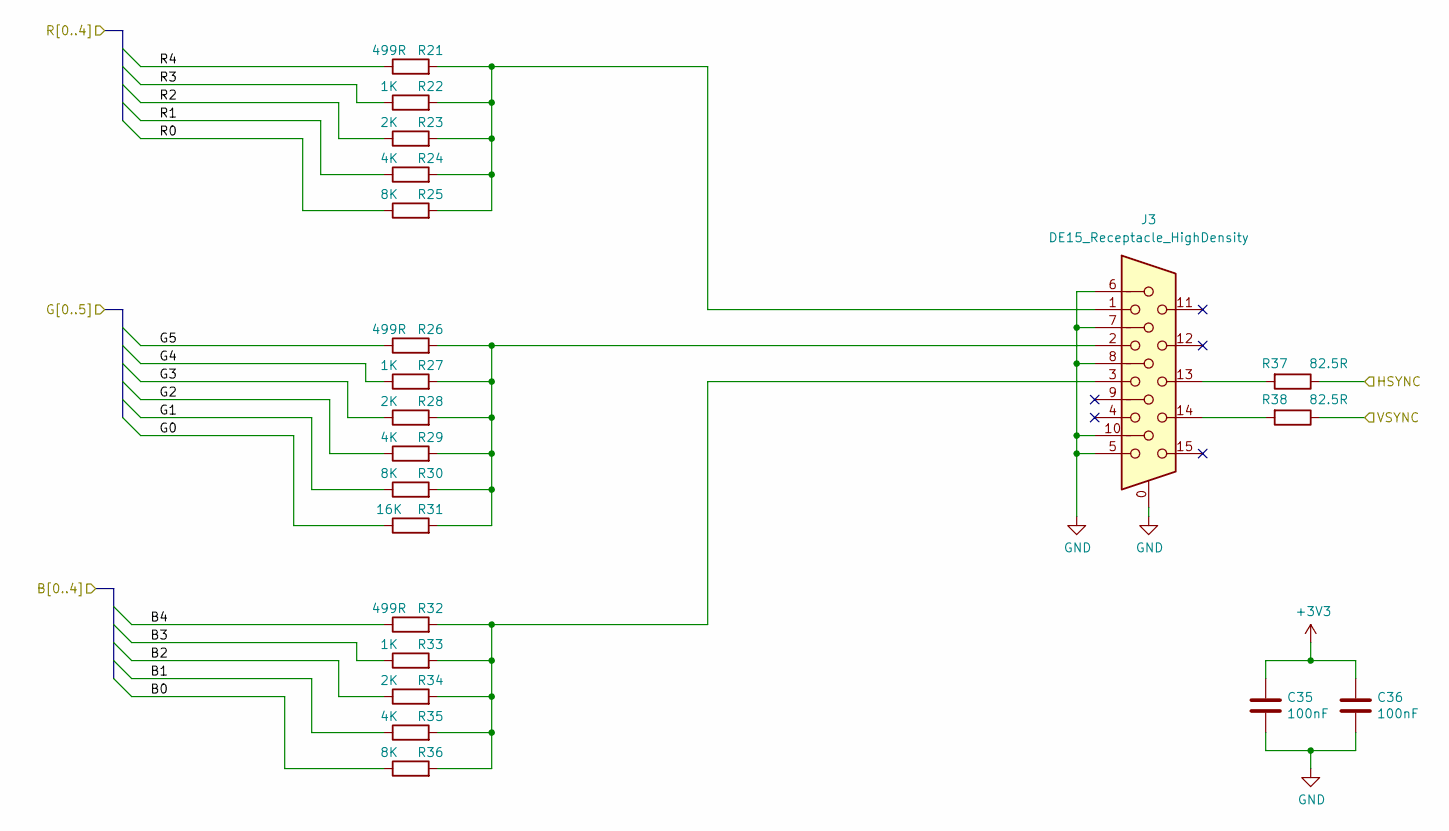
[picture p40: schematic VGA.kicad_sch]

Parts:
C35, C36: 100nF; C_0805_2012Metric
J3: DE15_Receptacle_HighDensity; DSUB-15-HD_Female_Horizontal_P2.29x1.98mm_EdgePinOffset3.03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
R21, R26, R32: 499R; R_0805_2012Metric
R22, R27, R33: 1K; R_0805_2012Metric
R23, R28, R34: 2K; R_0805_2012Metric
R24, R29, R35: 4K; R_0805_2012Metric
R25, R30, R36: 8K; R_0805_2012Metric
R31: 16K; R_0805_2012Metric
R37, R38: 82.5R; R_0805_2012Metric

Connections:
+3V3: C35.1, C36.1; also elsewhere on the board
/FPGA/B0: R36.1; also elsewhere on the board
/FPGA/B1: R35.1; also elsewhere on the board
/FPGA/B2: R34.1; also elsewhere on the board
/FPGA/B3: R33.1; also elsewhere on the board
/FPGA/B4: R32.1; also elsewhere on the board
/FPGA/G0: R31.1; also elsewhere on the board
/FPGA/G1: R30.1; also elsewhere on the board
/FPGA/G2: R29.1; also elsewhere on the board
/FPGA/G3: R28.1; also elsewhere on the board
/FPGA/G4: R27.1; also elsewhere on the board
/FPGA/G5: R26.1; also elsewhere on the board
/FPGA/HSYNC: R37.1; also elsewhere on the board
/FPGA/R0: R25.1; also elsewhere on the board
/FPGA/R1: R24.1; also elsewhere on the board
/FPGA/R2: R23.1; also elsewhere on the board
/FPGA/R3: R22.1; also elsewhere on the board
/FPGA/R4: R21.1; also elsewhere on the board
/FPGA/VSYNC: R38.1; also elsewhere on the board
GND: C35.2, C36.2, J3.0, J3.5, J3.6, J3.7, J3.8, J3.10; also elsewhere on the board
unnamed: J3.1, R21.2, R22.2, R23.2, R24.2, R25.2
unnamed: J3.2, R26.2, R27.2, R28.2, R29.2, R30.2, R31.2
unnamed: J3.3, R32.2, R33.2, R34.2, R35.2, R36.2
unnamed: J3.13, R37.2
unnamed: J3.14, R38.2

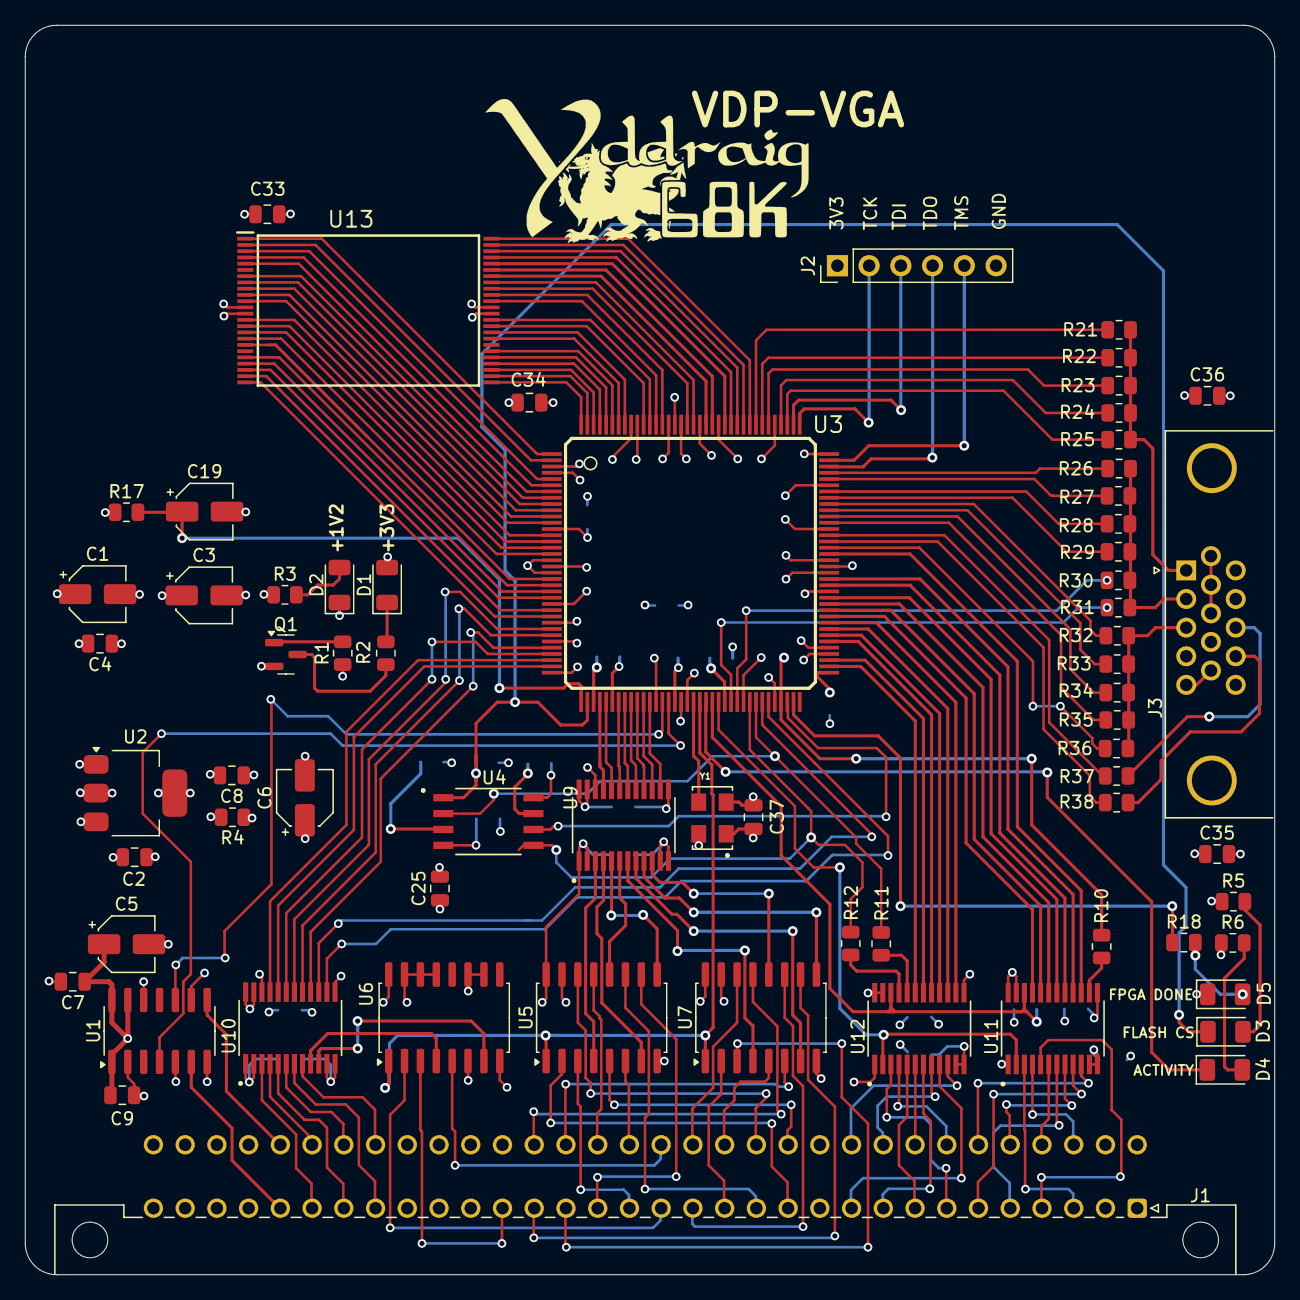
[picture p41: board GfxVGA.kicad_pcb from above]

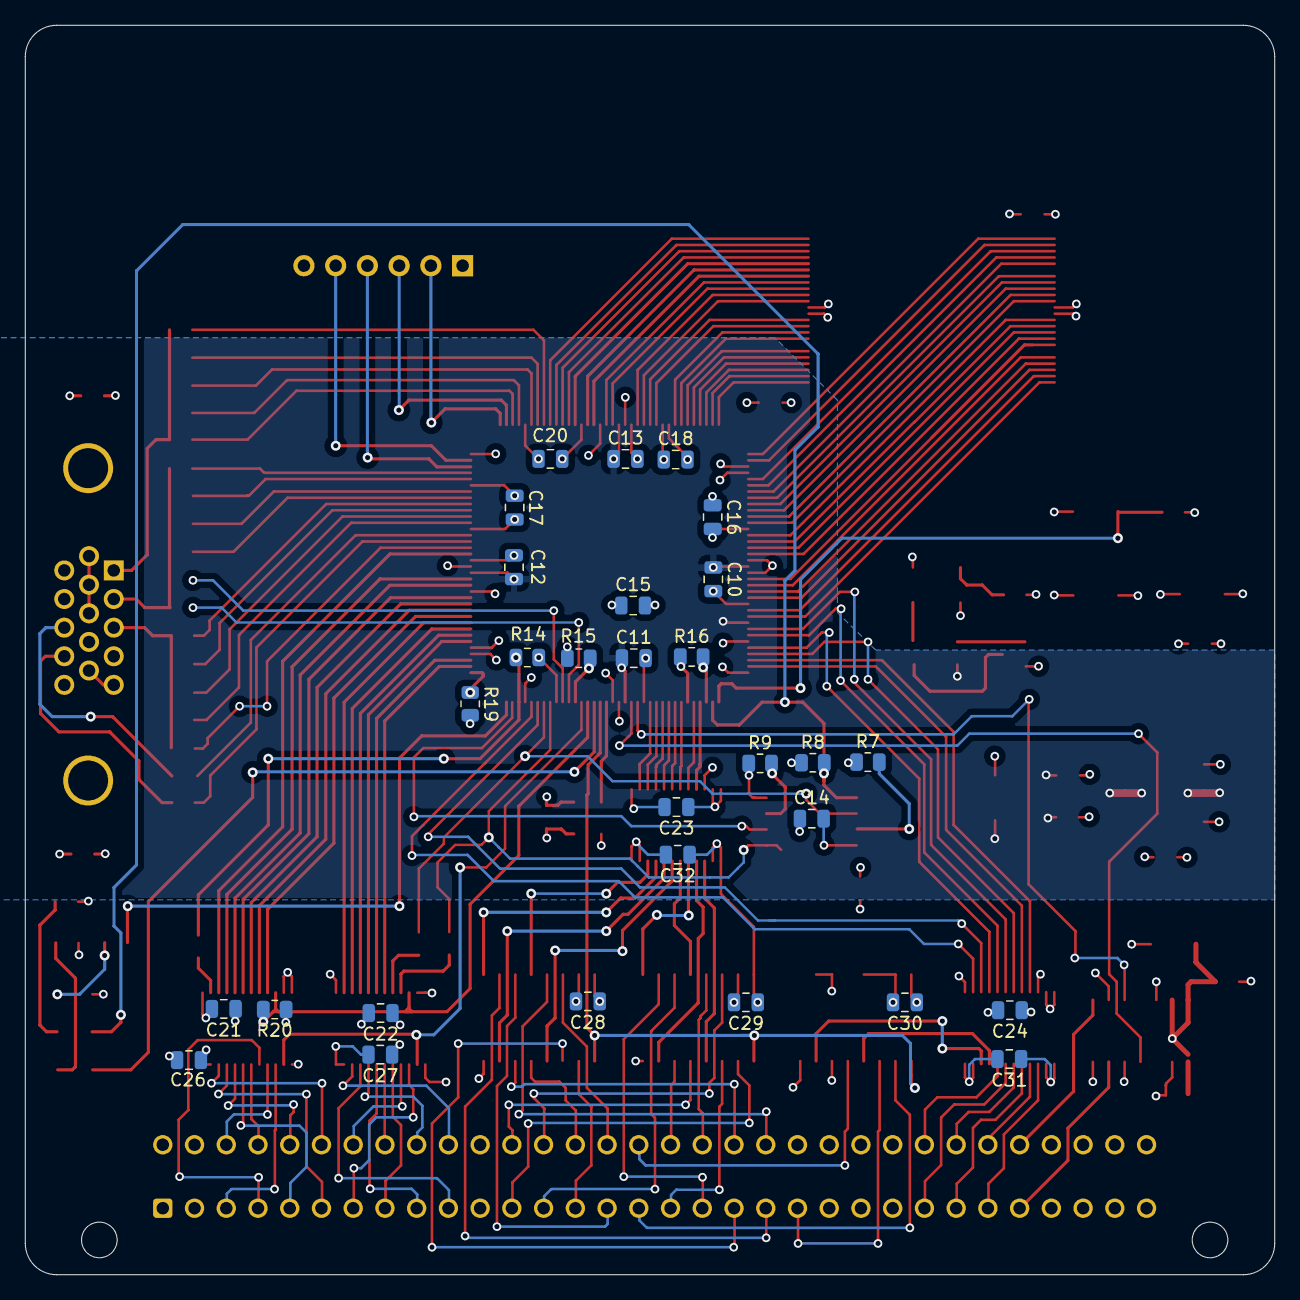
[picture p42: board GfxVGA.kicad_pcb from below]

Board: 4 copper layers, 100.0 x 100.0 mm, 97 parts (29 on the bottom side), 183 nets.

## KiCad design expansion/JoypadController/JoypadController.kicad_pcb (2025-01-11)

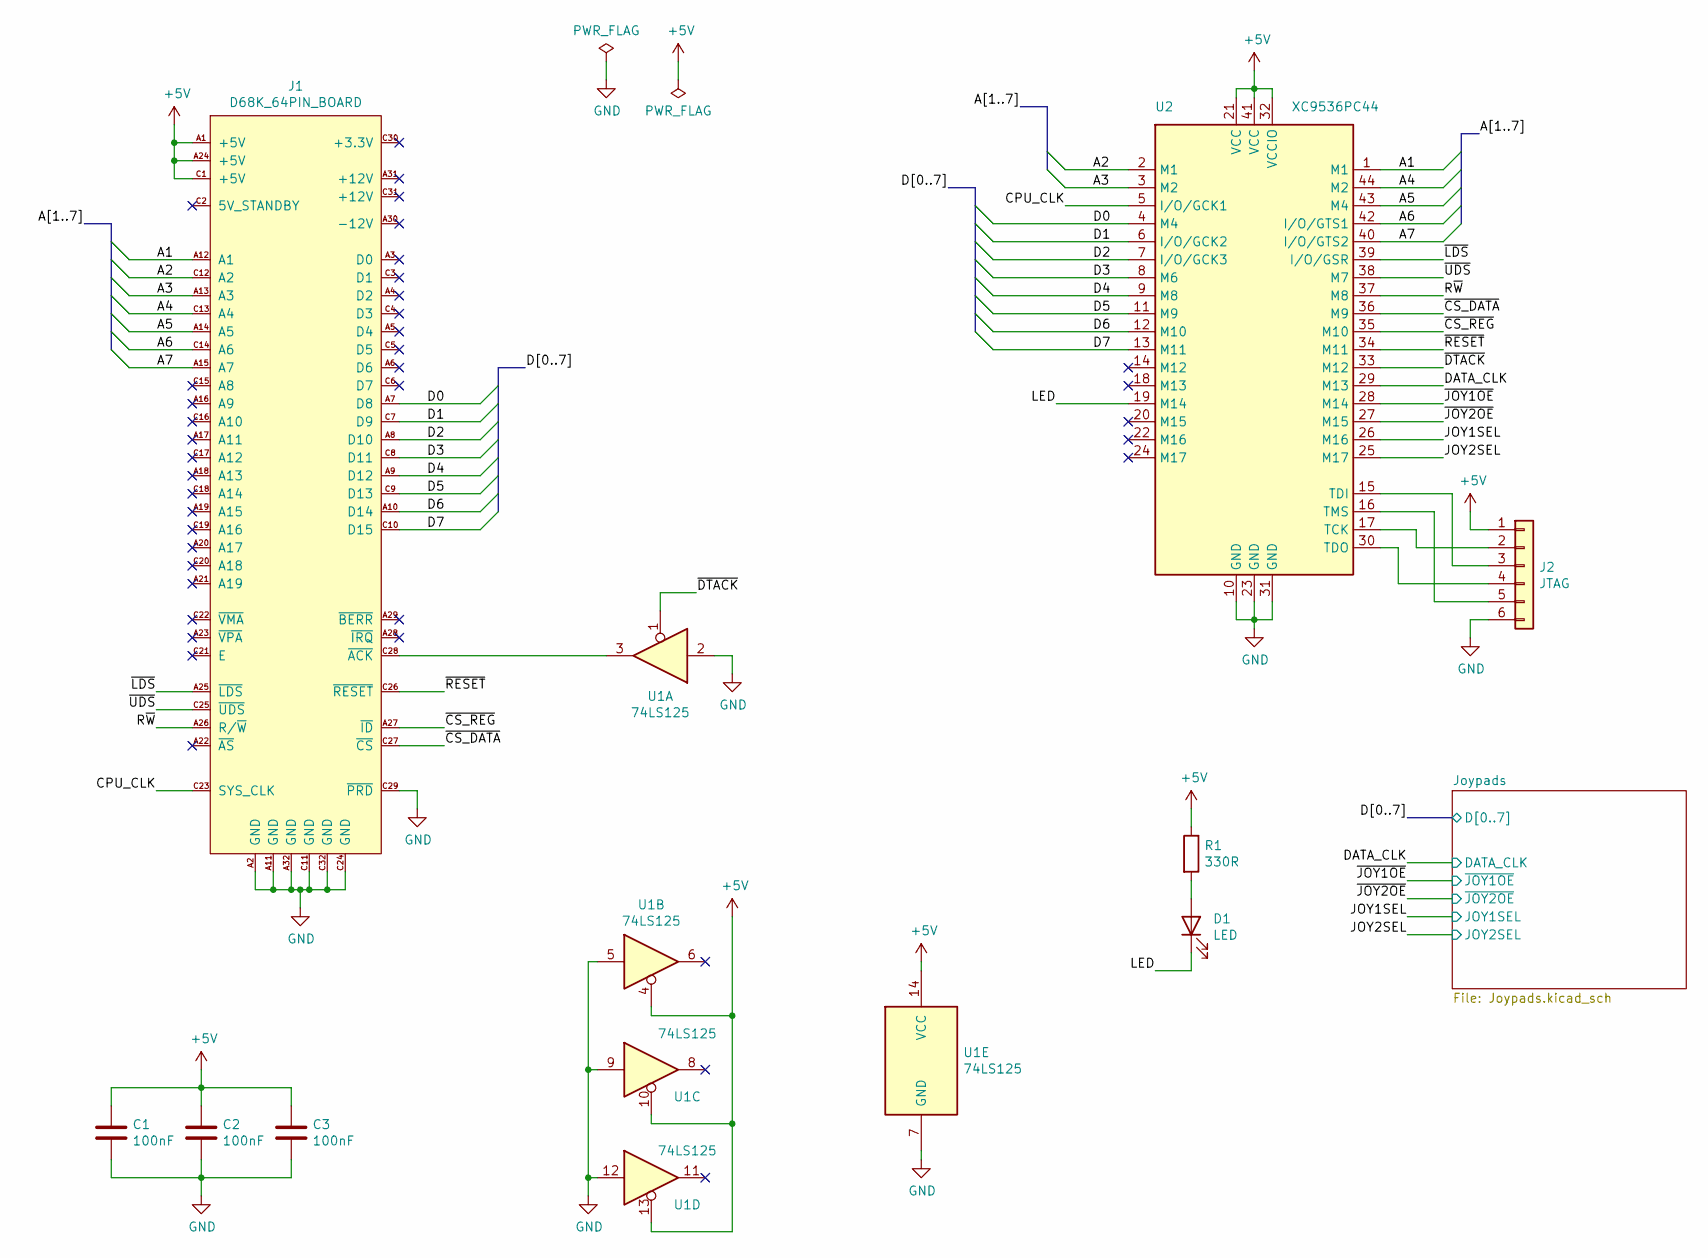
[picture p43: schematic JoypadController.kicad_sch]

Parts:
C1, C2, C3: 100nF; C_Disc_D5.0mm_W2.5mm_P2.50mm
D1: LED; LED_D5.0mm
J1: D68K_64PIN_BOARD; DIN41612_C_2x32_Male_Horizontal_THT
J2: JTAG; PinHeader_1x06_P2.54mm_Vertical
R1: 330R; R_Axial_DIN0207_L6.3mm_D2.5mm_P10.16mm_Horizontal
U1: 74LS125; DIP-14_W7.62mm_Socket
U2: XC9536PC44; PLCC-44

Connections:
+5V: C1.1, C2.1, C3.1, J1.A1 (+5V), J1.A24 (+5V), J1.C1 (+5V), J2.1, R1.1, U1.4, U1.10, U1.13, U1.14 (VCC), U2.21 (VCC), U2.32 (VCCIO), U2.41 (VCC); also elsewhere on the board
/A1: J1.A12 (A1), U2.1 (M1)
/A2: J1.C12 (A2), U2.2 (M1)
/A3: J1.A13 (A3), U2.3 (M2)
/A4: J1.C13 (A4), U2.44 (M2)
/A5: J1.A14 (A5), U2.43 (M4)
/A6: J1.C14 (A6), U2.42 (I/O/GTS1)
/A7: J1.A15 (A7), U2.40 (I/O/GTS2)
/CPU_CLK: J1.C23 (SYS_CLK), U2.5 (I/O/GCK1)
/D0: J1.A7 (D8), U2.4 (M4); also elsewhere on the board
/D1: J1.C7 (D9), U2.6 (I/O/GCK2); also elsewhere on the board
/D2: J1.A8 (D10), U2.7 (I/O/GCK3); also elsewhere on the board
/D3: J1.C8 (D11), U2.8 (M6); also elsewhere on the board
/D4: J1.A9 (D12), U2.9 (M8); also elsewhere on the board
/D5: J1.C9 (D13), U2.11 (M9); also elsewhere on the board
/D6: J1.A10 (D14), U2.12 (M10); also elsewhere on the board
/D7: J1.C10 (D15), U2.13 (M11); also elsewhere on the board
/DATA_CLK: U2.29 (M13); also elsewhere on the board
/JOY1SEL: U2.26 (M16); also elsewhere on the board
/JOY2SEL: U2.25 (M17); also elsewhere on the board
/LED: D1.1 (K), U2.19 (M14)
/R~W: J1.A26 (R/~W), U2.37 (M8)
/~CS_DATA: J1.C27 (~CS), U2.36 (M9)
/~CS_REG: J1.A27 (~ID), U2.35 (M10)
/~DTACK: U1.1, U2.33 (M12)
/~JOY1OE: U2.28 (M14); also elsewhere on the board
/~JOY2OE: U2.27 (M15); also elsewhere on the board
/~LDS: J1.A25 (~LDS), U2.39 (I/O/GSR)
/~RESET: J1.C26 (~RESET), U2.34 (M11)
/~UDS: J1.C25 (~UDS), U2.38 (M7)
GND: C1.2, C2.2, C3.2, J1.A2 (GND), J1.A11 (GND), J1.A32 (GND), J1.C11 (GND), J1.C24 (GND), J1.C29 (~PRD), J1.C32 (GND), J2.6, U1.2, U1.5, U1.7 (GND), U1.9, U1.12, U2.10 (GND), U2.23 (GND), U2.31 (GND); also elsewhere on the board
unnamed: D1.2 (A), R1.2
unnamed: J1.C28 (~ACK), U1.3
unnamed: J2.2, U2.17 (TCK)
unnamed: J2.3, U2.15 (TDI)
unnamed: J2.4, U2.30 (TDO)
unnamed: J2.5, U2.16 (TMS)

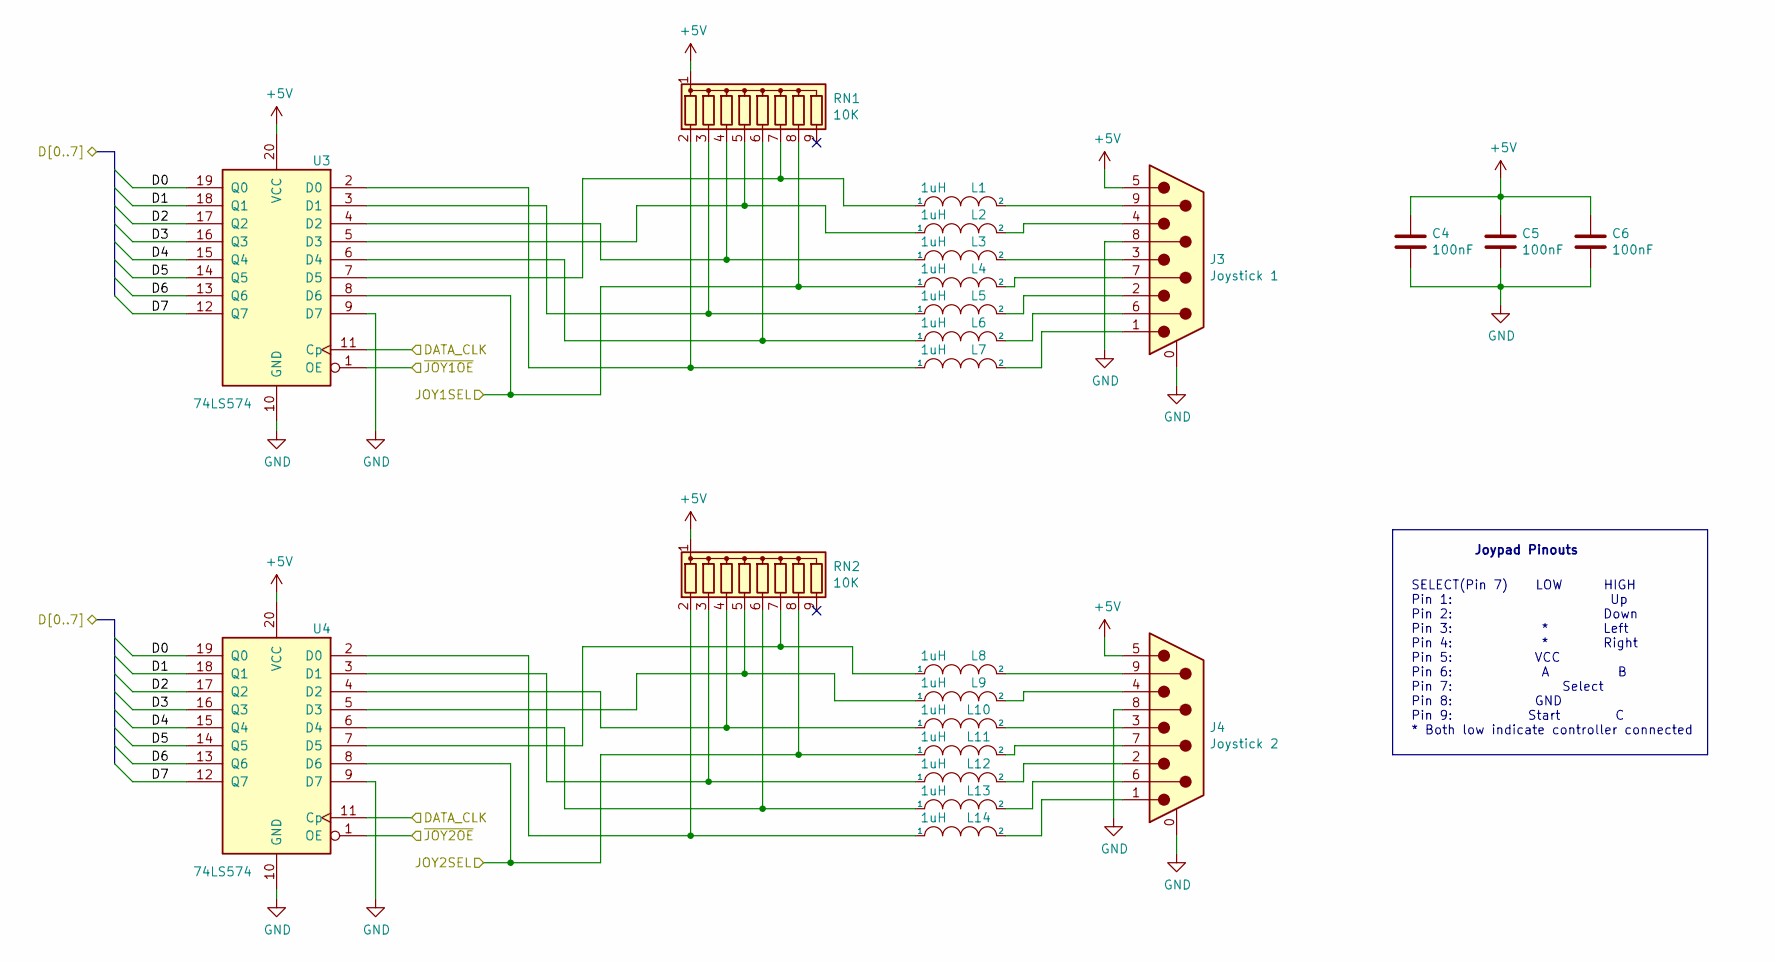
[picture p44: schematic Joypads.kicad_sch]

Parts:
C4, C5, C6: 100nF; C_Disc_D5.0mm_W2.5mm_P2.50mm
J3: Joystick 1; DSUB-9_Male_Horizontal_P2.77x2.84mm_EdgePinOffset4.94mm_Hou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
J4: Joystick 2; DSUB-9_Male_Horizontal_P2.77x2.84mm_EdgePinOffset4.94mm_Hou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
L1, L2, L3, L4, L5, L6, L7, L8, L9, L10, L11, L12, L13, L14: 1uH; L_Axial_L6.6mm_D2.7mm_P10.16mm_Horizontal_Vishay_IM-2
RN1, RN2: 10K; R_Array_SIP9
U3, U4: 74LS574; DIP-20_W7.62mm_Socket

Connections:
+5V: C4.1, C5.1, C6.1, J3.5, J4.5, RN1.1 (common), RN2.1 (common), U3.20 (VCC), U4.20 (VCC); also elsewhere on the board
/D0: U3.19 (Q0), U4.19 (Q0); also elsewhere on the board
/D1: U3.18 (Q1), U4.18 (Q1); also elsewhere on the board
/D2: U3.17 (Q2), U4.17 (Q2); also elsewhere on the board
/D3: U3.16 (Q3), U4.16 (Q3); also elsewhere on the board
/D4: U3.15 (Q4), U4.15 (Q4); also elsewhere on the board
/D5: U3.14 (Q5), U4.14 (Q5); also elsewhere on the board
/D6: U3.13 (Q6), U4.13 (Q6); also elsewhere on the board
/D7: U3.12 (Q7), U4.12 (Q7); also elsewhere on the board
/DATA_CLK: U3.11 (Cp), U4.11 (Cp); also elsewhere on the board
/JOY1SEL: L4.1, RN1.8 (R7), U3.8 (D6); also elsewhere on the board
/JOY2SEL: L11.1, RN2.8 (R7), U4.8 (D6); also elsewhere on the board
/~JOY1OE: U3.1 (OE); also elsewhere on the board
/~JOY2OE: U4.1 (OE); also elsewhere on the board
GND: C4.2, C5.2, C6.2, J3.0 (PAD), J3.8, J4.0 (PAD), J4.8, U3.9 (D7), U3.10 (GND), U4.9 (D7), U4.10 (GND); also elsewhere on the board
unnamed: J3.1, L7.2
unnamed: J3.2, L5.2
unnamed: J3.3, L3.2
unnamed: J3.4, L2.2
unnamed: J3.6, L6.2
unnamed: J3.7, L4.2
unnamed: J3.9, L1.2
unnamed: J4.1, L14.2
unnamed: J4.2, L12.2
unnamed: J4.3, L10.2
unnamed: J4.4, L9.2
unnamed: J4.6, L13.2
unnamed: J4.7, L11.2
unnamed: J4.9, L8.2
unnamed: L1.1, RN1.7 (R6), U3.7 (D5)
unnamed: L2.1, RN1.5 (R4), U3.5 (D3)
unnamed: L3.1, RN1.4 (R3), U3.4 (D2)
unnamed: L5.1, RN1.3 (R2), U3.3 (D1)
unnamed: L6.1, RN1.6 (R5), U3.6 (D4)
unnamed: L7.1, RN1.2 (R1), U3.2 (D0)
unnamed: L8.1, RN2.7 (R6), U4.7 (D5)
unnamed: L9.1, RN2.5 (R4), U4.5 (D3)
unnamed: L10.1, RN2.4 (R3), U4.4 (D2)
unnamed: L12.1, RN2.3 (R2), U4.3 (D1)
unnamed: L13.1, RN2.6 (R5), U4.6 (D4)
unnamed: L14.1, RN2.2 (R1), U4.2 (D0)

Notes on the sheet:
SELECT(Pin 7) LOW HIGH Pin 1: Up Pin 2: Down Pin 3: * Left Pin 4: * Right Pin 5: VCC Pin 6: A B Pin 7: Select Pin 8: GND Pin 9: Start C * Both low indicate controller connected
Joypad Pinouts

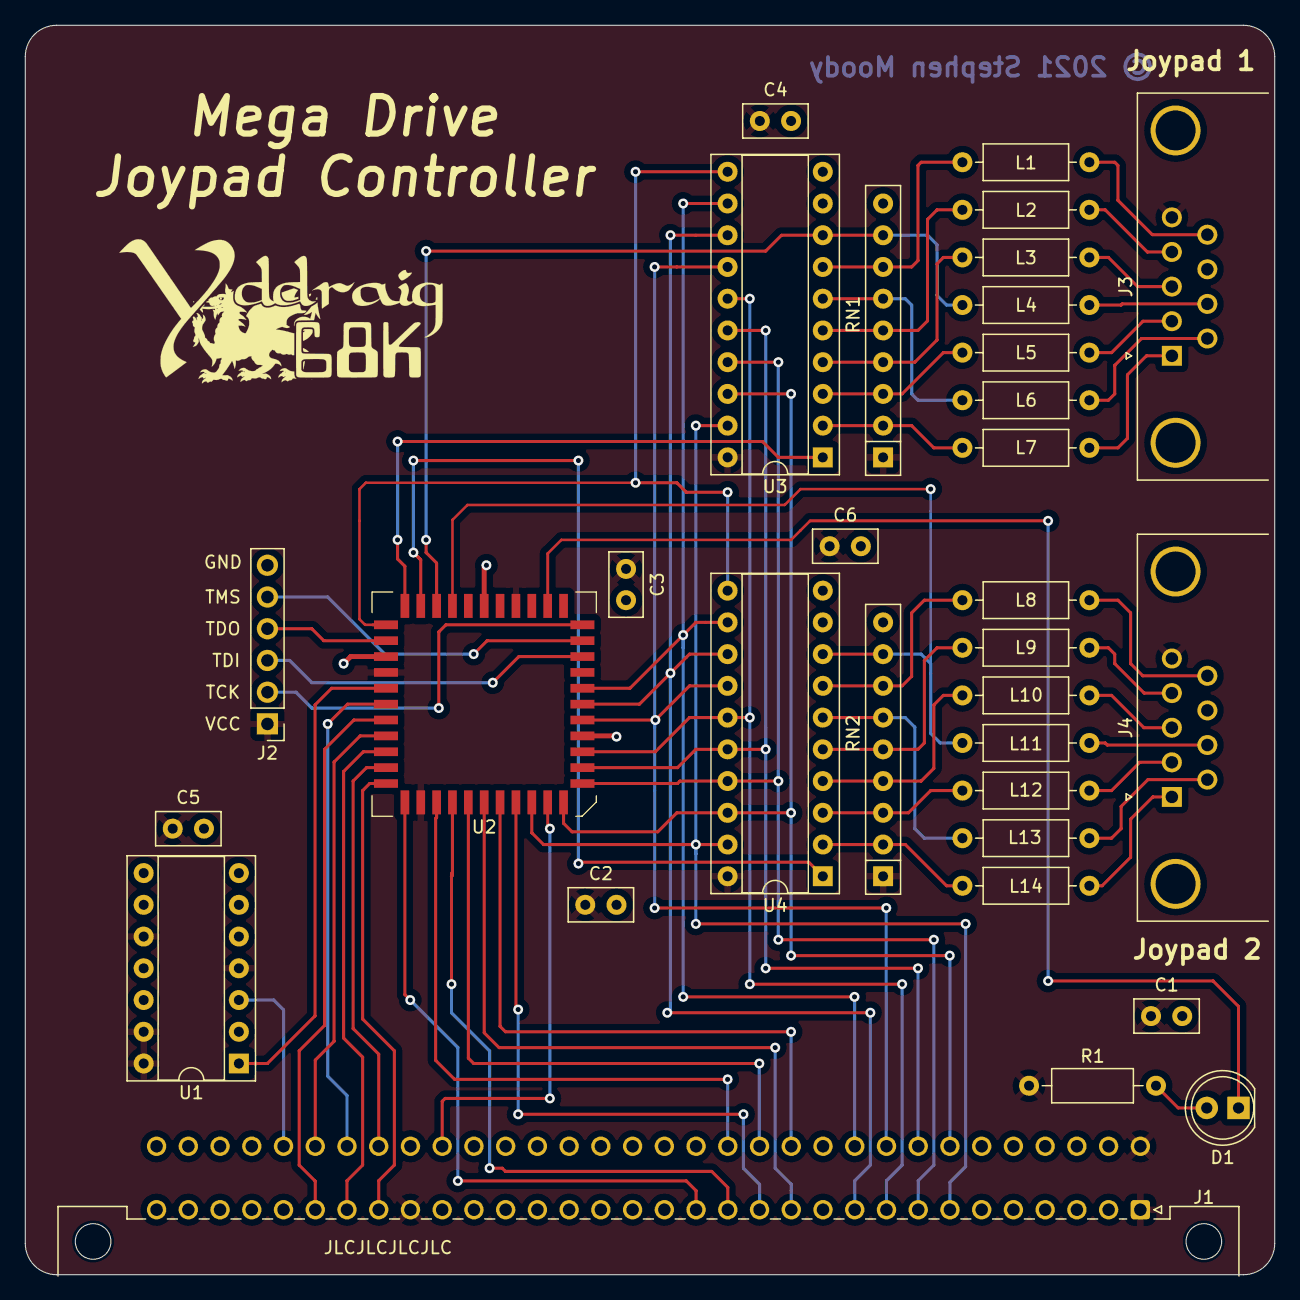
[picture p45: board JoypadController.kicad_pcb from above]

Board: 2 copper layers, 100.0 x 100.0 mm, 32 parts (0 on the bottom side), 63 nets.

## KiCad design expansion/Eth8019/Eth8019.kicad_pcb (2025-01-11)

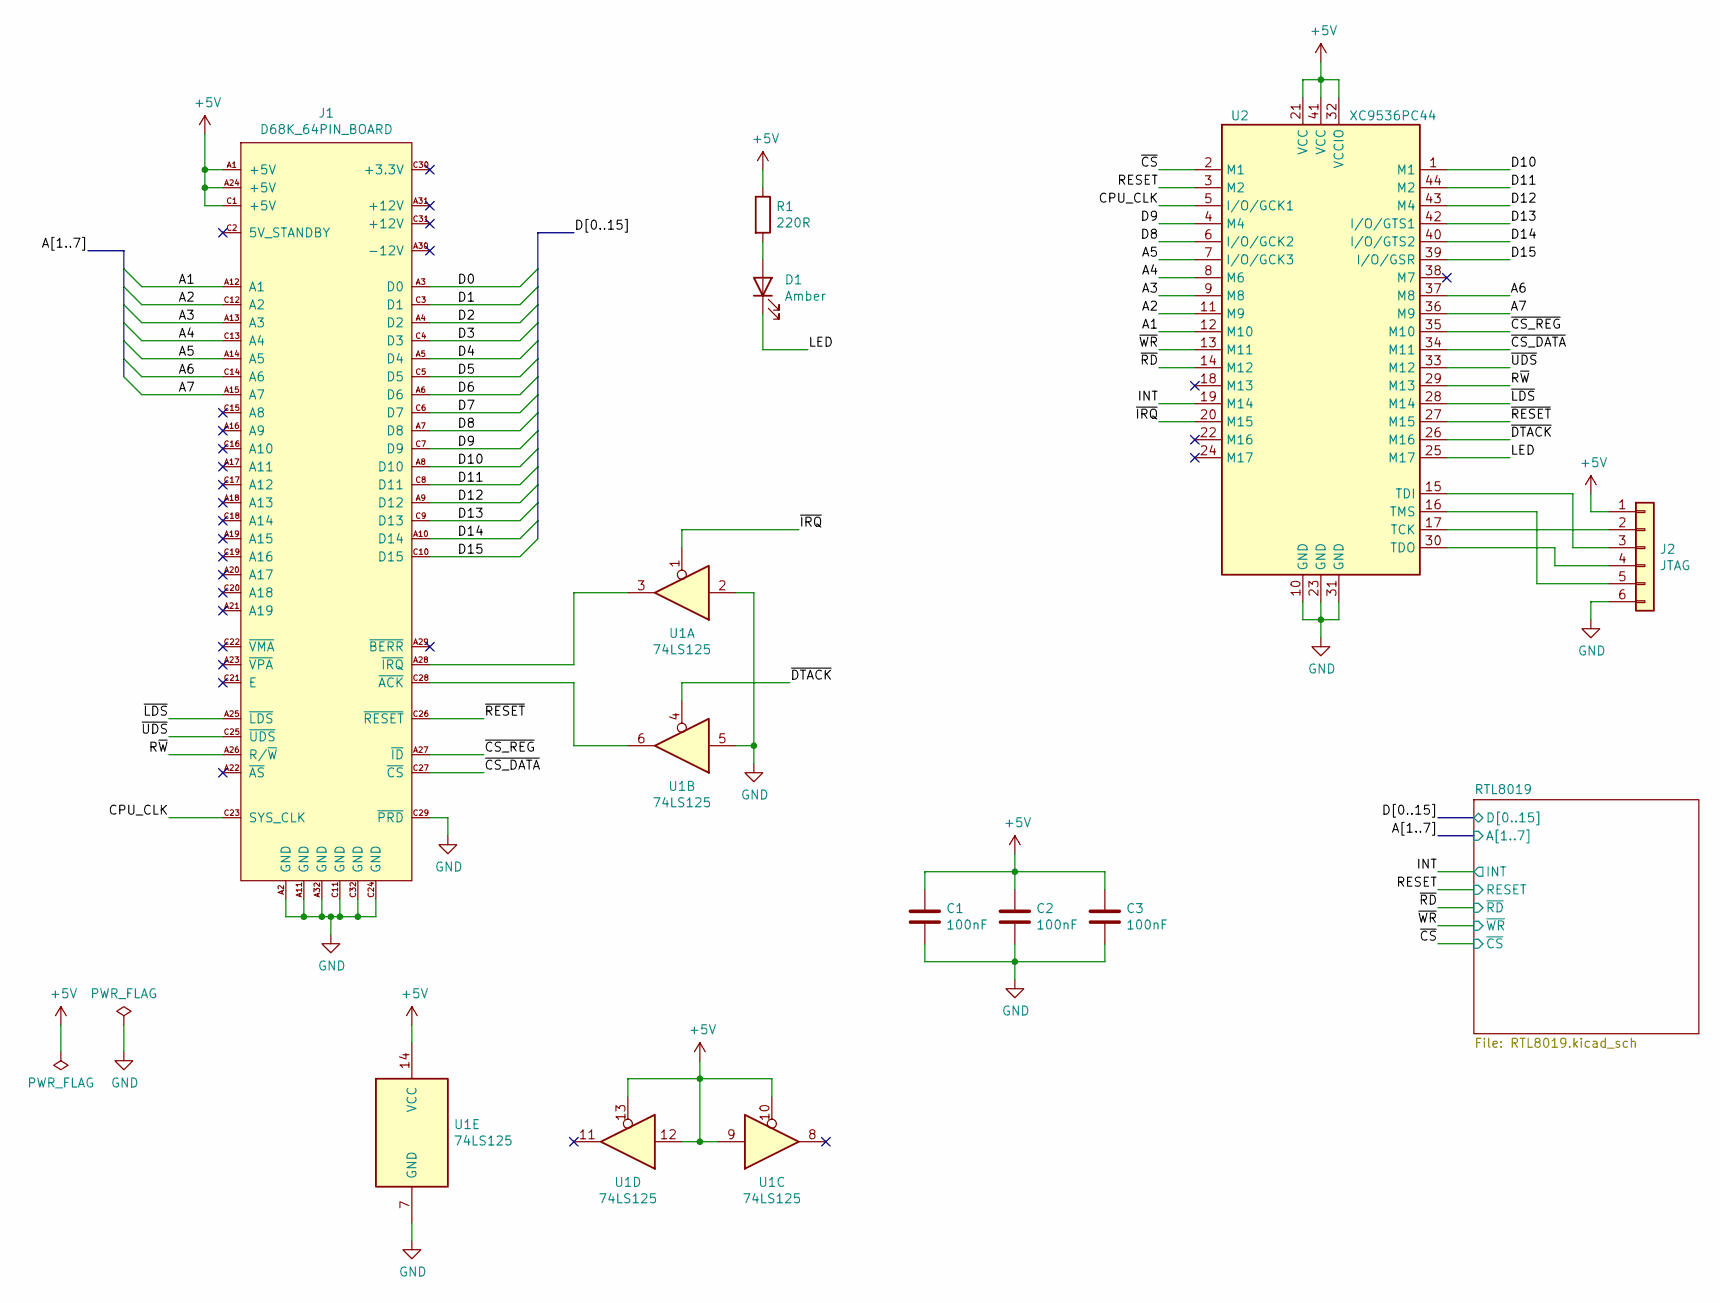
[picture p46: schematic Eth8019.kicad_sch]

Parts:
C1, C2, C3: 100nF; C_0805_2012Metric
D1: Amber; LED_1206_3216Metric
J1: D68K_64PIN_BOARD; DIN41612_C_2x32_Male_Horizontal_THT
J2: JTAG; PinHeader_1x06_P2.54mm_Vertical
R1: 220R; R_0805_2012Metric
U1: 74LS125; SO-14_5.3x10.2mm_P1.27mm
U2: XC9536PC44; PLCC-44

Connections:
+5V: C1.1, C2.1, C3.1, J1.A1 (+5V), J1.A24 (+5V), J1.C1 (+5V), J2.1, R1.1, U1.9, U1.10, U1.12, U1.13, U1.14 (VCC), U2.21 (VCC), U2.32 (VCCIO), U2.41 (VCC); also elsewhere on the board
/A1: J1.A12 (A1), U2.12 (M10); also elsewhere on the board
/A2: J1.C12 (A2), U2.11 (M9); also elsewhere on the board
/A3: J1.A13 (A3), U2.9 (M8); also elsewhere on the board
/A4: J1.C13 (A4), U2.8 (M6); also elsewhere on the board
/A5: J1.A14 (A5), U2.7 (I/O/GCK3); also elsewhere on the board
/A6: J1.C14 (A6), U2.37 (M8)
/A7: J1.A15 (A7), U2.36 (M9)
/CPU_CLK: J1.C23 (SYS_CLK), U2.5 (I/O/GCK1)
/D0: J1.A3 (D0); also elsewhere on the board
/D1: J1.C3 (D1); also elsewhere on the board
/D2: J1.A4 (D2); also elsewhere on the board
/D3: J1.C4 (D3); also elsewhere on the board
/D4: J1.A5 (D4); also elsewhere on the board
/D5: J1.C5 (D5); also elsewhere on the board
/D6: J1.A6 (D6); also elsewhere on the board
/D7: J1.C6 (D7); also elsewhere on the board
/D8: J1.A7 (D8), U2.6 (I/O/GCK2); also elsewhere on the board
/D9: J1.C7 (D9), U2.4 (M4); also elsewhere on the board
/D10: J1.A8 (D10), U2.1 (M1); also elsewhere on the board
/D11: J1.C8 (D11), U2.44 (M2); also elsewhere on the board
/D12: J1.A9 (D12), U2.43 (M4); also elsewhere on the board
/D13: J1.C9 (D13), U2.42 (I/O/GTS1); also elsewhere on the board
/D14: J1.A10 (D14), U2.40 (I/O/GTS2); also elsewhere on the board
/D15: J1.C10 (D15), U2.39 (I/O/GSR); also elsewhere on the board
/INT: U2.19 (M14); also elsewhere on the board
/LED: D1.1 (K), U2.25 (M17)
/RESET: U2.3 (M2); also elsewhere on the board
/R~W: J1.A26 (R/~W), U2.29 (M13)
/~CS_DATA: J1.C27 (~CS), U2.34 (M11)
/~CS_REG: J1.A27 (~ID), U2.35 (M10)
/~CS: U2.2 (M1); also elsewhere on the board
/~DTACK: U1.4, U2.26 (M16)
/~IRQ: U1.1, U2.20 (M15)
/~LDS: J1.A25 (~LDS), U2.28 (M14)
/~RD: U2.14 (M12); also elsewhere on the board
/~RESET: J1.C26 (~RESET), U2.27 (M15)
/~UDS: J1.C25 (~UDS), U2.33 (M12)
/~WR: U2.13 (M11); also elsewhere on the board
GND: C1.2, C2.2, C3.2, J1.A2 (GND), J1.A11 (GND), J1.A32 (GND), J1.C11 (GND), J1.C24 (GND), J1.C29 (~PRD), J1.C32 (GND), J2.6, U1.2, U1.5, U1.7 (GND), U2.10 (GND), U2.23 (GND), U2.31 (GND); also elsewhere on the board
unnamed: D1.2 (A), R1.2
unnamed: J1.A28 (~IRQ), U1.3
unnamed: J1.C28 (~ACK), U1.6
unnamed: J2.2, U2.17 (TCK)
unnamed: J2.3, U2.15 (TDI)
unnamed: J2.4, U2.30 (TDO)
unnamed: J2.5, U2.16 (TMS)

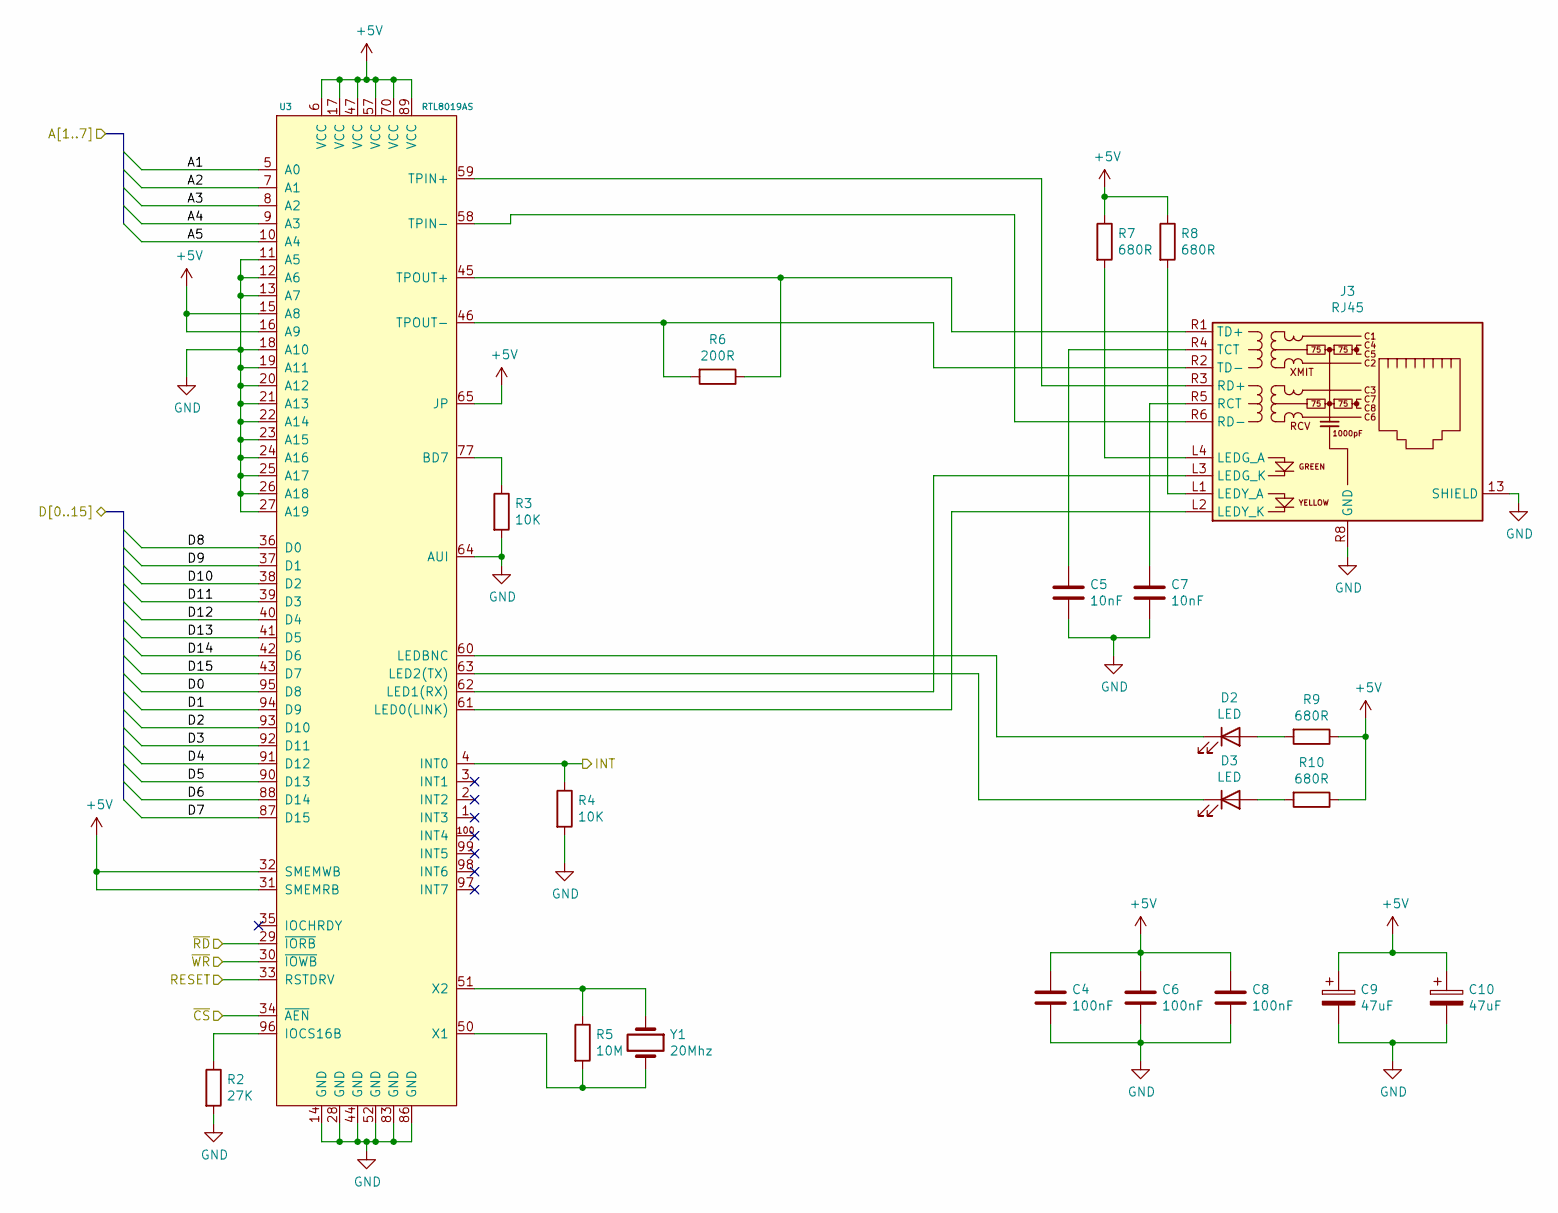
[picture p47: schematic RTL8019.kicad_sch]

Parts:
C4, C6, C8: 100nF; C_0805_2012Metric
C5, C7: 10nF; C_0805_2012Metric
C9, C10: 47uF; CP_Elec_4x5.7
D2, D3: LED; LED_1206_3216Metric
J3: RJ45; RJ45_Amphenol_RJMG1BD3B8K1ANR
R2: 27K; R_0805_2012Metric
R3, R4: 10K; R_0805_2012Metric
R5: 10M; R_0805_2012Metric
R6: 200R; R_0805_2012Metric
R7, R8, R9, R10: 680R; R_0805_2012Metric
U3: RTL8019AS
Y1: 20Mhz; Crystal_SMD_HC49-SD

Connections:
+5V: C4.1, C6.1, C8.1, C9.1, C10.1, R7.1, R8.1, R9.1, R10.1, U3.6 (VCC), U3.15 (A8), U3.16 (A9), U3.17 (VCC), U3.31 (SMEMRB), U3.32 (SMEMWB), U3.47 (VCC), U3.57 (VCC), U3.65 (JP), U3.70 (VCC), U3.89 (VCC); also elsewhere on the board
/A1: U3.5 (A0); also elsewhere on the board
/A2: U3.7 (A1); also elsewhere on the board
/A3: U3.8 (A2); also elsewhere on the board
/A4: U3.9 (A3); also elsewhere on the board
/A5: U3.10 (A4); also elsewhere on the board
/D0: U3.95 (D8); also elsewhere on the board
/D1: U3.94 (D9); also elsewhere on the board
/D2: U3.93 (D10); also elsewhere on the board
/D3: U3.92 (D11); also elsewhere on the board
/D4: U3.91 (D12); also elsewhere on the board
/D5: U3.90 (D13); also elsewhere on the board
/D6: U3.88 (D14); also elsewhere on the board
/D7: U3.87 (D15); also elsewhere on the board
/D8: U3.36 (D0); also elsewhere on the board
/D9: U3.37 (D1); also elsewhere on the board
/D10: U3.38 (D2); also elsewhere on the board
/D11: U3.39 (D3); also elsewhere on the board
/D12: U3.40 (D4); also elsewhere on the board
/D13: U3.41 (D5); also elsewhere on the board
/D14: U3.42 (D6); also elsewhere on the board
/D15: U3.43 (D7); also elsewhere on the board
/INT: R4.1, U3.4 (INT0); also elsewhere on the board
/RESET: U3.33 (RSTDRV); also elsewhere on the board
/~CS: U3.34 (~AEN); also elsewhere on the board
/~RD: U3.29 (~IORB); also elsewhere on the board
/~WR: U3.30 (~IOWB); also elsewhere on the board
GND: C4.2, C5.2, C6.2, C7.2, C8.2, C9.2, C10.2, J3.13 (SHIELD), J3.R8 (GND), R2.2, R3.2, R4.2, U3.11 (A5), U3.12 (A6), U3.13 (A7), U3.14 (GND), U3.18 (A10), U3.19 (A11), U3.20 (A12), U3.21 (A13), U3.22 (A14), U3.23 (A15), U3.24 (A16), U3.25 (A17), U3.26 (A18), U3.27 (A19), U3.28 (GND), U3.44 (GND), U3.52 (GND), U3.64 (AUI), U3.83 (GND), U3.86 (GND); also elsewhere on the board
unnamed: C5.1, J3.R4 (TCT)
unnamed: C7.1, J3.R5 (RCT)
unnamed: D2.1 (K), U3.60 (LEDBNC)
unnamed: D2.2 (A), R9.2
unnamed: D3.1 (K), U3.63 (LED2(TX))
unnamed: D3.2 (A), R10.2
unnamed: J3.L1 (LEDY_A), R8.2
unnamed: J3.L2 (LEDY_K), U3.61 (LED0(LINK))
unnamed: J3.L3 (LEDG_K), U3.62 (LED1(RX))
unnamed: J3.L4 (LEDG_A), R7.2
unnamed: J3.R1 (TD+), R6.1, U3.45 (TPOUT+)
unnamed: J3.R2 (TD-), R6.2, U3.46 (TPOUT-)
unnamed: J3.R3 (RD+), U3.59 (TPIN+)
unnamed: J3.R6 (RD-), U3.58 (TPIN-)
unnamed: R2.1, U3.96 (IOCS16B)
unnamed: R3.1, U3.77 (BD7)
unnamed: R5.1, U3.51 (X2), Y1.1
unnamed: R5.2, U3.50 (X1), Y1.2


Board: 4 copper layers, 100.0 x 62.5 mm, 30 parts (0 on the bottom side), 65 nets.

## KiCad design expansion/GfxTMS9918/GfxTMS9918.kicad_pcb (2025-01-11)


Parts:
C1, C2, C3: 100nF; C_Disc_D5.0mm_W2.5mm_P2.50mm
D1: Amber; LED_D5.0mm_FlatTop
J1: D68K_64PIN_BOARD; DIN41612_C_2x32_Male_Horizontal_THT
J2: JTAG; PinHeader_1x06_P2.54mm_Vertical
R1: 220R; R_Axial_DIN0207_L6.3mm_D2.5mm_P10.16mm_Horizontal
R5: 10k; R_Axial_DIN0207_L6.3mm_D2.5mm_P10.16mm_Horizontal
U1: 74LS125; DIP-14_W7.62mm_Socket
U2: XC9536PC44; PLCC-44_THT-Socket

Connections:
+5V: C1.1, C2.1, C3.1, J1.A1 (+5V), J1.A24 (+5V), J1.C1 (+5V), J2.1, R1.2, R5.1, U1.9, U1.10, U1.12, U1.13, U1.14 (VCC), U2.21 (VCC), U2.32 (VCCIO), U2.41 (VCC); also elsewhere on the board
/A1: J1.A12 (A1), U2.1 (M1); also elsewhere on the board
/A2: J1.C12 (A2), U2.2 (M1)
/A3: J1.A13 (A3), U2.3 (M2)
/A4: J1.C13 (A4), U2.44 (M2)
/A5: J1.A14 (A5), U2.43 (M4)
/A6: J1.C14 (A6), U2.42 (I/O/GTS1)
/A7: J1.A15 (A7), U2.40 (I/O/GTS2)
/CPU_CLK: J1.C23 (SYS_CLK), U2.5 (I/O/GCK1)
/D0: J1.A7 (D8), U2.13 (M11); also elsewhere on the board
/D1: J1.C7 (D9), U2.12 (M10); also elsewhere on the board
/D2: J1.A8 (D10), U2.11 (M9); also elsewhere on the board
/D3: J1.C8 (D11), U2.9 (M8); also elsewhere on the board
/D4: J1.A9 (D12), U2.8 (M6); also elsewhere on the board
/D5: J1.C9 (D13), U2.7 (I/O/GCK3); also elsewhere on the board
/D6: J1.A10 (D14), U2.6 (I/O/GCK2); also elsewhere on the board
/D7: J1.C10 (D15), U2.4 (M4); also elsewhere on the board
/LED: D1.1 (K), U2.19 (M14)
/R~W: J1.A26 (R/~W), U2.37 (M8)
/~CS_DATA: J1.C27 (~CS), U2.36 (M9)
/~CS_REG: J1.A27 (~ID), U2.35 (M10)
/~DTACK: U1.4, U2.33 (M12)
/~IRQ: R5.2, U1.1; also elsewhere on the board
/~LDS: J1.A25 (~LDS), U2.39 (I/O/GSR)
/~RESET: J1.C26 (~RESET), U2.34 (M11); also elsewhere on the board
/~UDS: J1.C25 (~UDS), U2.38 (M7)
/~VDPR: U2.28 (M14); also elsewhere on the board
/~VDPW: U2.29 (M13); also elsewhere on the board
GND: C1.2, C2.2, C3.2, J1.A2 (GND), J1.A11 (GND), J1.A32 (GND), J1.C11 (GND), J1.C24 (GND), J1.C29 (~PRD), J1.C32 (GND), J2.6, U1.2, U1.5, U1.7 (GND), U2.10 (GND), U2.23 (GND), U2.31 (GND); also elsewhere on the board
unnamed: D1.2 (A), R1.1
unnamed: J1.A28 (~IRQ), U1.3
unnamed: J1.C28 (~ACK), U1.6
unnamed: J2.2, U2.17 (TCK)
unnamed: J2.3, U2.15 (TDI)
unnamed: J2.4, U2.30 (TDO)
unnamed: J2.5, U2.16 (TMS)


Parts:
C4, C5: 22pF; C_Disc_D5.0mm_W2.5mm_P2.50mm
C6, C7, C8, C18, C20, C22: 100nF; C_Disc_D5.0mm_W2.5mm_P2.50mm
C9: 0.1uF; C_Disc_D5.0mm_W2.5mm_P2.50mm
C10: 220uF; CP_Radial_D5.0mm_P2.50mm
FB1: Ferrite_Bead; L_Axial_L6.6mm_D2.7mm_P10.16mm_Horizontal_Vishay_IM-2
J3: CompositeOut; KLPX0848A2RG
Q1: 2N3904; TO-92_Inline
R2: 470R; R_Axial_DIN0207_L6.3mm_D2.5mm_P10.16mm_Horizontal
R3, R4: 75R; R_Axial_DIN0207_L6.3mm_D2.5mm_P10.16mm_Horizontal
U3: 74LS04; DIP-14_W7.62mm_Socket
U4: TMS9918A; DIP-40_W15.24mm_Socket
U5, U6, U7: 74LS574; DIP-20_W7.62mm_Socket
U8: CY62256-70PC; DIP-28_W15.24mm
Y1: 10.7Mhz; Crystal_HC50_Vertical

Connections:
+5V: C6.1, C7.1, C8.1, C18.1, C20.1, C22.1, FB1.1, U3.14 (VCC), U4.33 (VSS), U5.20 (VCC), U6.20 (VCC), U7.20 (VCC), U8.28 (VCC); also elsewhere on the board
/A1: U4.13 (MODE); also elsewhere on the board
/D0: U4.17 (CD7(LSB)); also elsewhere on the board
/D1: U4.18 (CD6); also elsewhere on the board
/D2: U4.19 (CD5); also elsewhere on the board
/D3: U4.20 (CD4); also elsewhere on the board
/D4: U4.21 (CD3); also elsewhere on the board
/D5: U4.22 (CD2); also elsewhere on the board
/D6: U4.23 (CD1); also elsewhere on the board
/D7: U4.24 (CD0(MSB)); also elsewhere on the board
/VDP/AD0: U4.10 (AD0(MSB)), U5.2 (D0), U6.2 (D0), U7.2 (D0)
/VDP/AD1: U4.9 (AD1), U5.3 (D1), U6.3 (D1), U7.3 (D1)
/VDP/AD2: U4.8 (AD2), U5.4 (D2), U6.4 (D2), U7.4 (D2)
/VDP/AD3: U4.7 (AD3), U5.5 (D3), U6.5 (D3), U7.5 (D3)
/VDP/AD4: U4.6 (AD4), U5.6 (D4), U6.6 (D4), U7.6 (D4)
/VDP/AD5: U4.5 (AD5), U5.7 (D5), U6.7 (D5), U7.7 (D5)
/VDP/AD6: U4.4 (AD6), U5.8 (D6), U6.8 (D6), U7.8 (D6)
/VDP/AD7: U4.3 (AD7), U5.9 (D7), U6.9 (D7), U7.9 (D7)
/VDP/COL: U3.8, U6.11 (Cp)
/VDP/COMPOSITE: Q1.2 (B), R2.1, U4.36 (COMVID)
/VDP/ROW: U3.2, U5.11 (Cp)
/VDP/VA0: U5.18 (Q1), U8.10 (A0)
/VDP/VA1: U5.17 (Q2), U8.9 (A1)
/VDP/VA2: U5.16 (Q3), U8.8 (A2)
/VDP/VA3: U5.15 (Q4), U8.7 (A3)
/VDP/VA4: U5.14 (Q5), U8.21 (A10)
/VDP/VA5: U5.13 (Q6), U8.6 (A4)
/VDP/VA6: U5.12 (Q7), U8.5 (A5)
/VDP/VA7: U6.18 (Q1), U8.23 (A11)
/VDP/VA8: U6.17 (Q2), U8.4 (A6)
/VDP/VA9: U6.16 (Q3), U8.3 (A7)
/VDP/VA10: U6.15 (Q4), U8.24 (A9)
/VDP/VA11: U6.14 (Q5), U8.2 (A12)
/VDP/VA12: U6.13 (Q6), U8.25 (A8)
/VDP/VA13: U6.12 (Q7), U8.26 (A13)
/VDP/VD0: U4.32 (RD0(MSB)), U7.19 (Q0), U8.11 (Q0)
/VDP/VD1: U4.31 (RD1), U7.18 (Q1), U8.12 (Q1)
/VDP/VD2: U4.30 (RD2), U7.17 (Q2), U8.13 (Q2)
/VDP/VD3: U4.29 (RD3), U7.16 (Q3), U8.15 (Q3)
/VDP/VD4: U4.28 (RD4), U7.15 (Q4), U8.16 (Q4)
/VDP/VD5: U4.27 (RD5), U7.14 (Q5), U8.17 (Q5)
/VDP/VD6: U4.26 (RD6), U7.13 (Q6), U8.18 (Q6)
/VDP/VD7: U4.25 (RD7), U7.12 (Q7), U8.19 (Q7)
/VDP/VR~W: U3.11, U4.11 (R/~W), U7.1 (OE), U8.27 (~WE)
/VDP/V~RW: U3.10, U7.11 (Cp), U8.22 (~OE)
/VDP/~CAS: U3.3, U4.2 (~CAS), U8.20 (~CS)
/VDP/~RAS: U3.1, U4.1 (~RAS)
/~IRQ: U4.16 (~INT); also elsewhere on the board
/~RESET: U4.34 (~RESET); also elsewhere on the board
/~VDPR: U4.15 (~CSR); also elsewhere on the board
/~VDPW: U4.14 (~CSW); also elsewhere on the board
GND: C4.2, C5.2, C6.2, C7.2, C8.2, C9.1, C18.2, C20.2, C22.2, J3.1 (Ext), R2.2, R3.2, U3.7 (GND), U3.13, U4.12 (VSS), U5.1 (OE), U5.10 (GND), U6.1 (OE), U6.10 (GND), U7.10 (GND), U8.1 (A14), U8.14 (GND); also elsewhere on the board
unnamed: C4.1, U4.39 (XTAL1), Y1.1
unnamed: C5.1, U4.40 (XTAL2), Y1.2
unnamed: C9.2, FB1.2, Q1.3 (C)
unnamed: C10.1, R4.1
unnamed: C10.2, J3.2 (In)
unnamed: Q1.1 (E), R3.1, R4.2
unnamed: U3.4, U3.5
unnamed: U3.6, U3.9


Board: 4 copper layers, 100.0 x 100.0 mm, 33 parts (0 on the bottom side), 81 nets.

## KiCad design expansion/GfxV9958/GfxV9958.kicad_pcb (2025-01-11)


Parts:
C1, C2, C3: 100nF; C_Disc_D5.0mm_W2.5mm_P2.50mm
D1: Amber; LED_D5.0mm_FlatTop
J1: D68K_64PIN_BOARD; DIN41612_C_2x32_Male_Horizontal_THT
J2: JTAG; PinHeader_1x06_P2.54mm_Vertical
R1: 220R; R_Axial_DIN0207_L6.3mm_D2.5mm_P10.16mm_Horizontal
U1: 74LS125; DIP-14_W7.62mm_Socket
U2: XC9536PC44; PLCC-44_THT-Socket

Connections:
+5V: C1.1, C2.1, C3.1, J1.A1 (+5V), J1.A24 (+5V), J1.C1 (+5V), J2.1, R1.2, U1.9, U1.10, U1.12, U1.13, U1.14 (VCC), U2.21 (VCC), U2.32 (VCCIO), U2.41 (VCC); also elsewhere on the board
/A1: J1.A12 (A1), U2.1 (M1); also elsewhere on the board
/A2: J1.C12 (A2), U2.2 (M1); also elsewhere on the board
/A3: J1.A13 (A3), U2.3 (M2)
/A4: J1.C13 (A4), U2.44 (M2)
/A5: J1.A14 (A5), U2.43 (M4)
/A6: J1.C14 (A6), U2.42 (I/O/GTS1)
/A7: J1.A15 (A7), U2.40 (I/O/GTS2)
/CPU_CLK: J1.C23 (SYS_CLK), U2.5 (I/O/GCK1)
/D0: J1.A7 (D8), U2.13 (M11); also elsewhere on the board
/D1: J1.C7 (D9), U2.12 (M10); also elsewhere on the board
/D2: J1.A8 (D10), U2.11 (M9); also elsewhere on the board
/D3: J1.C8 (D11), U2.9 (M8); also elsewhere on the board
/D4: J1.A9 (D12), U2.8 (M6); also elsewhere on the board
/D5: J1.C9 (D13), U2.7 (I/O/GCK3); also elsewhere on the board
/D6: J1.A10 (D14), U2.6 (I/O/GCK2); also elsewhere on the board
/D7: J1.C10 (D15), U2.4 (M4); also elsewhere on the board
/LED: D1.1 (K), U2.19 (M14)
/R~W: J1.A26 (R/~W), U2.37 (M8)
/~CS_DATA: J1.C27 (~CS), U2.36 (M9)
/~CS_REG: J1.A27 (~ID), U2.35 (M10)
/~DTACK: U1.4, U2.33 (M12)
/~IRQ: U1.1; also elsewhere on the board
/~LDS: J1.A25 (~LDS), U2.39 (I/O/GSR)
/~RESET: J1.C26 (~RESET), U2.34 (M11); also elsewhere on the board
/~UDS: J1.C25 (~UDS), U2.38 (M7)
/~VDPR: U2.28 (M14); also elsewhere on the board
/~VDPW: U2.29 (M13); also elsewhere on the board
/~WAIT: U2.27 (M15); also elsewhere on the board
GND: C1.2, C2.2, C3.2, J1.A2 (GND), J1.A11 (GND), J1.A32 (GND), J1.C11 (GND), J1.C24 (GND), J1.C29 (~PRD), J1.C32 (GND), J2.6, U1.2, U1.5, U1.7 (GND), U2.10 (GND), U2.23 (GND), U2.31 (GND); also elsewhere on the board
unnamed: D1.2 (A), R1.1
unnamed: J1.A28 (~IRQ), U1.3
unnamed: J1.C28 (~ACK), U1.6
unnamed: J2.2, U2.17 (TCK)
unnamed: J2.3, U2.15 (TDI)
unnamed: J2.4, U2.30 (TDO)
unnamed: J2.5, U2.16 (TMS)


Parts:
C4, C5: 22pF; C_Disc_D5.0mm_W2.5mm_P2.50mm
C6, C7, C8: 100nF; C_Disc_D5.0mm_W2.5mm_P2.50mm
C9: 47pF; C_Disc_D5.0mm_W2.5mm_P2.50mm
C10: 5pF; C_Disc_D5.0mm_W2.5mm_P2.50mm
C11, C12, C13, C14, C15, C16, C17: 220uF; CP_Radial_D5.0mm_P2.50mm
J3: S-Video; MINI-DIN-4-TE_5749181-1
J4: Composite; KLPX0848A2RG
J5: RGB Video; MINI-DIN-8-TE_57492681
J6: Audio In; SWITCHCRAFT_35RAPC2BHN2; PARTREV L
Q1: 2N3904; TO-92_Inline
R2, R4, R5: 470R; R_Axial_DIN0207_L6.3mm_D2.5mm_P10.16mm_Horizontal
R3: 4M7; R_Axial_DIN0207_L6.3mm_D2.5mm_P10.16mm_Horizontal
R6, R7: 2K2; R_Axial_DIN0207_L6.3mm_D2.5mm_P10.16mm_Horizontal
R8: 2K61; R_Axial_DIN0207_L6.3mm_D2.5mm_P10.16mm_Horizontal
R9, R10, R11, R13, R14: 75R; R_Axial_DIN0207_L6.3mm_D2.5mm_P10.16mm_Horizontal
R12: 43R; R_Axial_DIN0207_L6.3mm_D2.5mm_P10.16mm_Horizontal
R15: 240R; R_Axial_DIN0207_L6.3mm_D2.5mm_P10.16mm_Horizontal
R16: 1K; R_Axial_DIN0207_L6.3mm_D2.5mm_P10.16mm_Horizontal
R17: 100R; R_Axial_DIN0207_L6.3mm_D2.5mm_P10.16mm_Horizontal
R18: 220R; R_Axial_DIN0207_L6.3mm_D2.5mm_P10.16mm_Horizontal
U3: 74HCT04; DIP-14_W7.62mm_Socket
U4: CXA2075M; SOP-24_7.5x15.4mm_P1.27mm
Y1: 4.4336161875Mhz; Crystal_HC50_Vertical

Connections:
+5V: J5.5, Q1.3 (C), R8.1, U3.14 (VCC), U4.12 (VCC), U4.19 (VCC); also elsewhere on the board
/VDP/B: C8.2, R2.1; also elsewhere on the board
/VDP/G: C7.2, R4.1; also elsewhere on the board
/VDP/R: C6.2, R5.1; also elsewhere on the board
/VDP/~CSYNC: R6.1, R16.2; also elsewhere on the board
/Video/AUDIO_L: J5.1, J6.1
/Video/AUDIO_R: J5.2, J6.3
/Video/BOUT: C13.2, J5.6
/Video/COUT: C16.2, J3.4
/Video/CVOUT: C14.2, J4.1 (In)
/Video/GOUT: C12.2, J5.7
/Video/PAL_CLK: C10.1, R7.1, U4.6 (SCIN)
/Video/ROUT: C11.2, J5.8
/Video/SYNCOUT: J5.3, R18.1
/Video/YOUT: C15.2, J3.3
GND: C4.2, C5.2, C9.2, C10.2, J3.1, J3.2, J4.2 (Ext), J5.4, J6.2, R2.2, R4.2, R5.2, R15.2, R17.2, U3.5, U3.7 (GND), U3.9, U3.11, U3.13, U4.1 (GND), U4.7 (NPIN), U4.24 (GND); also elsewhere on the board
unnamed: C4.1, R3.1, U3.1, Y1.2
unnamed: C5.1, R3.2, U3.2, U3.3, Y1.1
unnamed: C6.1, U4.2 (RIN)
unnamed: C7.1, U4.3 (GIN)
unnamed: C8.1, U4.4 (BIN)
unnamed: C9.1, R6.2, U4.10 (SYNCIN)
unnamed: C11.1, R9.1
unnamed: C12.1, R10.1
unnamed: C13.1, R11.1
unnamed: C14.1, R12.1, R15.1
unnamed: C15.1, R13.1
unnamed: C16.1, R14.1
unnamed: C17.1, Q1.1 (E), R17.1
unnamed: C17.2, R18.2
unnamed: Q1.2 (B), R16.1
unnamed: R7.2, U3.4
unnamed: R8.2, U4.17 (YTRAP)
unnamed: R9.2, U4.23 (ROUT)
unnamed: R10.2, U4.22 (GOUT)
unnamed: R11.2, U4.21 (BOUT)
unnamed: R12.2, U4.20 (CVOUT)
unnamed: R13.2, U4.16 (YOUT)
unnamed: R14.2, U4.15 (COUT)


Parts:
C18, C19, C20, C21, C22, C25, C26, C27: 100nF; C_Disc_D5.0mm_W2.5mm_P2.50mm
C23, C24: 22pF; C_Disc_D5.0mm_W2.5mm_P2.50mm
R19, R20, R21: 4K7; R_Axial_DIN0207_L6.3mm_D2.5mm_P10.16mm_Horizontal
U5, U6, U7, U8, U9, U10: 41464; DIP-18_W7.62mm_Socket
U11: V9958; DIP-64-V9958
Y2: 21.443Mhz; Crystal_HC50_Vertical

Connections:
+5V: C18.1, C19.1, C20.1, C21.1, C22.1, C25.1, C26.1, R19.1, R20.2, R21.2, U5.9 (VCC), U6.9 (VCC), U7.9 (VCC), U8.9 (VCC), U9.9 (VCC), U10.9 (VCC), U11.21 (VDD/DAC), U11.58 (VDD); also elsewhere on the board
/A1: U11.29 (MODE0); also elsewhere on the board
/A2: U11.28 (MODE1); also elsewhere on the board
/D0: U11.40 (D0); also elsewhere on the board
/D1: U11.39 (D1); also elsewhere on the board
/D2: U11.38 (D2); also elsewhere on the board
/D3: U11.37 (D3); also elsewhere on the board
/D4: U11.36 (D4); also elsewhere on the board
/D5: U11.35 (D5); also elsewhere on the board
/D6: U11.34 (D6); also elsewhere on the board
/D7: U11.32 (D7); also elsewhere on the board
/VDP/B: U11.24 (BLUE); also elsewhere on the board
/VDP/G: U11.22 (GREEN); also elsewhere on the board
/VDP/R: U11.23 (RED); also elsewhere on the board
/VDP/VA0: U5.14 (A0), U6.14 (A0), U7.14 (A0), U8.14 (A0), U9.14 (A0), U10.14 (A0), U11.49 (VA0)
/VDP/VA1: U5.13 (A1), U6.13 (A1), U7.13 (A1), U8.13 (A1), U9.13 (A1), U10.13 (A1), U11.50 (VA1)
/VDP/VA2: U5.12 (A2), U6.12 (A2), U7.12 (A2), U8.12 (A2), U9.12 (A2), U10.12 (A2), U11.51 (VA2)
/VDP/VA3: U5.11 (A3), U6.11 (A3), U7.11 (A3), U8.11 (A3), U9.11 (A3), U10.11 (A3), U11.52 (VA3)
/VDP/VA4: U5.8 (A4), U6.8 (A4), U7.8 (A4), U8.8 (A4), U9.8 (A4), U10.8 (A4), U11.53 (VA4)
/VDP/VA5: U5.7 (A5), U6.7 (A5), U7.7 (A5), U8.7 (A5), U9.7 (A5), U10.7 (A5), U11.54 (VA5)
/VDP/VA6: U5.6 (A6), U6.6 (A6), U7.6 (A6), U8.6 (A6), U9.6 (A6), U10.6 (A6), U11.55 (VA6)
/VDP/VA7: U5.10 (A7), U6.10 (A7), U7.10 (A7), U8.10 (A7), U9.10 (A7), U10.10 (A7), U11.56 (VA7)
/VDP/VD0: U5.2 (D0), U6.2 (D0), U7.2 (D0), U11.41 (VD0)
/VDP/VD1: U5.3 (D1), U6.3 (D1), U7.3 (D1), U11.42 (VD1)
/VDP/VD2: U5.15 (D2), U6.15 (D2), U7.15 (D2), U11.43 (VD2)
/VDP/VD3: U5.17 (D3), U6.17 (D3), U7.17 (D3), U11.44 (VD3)
/VDP/VD4: U8.2 (D0), U9.2 (D0), U10.2 (D0), U11.45 (VD4)
/VDP/VD5: U8.3 (D1), U9.3 (D1), U10.3 (D1), U11.46 (VD5)
/VDP/VD6: U8.15 (D2), U9.15 (D2), U10.15 (D2), U11.47 (VD6)
/VDP/VD7: U8.17 (D3), U9.17 (D3), U10.17 (D3), U11.48 (VD7)
/VDP/VR~W: U5.4 (~WE), U6.4 (~WE), U7.4 (~WE), U8.4 (~WE), U9.4 (~WE), U10.4 (~WE), U11.57 (R/~W)
/VDP/~CAS0: U5.16 (~CAS), U8.16 (~CAS), U11.61 (~CAS0)
/VDP/~CAS1: U6.16 (~CAS), U9.16 (~CAS), U11.60 (~CAS1)
/VDP/~CASX: U7.16 (~CAS), U10.16 (~CAS), U11.59 (~CASX)
/VDP/~CSYNC: U11.6 (~CSYNC); also elsewhere on the board
/VDP/~RAS: U5.5 (~RAS), U6.5 (~RAS), U7.5 (~RAS), U8.5 (~RAS), U9.5 (~RAS), U10.5 (~RAS), U11.62 (~RAS)
/~IRQ: R19.2, U11.25 (~INT); also elsewhere on the board
/~RESET: U11.9 (~RESET); also elsewhere on the board
/~VDPR: U11.31 (~CSR); also elsewhere on the board
/~VDPW: U11.30 (~CSW); also elsewhere on the board
/~WAIT: U11.26 (~WAIT); also elsewhere on the board
GND: C18.2, C19.2, C20.2, C21.2, C22.2, C23.2, C24.2, C25.2, C26.2, C27.2, U5.1 (~OE), U5.18 (VSS), U6.1 (~OE), U6.18 (VSS), U7.1 (~OE), U7.18 (VSS), U8.1 (~OE), U8.18 (VSS), U9.1 (~OE), U9.18 (VSS), U10.1 (~OE), U10.18 (VSS), U11.1 (GND), U11.20 (GND/DAC); also elsewhere on the board
unnamed: C23.1, U11.63 (XTAL1), Y2.1
unnamed: C24.1, U11.64 (XTAL2), Y2.2
unnamed: C27.1, U11.33 (VBB)
unnamed: R20.1, U11.4 (~VRESET)
unnamed: R21.1, U11.27 (~HRESET)

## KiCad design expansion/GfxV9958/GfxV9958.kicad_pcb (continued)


Board: 2 copper layers, 147.5 x 100.0 mm, 69 parts (0 on the bottom side), 100 nets.

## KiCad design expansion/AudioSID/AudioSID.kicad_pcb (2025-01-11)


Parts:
C1, C2, C3, C5, C6: 100nF; C_Disc_D5.0mm_W2.5mm_P2.50mm
C4, C7: 10uF; CP_Radial_D5.0mm_P2.50mm
D1: Amber; LED_D5.0mm
J1: D68K_64PIN_BOARD; DIN41612_C_2x32_Male_Horizontal_THT
J2: POT1; PinHeader_1x04_P2.54mm_Vertical
J3: POT2; PinHeader_1x04_P2.54mm_Vertical
J4: Audio Out; SWITCHCRAFT_35RAPC2BHN2; PARTREV L
J5: Audio In; SWITCHCRAFT_35RAPC2BHN2; PARTREV L
J6: JTAG; PinHeader_1x06_P2.54mm_Vertical
Q603: 2N7000; TO-92_Inline
R1: 220R; R_Axial_DIN0207_L6.3mm_D2.5mm_P10.16mm_Horizontal
R606: 1M; R_Axial_DIN0207_L6.3mm_D2.5mm_P10.16mm_Horizontal
R609: 10K; R_Axial_DIN0207_L6.3mm_D2.5mm_P10.16mm_Horizontal
U1: L7809; TO-220-3_Horizontal_TabDown
U2: XC9536PC44; PLCC-44_THT-Socket

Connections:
/A1: J1.A12 (A1), U2.1 (M1); also elsewhere on the board
/A2: J1.C12 (A2), U2.2 (M1); also elsewhere on the board
/A3: J1.A13 (A3), U2.3 (M2); also elsewhere on the board
/A4: J1.C13 (A4), U2.44 (M2); also elsewhere on the board
/A5: J1.A14 (A5), U2.43 (M4); also elsewhere on the board
/A6: J1.C14 (A6), U2.42 (I/O/GTS1)
/A7: J1.A15 (A7), U2.40 (I/O/GTS2)
/CLK_1MHZ: U2.27 (M15); also elsewhere on the board
/CPU_CLK: J1.C23 (SYS_CLK), U2.5 (I/O/GCK1)
/D0: J1.A7 (D8), U2.13 (M11); also elsewhere on the board
/D1: J1.C7 (D9), U2.12 (M10); also elsewhere on the board
/D2: J1.A8 (D10), U2.11 (M9); also elsewhere on the board
/D3: J1.C8 (D11), U2.9 (M8); also elsewhere on the board
/D4: J1.A9 (D12), U2.8 (M6); also elsewhere on the board
/D5: J1.C9 (D13), U2.7 (I/O/GCK3); also elsewhere on the board
/D6: J1.A10 (D14), U2.6 (I/O/GCK2); also elsewhere on the board
/D7: J1.C10 (D15), U2.4 (M4); also elsewhere on the board
/DTACK: U2.33 (M12); also elsewhere on the board
/LED: D1.1 (K), U2.19 (M14)
/R~W: J1.A26 (R/~W), U2.37 (M8); also elsewhere on the board
/SID1/AUDIO_IN_L: J5.3; also elsewhere on the board
/SID1/AUDIO_OUT_L: J4.3; also elsewhere on the board
/SID1/POT_Y1: J2.2; also elsewhere on the board
/SID2/AUDIO_IN_R: J5.2; also elsewhere on the board
/SID2/AUDIO_OUT_R: J4.2; also elsewhere on the board
/SID2/POT_X2: J3.3; also elsewhere on the board
/SID2/POT_Y2: J3.2; also elsewhere on the board
/~CS_DATA: J1.C27 (~CS), U2.36 (M9)
/~CS_REG: J1.A27 (~ID), U2.35 (M10)
/~CS_SID1: U2.29 (M13); also elsewhere on the board
/~CS_SID2: U2.28 (M14); also elsewhere on the board
/~LDS: J1.A25 (~LDS), U2.39 (I/O/GSR)
/~RESET: J1.C26 (~RESET), U2.34 (M11); also elsewhere on the board
/~UDS: J1.C25 (~UDS), U2.38 (M7)
GND: C1.2, C2.2, C3.2, C4.2, C5.2, C6.2, C7.2, J1.A2 (GND), J1.A11 (GND), J1.A32 (GND), J1.C11 (GND), J1.C24 (GND), J1.C29 (~PRD), J1.C32 (GND), J2.1, J3.1, J4.1, J5.1, J6.6, U1.2 (GND), U2.10 (GND), U2.23 (GND), U2.31 (GND); also elsewhere on the board
unnamed: D1.2 (A), R1.1
unnamed 36: J1.C28 (~ACK); also elsewhere on the board
unnamed: J6.2, U2.17 (TCK)
unnamed: J6.3, U2.15 (TDI)
unnamed: J6.4, U2.30 (TDO)
unnamed: J6.5, U2.16 (TMS)


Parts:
C4, C5, C6: 100nF; C_Disc_D5.0mm_W2.5mm_P2.50mm
C7, C9, C11, C15: 1nF; C_Disc_D5.0mm_W2.5mm_P2.50mm
C8, C13: 22nF; C_Disc_D5.0mm_W2.5mm_P2.50mm
C10, C14: 470pf; C_Disc_D5.0mm_W2.5mm_P2.50mm
C12, C17: 10uF; CP_Radial_D5.0mm_P2.50mm
C16: 470pF; C_Disc_D5.0mm_W2.5mm_P2.50mm
J7: SIDSEL_1; PinHeader_1x03_P2.54mm_Vertical
J8: SIDSEL_2; PinHeader_1x03_P2.54mm_Vertical
J9: SIDSEL_3; PinHeader_1x03_P2.54mm_Vertical
J10: SIDSEL_4; PinHeader_1x03_P2.54mm_Vertical
J11: SIDSEL_5; PinHeader_1x03_P2.54mm_Vertical
Q1: BC547; TO-92_Inline
R2, R4: 1K; R_Axial_DIN0207_L6.3mm_D2.5mm_P10.16mm_Horizontal
R3: 10K; R_Axial_DIN0207_L6.3mm_D2.5mm_P10.16mm_Horizontal
RV1: 10K; Potentiometer_Alps_RK163_Dual_Horizontal
U3: DIP-28_W15.24mm_Socket

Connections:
/A1: U3.9 (A0); also elsewhere on the board
/A2: U3.10 (A1); also elsewhere on the board
/A3: U3.11 (A2); also elsewhere on the board
/A4: U3.12 (A3); also elsewhere on the board
/A5: U3.13 (A4); also elsewhere on the board
/CLK_1MHZ: U3.6 (CLK); also elsewhere on the board
/D0: U3.15 (D0); also elsewhere on the board
/D1: U3.16 (D1); also elsewhere on the board
/D2: U3.17 (D2); also elsewhere on the board
/D3: U3.18 (D3); also elsewhere on the board
/D4: U3.19 (D4); also elsewhere on the board
/D5: U3.20 (D5); also elsewhere on the board
/D6: U3.21 (D6); also elsewhere on the board
/D7: U3.22 (D7); also elsewhere on the board
/R~W: U3.7 (R/~W); also elsewhere on the board
/SID1/AUDIO_IN_L: C12.2; also elsewhere on the board
/SID1/AUDIO_OUT_L: C17.2; also elsewhere on the board
/SID1/POT_Y1: C9.1, U3.23 (POT_Y); also elsewhere on the board
/~CS_SID1: U3.8 (~CS); also elsewhere on the board
/~RESET: U3.5 (~RES); also elsewhere on the board
GND: C4.2, C5.2, C6.2, C7.2, C9.2, C11.2, C15.2, R2.2, R4.2, RV1.3, U3.14 (GND); also elsewhere on the board
unnamed: J7.2, U3.28 (VDD)
unnamed: C10.1, J8.1
unnamed: J8.2, U3.3 (CAP2A)
unnamed: C8.1, J8.3
unnamed: C10.2, J9.1
unnamed: J9.2, U3.4 (CAP2B)
unnamed: C8.2, J9.3
unnamed: C14.1, J10.1
unnamed: J10.2, U3.1 (CAP1A)
unnamed: C13.1, J10.3
unnamed: C14.2, J11.1
unnamed: J11.2, U3.2 (CAP1B)
unnamed: C13.2, J11.3
unnamed: C15.1, C16.1, Q1.2 (B), R3.2
unnamed: C16.2, C17.1, Q1.3 (E), R4.1
unnamed: R2.1, R3.1, RV1.2
unnamed: RV1.1, U3.27 (AUDIO_OUT)
unnamed: C11.1, C12.1, U3.26 (EXT_IN)

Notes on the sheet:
1-2: 6581 2-3: 8580


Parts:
C18, C19, C20: 100nF; C_Disc_D5.0mm_W2.5mm_P2.50mm
C21, C23, C25, C29: 1nF; C_Disc_D5.0mm_W2.5mm_P2.50mm
C22, C27: 22nF; C_Disc_D5.0mm_W2.5mm_P2.50mm
C24, C28: 470pf; C_Disc_D5.0mm_W2.5mm_P2.50mm
C26, C31: 10uF; CP_Radial_D5.0mm_P2.50mm
C30: 470pF; C_Disc_D5.0mm_W2.5mm_P2.50mm
J12: SIDSEL_1; PinHeader_1x03_P2.54mm_Vertical
J13: SIDSEL_2; PinHeader_1x03_P2.54mm_Vertical
J14: SIDSEL_3; PinHeader_1x03_P2.54mm_Vertical
J15: SIDSEL_4; PinHeader_1x03_P2.54mm_Vertical
J16: SIDSEL_5; PinHeader_1x03_P2.54mm_Vertical
Q2: BC547; TO-92_Inline
R5, R7: 1K; R_Axial_DIN0207_L6.3mm_D2.5mm_P10.16mm_Horizontal
R6: 10K; R_Axial_DIN0207_L6.3mm_D2.5mm_P10.16mm_Horizontal
RV1: 10K; Potentiometer_Alps_RK163_Dual_Horizontal
U4: DIP-28_W15.24mm_Socket

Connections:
/A1: U4.9 (A0); also elsewhere on the board
/A2: U4.10 (A1); also elsewhere on the board
/A3: U4.11 (A2); also elsewhere on the board
/A4: U4.12 (A3); also elsewhere on the board
/A5: U4.13 (A4); also elsewhere on the board
/CLK_1MHZ: U4.6 (CLK); also elsewhere on the board
/D0: U4.15 (D0); also elsewhere on the board
/D1: U4.16 (D1); also elsewhere on the board
/D2: U4.17 (D2); also elsewhere on the board
/D3: U4.18 (D3); also elsewhere on the board
/D4: U4.19 (D4); also elsewhere on the board
/D5: U4.20 (D5); also elsewhere on the board
/D6: U4.21 (D6); also elsewhere on the board
/D7: U4.22 (D7); also elsewhere on the board
/R~W: U4.7 (R/~W); also elsewhere on the board
/SID2/AUDIO_IN_R: C26.2; also elsewhere on the board
/SID2/AUDIO_OUT_R: C31.2; also elsewhere on the board
/SID2/POT_X2: C21.1, U4.24 (POT_X); also elsewhere on the board
/SID2/POT_Y2: C23.1, U4.23 (POT_Y); also elsewhere on the board
/~CS_SID2: U4.8 (~CS); also elsewhere on the board
/~RESET: U4.5 (~RES); also elsewhere on the board
GND: C18.2, C19.2, C20.2, C21.2, C23.2, C25.2, C29.2, R5.2, R7.2, RV1.6, U4.14 (GND); also elsewhere on the board
unnamed: J12.2, U4.28 (VDD)
unnamed: C24.1, J13.1
unnamed: J13.2, U4.3 (CAP2A)
unnamed: C22.1, J13.3
unnamed: C24.2, J14.1
unnamed: J14.2, U4.4 (CAP2B)
unnamed: C22.2, J14.3
unnamed: C28.1, J15.1
unnamed: J15.2, U4.1 (CAP1A)
unnamed: C27.1, J15.3
unnamed: C28.2, J16.1
unnamed: J16.2, U4.2 (CAP1B)
unnamed: C27.2, J16.3
unnamed: C29.1, C30.1, Q2.2 (B), R6.2
unnamed: C30.2, C31.1, Q2.3 (E), R7.1
unnamed: R5.1, R6.1, RV1.5
unnamed: RV1.4, U4.27 (AUDIO_OUT)
unnamed: C25.1, C26.1, U4.26 (EXT_IN)

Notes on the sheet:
1-2: 6581 2-3: 8580

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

Board: 4 copper layers, 100.0 x 100.0 mm, 69 parts (0 on the bottom side), 81 nets.

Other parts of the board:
C32, C35: 10uF; CP_Radial_D5.0mm_P2.50mm
C33, C34: 100nF; C_Disc_D5.0mm_W2.5mm_P2.50mm
Q3: 2N7000; TO-92_Inline
R8: 1M; R_Axial_DIN0207_L6.3mm_D2.5mm_P10.16mm_Horizontal
R9: 10K; R_Axial_DIN0207_L6.3mm_D2.5mm_P10.16mm_Horizontal

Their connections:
/DTACK: Q3.2 (G), R9.2; also elsewhere on the board
GND: C32.2, C33.2, C34.2, C35.2, Q3.1 (S), R9.1; also elsewhere on the board
unnamed 36: Q3.3 (D), R8.2; also elsewhere on the board

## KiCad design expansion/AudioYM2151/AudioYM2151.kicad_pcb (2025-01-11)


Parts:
C1, C2, C3, C5, C6: 100nF; C_Disc_D5.0mm_W2.5mm_P2.50mm
C4, C7: 10uF; CP_Radial_D5.0mm_P2.50mm
D1: LED; LED_D5.0mm
J1: JTAG; PinHeader_1x06_P2.54mm_Vertical
J2: D68K_64PIN_BOARD; DIN41612_C_2x32_Male_Horizontal_THT
L1, L2: 22uH; L_Radial_D8.7mm_P5.00mm_Fastron_07HCP
Q1: 2N4403; TO-92
R2: 10K; R_Axial_DIN0207_L6.3mm_D2.5mm_P10.16mm_Horizontal
R3: 220R; R_Axial_DIN0207_L6.3mm_D2.5mm_P10.16mm_Horizontal
U1: XC95144XL-TQ100; TQFP-100_14x14mm_P0.5mm
U2: 74LS125; DIP-14_W7.62mm_Socket

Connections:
+3V3: J1.1, J2.C30 (+3.3V), U1.5 (VCCINT), U1.26 (VCCIO), U1.38 (VCCIO), U1.51 (VCCIO), U1.57 (VCCINT), U1.88 (VCCIO), U1.98 (VCCINT)
+5V: C1.1, C2.1, C3.1, J2.A1 (+5V), J2.A24 (+5V), J2.C1 (+5V), Q1.1 (E), U2.9, U2.10, U2.12, U2.13, U2.14 (VCC); also elsewhere on the board
+12V: C4.1, C5.1, J2.A31 (+12V), J2.C31 (+12V), L1.2
+12VA: C6.1, C7.1, L1.1; also elsewhere on the board
/A1: J2.A12 (A1), U1.34; also elsewhere on the board
/A2: J2.C12 (A2), U1.33
/A3: J2.A13 (A3), U1.32
/A4: J2.C13 (A4), U1.30
/A5: J2.A14 (A5), U1.29
/A6: J2.C14 (A6), U1.28
/A7: J2.A15 (A7), U1.27 (I/O/GCK3)
/CS_DATA: J2.C27 (~CS), U1.19
/CS_REG: J2.A27 (~ID), U1.20
/CS_YMCLK: U1.16; also elsewhere on the board
/D0: J2.A3 (D0), U1.58
/D1: J2.C3 (D1), U1.59
/D2: J2.A4 (D2), U1.55
/D3: J2.C4 (D3), U1.56
/D4: J2.A5 (D4), U1.53
/D5: J2.C5 (D5), U1.54
/D6: J2.A6 (D6), U1.50
/D7: J2.C6 (D7), U1.52
/D8: J2.A7 (D8), U1.46; also elsewhere on the board
/D9: J2.C7 (D9), U1.49; also elsewhere on the board
/D10: J2.A8 (D10), U1.40; also elsewhere on the board
/D11: J2.C8 (D11), U1.41; also elsewhere on the board
/D12: J2.A9 (D12), U1.37; also elsewhere on the board
/D13: J2.C9 (D13), U1.39; also elsewhere on the board
/D14: J2.A10 (D14), U1.35; also elsewhere on the board
/D15: J2.C10 (D15), U1.36; also elsewhere on the board
/LED: R2.1, U1.66
/R~W: J2.A26 (R/~W), U1.25
/SPI_CLK: U1.17; also elsewhere on the board
/SPI_DO: U1.18; also elsewhere on the board
/SYS_CLK: J2.C23 (SYS_CLK), U1.22 (I/O/GCK1)
/~CS_YM: U1.92; also elsewhere on the board
/~DTACK: U1.12, U2.4
/~IRQ: U2.1; also elsewhere on the board
/~LDS: J2.A25 (~LDS), U1.23 (I/O/GCK2)
/~RD_YM: U1.91; also elsewhere on the board
/~RESET: J2.C26 (~RESET), U1.13; also elsewhere on the board
/~UDS: J2.C25 (~UDS), U1.24
/~WR_YM: U1.90; also elsewhere on the board
GND: C1.2, C2.2, C3.2, C4.2, C5.2, J1.6, J2.A2 (GND), J2.A11 (GND), J2.A32 (GND), J2.C11 (GND), J2.C24 (GND), J2.C29 (~PRD), J2.C32 (GND), L2.2, R3.2, U1.21 (GND), U1.31 (GND), U1.44 (GND), U1.62 (GND), U1.69 (GND), U1.75 (GND), U1.84 (GND), U1.100 (GND), U2.2, U2.5, U2.7 (GND); also elsewhere on the board
GNDA: C6.2, C7.2, L2.1; also elsewhere on the board
unnamed: D1.2 (A), Q1.3 (C)
unnamed: D1.1 (K), R3.1
unnamed: J1.2, U1.48 (TCK)
unnamed: J1.3, U1.45 (TDI)
unnamed: J1.4, U1.83 (TDO)
unnamed: J1.5, U1.47 (TMS)
unnamed: J2.C28 (~ACK), U2.6
unnamed: J2.A28 (~IRQ), U2.3
unnamed: Q1.2 (B), R2.2


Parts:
C8, C16, C17: 10nF; C_Disc_D5.0mm_W2.5mm_P2.50mm
C9, C10, C11, C12, C14: 100nF; C_Disc_D5.0mm_W2.5mm_P2.50mm
C13: 10uF; CP_Radial_D5.0mm_P2.50mm
C15: 1nF; C_Disc_D5.0mm_W2.5mm_P2.50mm
C18: 220uF; CP_Radial_D5.0mm_P2.50mm
R4: 560R; R_Axial_DIN0207_L6.3mm_D2.5mm_P10.16mm_Horizontal
RN1: 4K7; R_Array_SIP6
U3: LTC6903; MSOP-8_3x3mm_P0.65mm
U4: YM2151; DIP-24_W15.24mm_Socket
U5: YM3012; DIP-16_W7.62mm_Socket
U6: TL064; DIP-14_W7.62mm_Socket

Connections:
+5V: C8.1, C9.1, C10.1, C11.1, C12.1, C14.1, C18.1, RN1.1 (common), U3.7 (OE), U3.8 (VCC), U4.22 (VCC), U5.1 (VCC), U6.4 (V+); also elsewhere on the board
/A1: U4.4 (A0); also elsewhere on the board
/Amplifier/YM_AUDIO_L: U6.1, U6.2 (-); also elsewhere on the board
/Amplifier/YM_AUDIO_R: U6.6 (-), U6.7; also elsewhere on the board
/CS_YMCLK: U3.4 (~SEN/ADR); also elsewhere on the board
/D8: U4.10 (D0); also elsewhere on the board
/D9: U4.12 (D1); also elsewhere on the board
/D10: U4.13 (D2); also elsewhere on the board
/D11: U4.14 (D3); also elsewhere on the board
/D12: U4.15 (D4); also elsewhere on the board
/D13: U4.16 (D5); also elsewhere on the board
/D14: U4.17 (D6); also elsewhere on the board
/D15: U4.18 (D7); also elsewhere on the board
/SPI_CLK: U3.3 (SCK); also elsewhere on the board
/SPI_DO: U3.2 (SDI); also elsewhere on the board
/YM2151/BC: C15.2, U5.14 (BC), U6.13 (-)
/YM2151/CH1: C16.2, U5.9 (CH-1), U6.3 (+)
/YM2151/CH2: C17.2, U5.10 (CH-2), U6.5 (+)
/YM2151/MP: C15.1, U5.13 (MP), U6.14
/YM2151/RB: C13.1, U5.15 (RB), U6.12 (+)
/~CS_YM: U4.7 (~CS); also elsewhere on the board
/~IRQ: RN1.2 (R1), U4.2 (~IRQ); also elsewhere on the board
/~RD_YM: U4.6 (~RD); also elsewhere on the board
/~RESET: U4.3 (~IC), U5.7 (~ICL); also elsewhere on the board
/~WR_YM: U4.5 (~WR); also elsewhere on the board
GND: C8.2, C11.2, C12.2, C14.2, U3.1 (GND), U4.1 (GND), U4.11 (GND), U5.3 (GND); also elsewhere on the board
GNDA: C9.2, C10.2, C13.2, C16.1, C17.1, C18.2, U5.8 (AGND), U5.16 (AGND), U6.11 (V-); also elsewhere on the board
unnamed: RN1.3 (R2), U4.21 (SO), U5.4 (SD)
unnamed: RN1.4 (R3), U4.20 (SH1), U5.6 (SAM1)
unnamed: RN1.5 (R4), U4.19 (SH2), U5.5 (SAM2)
unnamed: RN1.6 (R5), U4.23 (1), U5.2 (CLK1)
unnamed: U3.6 (CLK), U4.24 (M)
unnamed: R4.2, U5.11 (COM)
unnamed: U5.12 (ToBUFF), U6.10 (+)
unnamed: R4.1, U6.8, U6.9 (-)

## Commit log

2021-03-22 Created new project for Y Ddraig
    [yddraig.kicad_pcb, yddraig.sch]
2021-03-22 Working on Y Ddraig schematic
    [CPU.sch, power.sch, yddraig.sch]
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2021-03-23 CPLD and some logic added
    [CPU.sch, decode.sch, yddraig.sch]
2021-03-23 Removed NOT gate from CPU sheet, use CPLD
    [CPU.sch, decode.sch, power.sch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]
2021-03-23 Added Serial, Keybaord and parallel peripherals
    [CPU.sch, decode.sch, peripherals.sch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]
2021-03-23 Added ddraig-libs to repo instead of having a submodule
    [RJMG1BD3B8K1ANR--3DModel-STEP-56544.STEP, c-5535090-9-a-3d.stp, din_41612_female_c-64act2_5-2.stp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]
2021-03-23 Added some decoupling and links for subsheet
    [CPU.sch, decode.sch, peripherals.sch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]
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2021-03-24 Initial version of the schematic imported
    [CPU.sch, decode.sch, dram.sch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]
2021-03-24 ERC errors fixed
    [CPU.sch, decode.sch, dram.sch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]
2021-03-24 Removed unused RTC sheet
    [rtc.sch]
2021-03-24 Change DIN pin names to uppercase
    [expansionbus.sch]
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2021-03-25 Some small fixes
    [CPU.sch, expansionbus.sch, ide.sch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]
2021-03-25 Initial board layout done
    [ATX_te-1-1775099-3-e-3d.stp, CPU.sch, MiniDin_6way.stp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]
2021-03-25 Added a MC68030 symbol
    [yddraig.kicad_pcb]
2021-04-16 Expansion slot pinout updated
    [expansionbus.sch]
2021-04-17 Updated expansion bus use
    [CPU.sch, decode.sch, expansionbuffers.sch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]
2021-04-21 Started routing the main board
    [yddraig.kicad_pcb]
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2021-05-13 Y Ddraig board routing finished
    [PLCC44 Socket.igs]
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2021-05-17 Changed schematic to more match proteus version
    [CPU.sch, decode.sch, dram.sch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]
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2021-05-19 Some changes on the 3d viewer
    [ACH.STEP, AIUR-02H.STEP, AIUR-16.STEP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]
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2021-05-20 Added floppy disk header
    [FloppyDiskController.sch]
2021-05-21 Working on FDC Schematic
    [FloppyDiskController.sch]
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2021-05-23 Board layout in progress
    [FloppyDiskController.kicad_pcb, FloppyDiskController.sch]
2021-05-24 Floppy Disk Controller layout finished
    [FloppyDiskController.kicad_pcb, c-0770997-01-c-3d.stp, plcc44_p1-27_l16-66_w16-66.stp]
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2021-05-25 Started working on a 6809 design
    [Audio.sch, CPU.sch, Decode.sch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]
2021-05-26 Some more work on 6809
    [Video.sch]
2021-05-27 Added VDP, Audio and FPGA to 6809 design
    [Audio.sch, CPU.sch, Decode.sch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]
2021-05-28 Added project files for YM2151 and YM6212
    [Audio.sch, AudioYM2151.kicad_pcb, AudioYM2151.sch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]
2021-05-28 Started on Ym2612 design
    [Audio.sch, AudioYM6212.sch]
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2021-06-11 Made some changes to the YM2151 board
    [Audio.sch]
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2021-06-18 Added YM2151 amp to seperate sheet
    [ADPCM.sch, Amplifier.sch, AudioYM2151.sch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]
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2021-06-27 Added Eth8019 and updated page description for all projects
    [Amplifier.sch, Audio.sch, AudioYM2151.sch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]
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2021-07-02 Corrected name from YM6212 -> YM2612
    [Amplifier.sch, Audio.sch, AudioYM2612.kicad_pcb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]
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2021-07-28 Corrected resistor value from 2K81 -> 2K61
    [GfxV9958.kicad_pcb, Video.sch]
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2021-08-24 Fix for POWER and RESET switches
    [CPU.sch, power.sch]
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2021-08-24 Working on the pinning of the FPGA pins
    [FPGA.sch, GfxFPGAS3.kicad_pcb, GfxFPGAS3.sch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]
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2021-08-29 Made some changes to the 68030 and 6809 designs
    [BusBuffer.sch, CPU.sch, DRAM.sch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]
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2021-08-29 Some minor changes to the FPGA video board
    [FPGA.sch]
2021-08-29 More work done on the 68030 and 6809 boards
    [Audio.sch, BusBuffer.sch, CPU.sch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]
2021-08-29 FIx for 74HCT74 power symbol connections
    [CPU.sch, ide.sch, power.sch]
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2021-08-31 Some more changes to the 030 and 6809 designs
    [CPU.sch, DRAM.sch, Serial.sch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]
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2021-09-06 TMS9918 - Updated crystal capacitor values to 22pF
    [GfxTMS9918.kicad_pcb, VDP.sch]
2021-09-06 AUdioYM2612 - Added missing voltage divider for 2.5V
    [Audio.sch, AudioYM2612.kicad_pcb]
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2021-09-07 Updated IO on some of the child sheets
    [DRAM.sch, DRAMBuffers.sch, Decode.sch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]
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2021-09-14 GfxTMS9918 Fixed video output and missing D7 track. Updated CPLD code
    [GfxTMS9918.kicad_pcb, GfxTMS9918.sch, VDP.sch]
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2021-09-18 ddraig09: initial design done
    Need to be reviewed and decode on additional uses for IO but passed DRC
    [Audio.sch, CPU.sch, Decode.sch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]
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2021-10-06 ddraig030: Some additional changes to address decoding logic
    [Decode.sch, yddraig030.sch]
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2021-10-09 ddraig030: trying to fix the DRC errors
    [BusBuffer.sch, CPU.sch, DRAM.sch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]
2021-10-09 ddraig09: fix for the TSC pin
    [CPU.sch]
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2021-12-01 yddraig: Updated power circuit to use through hole parts rather than SMD
    [power.sch]
2021-12-01 yddraig: Moves the DTACK signal from the IRQ line on expansion slot 3
    Close #2
    [expansionbus.sch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]
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2021-12-06 yddraig030: changed expansion bus and RAM and ROM to 16 bit
    [CPU.sch, ExpansionBuffers.sch, ExpansionBus.sch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]
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2022-05-29 Fix for CXA PAL issue and more
    [Audio.kicad_sch, Buffers.kicad_sch, CPU.kicad_sch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]
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2022-06-08 Reworking FPGA VGA Card Pinout
    [Buffers.kicad_sch, FPGA.kicad_sch, GfxFPGAS3.kicad_pcb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]
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2022-08-01 yddraig030: Fixed ERC check errors
    [CPU.kicad_sch, DRAM.kicad_sch, DRAMBuffers.kicad_sch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]
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2022-08-12 yddraig030: Fixed missing SRAM
    [DRAM.kicad_sch, Expansion.kicad_sch, IDE Interface.kicad_sch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]
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2022-09-04 Fix for BUSENABLE not placable on FPGA
    [FPGA.kicad_sch, GfxFPGAS3.kicad_pcb]
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2022-12-03 Moved images to correct folder
    [FPGA.kicad_sch, GfxFPGA-32.kicad_pcb, GfxFPGA-32.kicad_sch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]
2023-01-14 Updated Logic ICs to specific SMD parts and footprints in schematic
    [BusBuffer.kicad_sch, Decode.kicad_sch, Keyboard.kicad_sch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]
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2023-01-27 Considering adding second sound channel to 6809 board
    [Audio.kicad_sch, CPU.kicad_sch, Decode.kicad_sch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]
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2023-02-04 Small updates to 6809 and 030 board, remove old files
    [ADPCM.sch, Amplifier.sch, Audio.kicad_sch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]
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2023-02-06 Updated gerbers with missing bottom solder mask
    [yddraig030-B_Cu.gbl, yddraig030-B_Mask.gbs, yddraig030-B_Paste.gbp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]
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2023-09-09 Initial version of a Dual SID audio card
    [AudioSID.kicad_pcb, AudioSID.kicad_sch, Power.kicad_sch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]
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2023-09-16 Started laying out PCB for SID audio board
    [AudioSID.kicad_pcb, AudioSID.kicad_sch, Buffers.kicad_sch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]
2023-09-16 Changed oscillator frequency on the keyboard controller
    [Keyboard.kicad_sch]
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2024-01-20 All projects updated to KiCAD 7 format files
    [Amplifier.kicad_sch, Audio.kicad_sch, AudioFPGA.kicad_pcb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]
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2024-05-17 Fixed some AudioYM2151V2 DRC issues
    [Amplifier.kicad_sch, AudioYM2151V2.kicad_sch, YM2151.kicad_sch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]
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2025-01-11 Repository clean up, removed untested projects
    Updated files to latest KiCAD version
    Removed untested 68030 design files
    Removed 6809 board, several design flaws
    Removed untested expansion boards
    [Amplifier.kicad_sch, Audio.kicad_sch, AudioSID.kicad_pcb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]
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2026-04-16 Fixed incorrect pin name
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2026-05-26 Added missing symbols and CAD files
    [SJ2-35813B-SMT-TR.step]
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2026-09-09 Added a couple of parts for audio card
    [lumberg_0105_05.stp]
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

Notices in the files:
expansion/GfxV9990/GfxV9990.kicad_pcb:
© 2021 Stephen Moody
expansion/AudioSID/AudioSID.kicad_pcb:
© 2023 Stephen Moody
